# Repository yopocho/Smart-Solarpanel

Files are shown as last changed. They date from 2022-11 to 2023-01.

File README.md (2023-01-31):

# Smart Solarpanel Controller

This project contains the files for a device and housing that enables a solarpanel to control the MPPT of ten different sections of the same solarpanel to improve efficiency in partially-shaded conditions. This device is a self-contained version of a prototype S. Zahra Mirbagheri Golroodbari created for their PhD [dissertation](https://www.mdpi.com/1996-1073/11/1/250) on creating a better and more efficient solarpanel, in which she has succeded. 

On behalf of the Univerity of Utrecht, created at the Univeristy of Applied Sciences Utrecht.

## Electronics

### PCB

The PCB is designed in Kicad. It's rated to handle atleast 10A of current with an MPP output of 29,41V (221.75W).

To find the MPPT for each of the ten sections a dedicated LTM4611EV Buck-converter with INA226 and supporting components are used. They are controlled by a central STM32F103C8T6 microcontroller.

Programming the microcontroller is done through SWD via the provided 2.54mm pitch pins besides it.

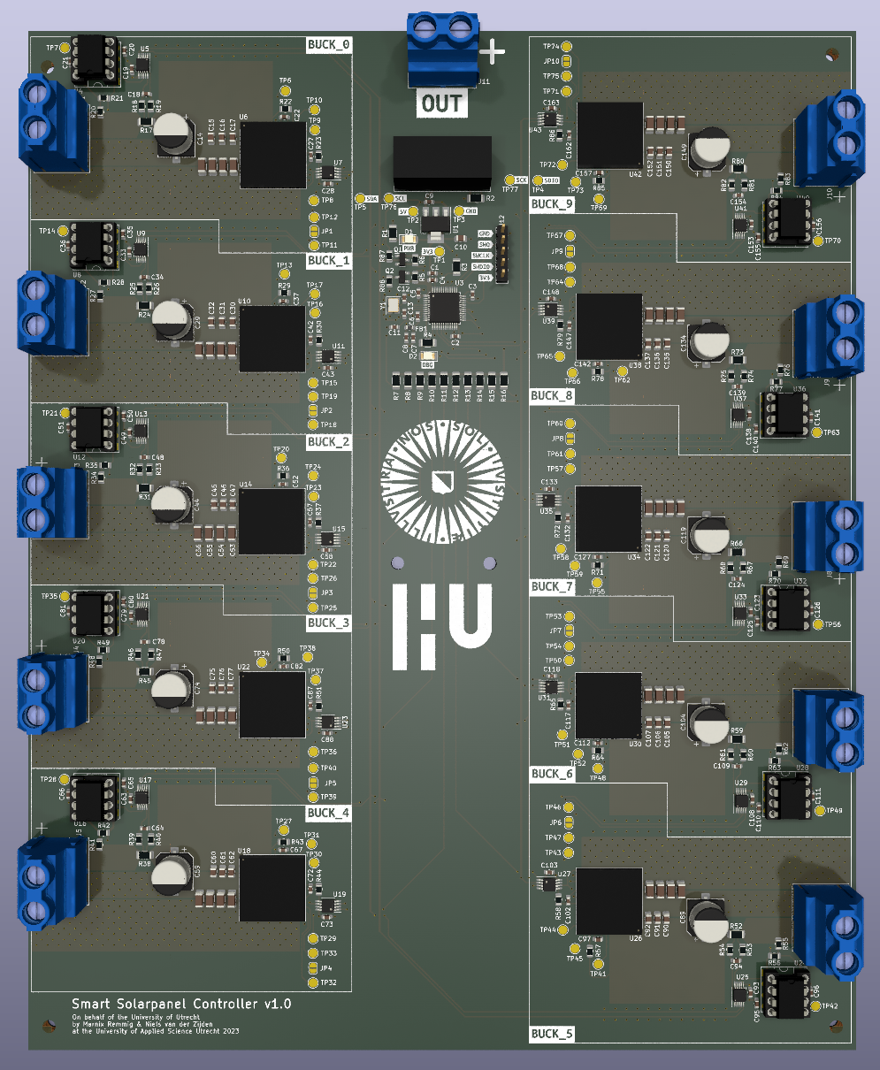
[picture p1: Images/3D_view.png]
3D Model of the PCB


### Firmware

The code for the microcontroller has at this moment not been written yet. The pinout and external crystal were determined by using CubeIDE as a tool to assist in layout, which can be used further to develop the firmware for the device.

## Mechanicals

The mechanical enclosure was calculated using Solidworks Simulation software to make sure it does not exceed the maximum allowed temperature of 70 degrees Celsius. For this reason the enclosure is made out of aluminium.

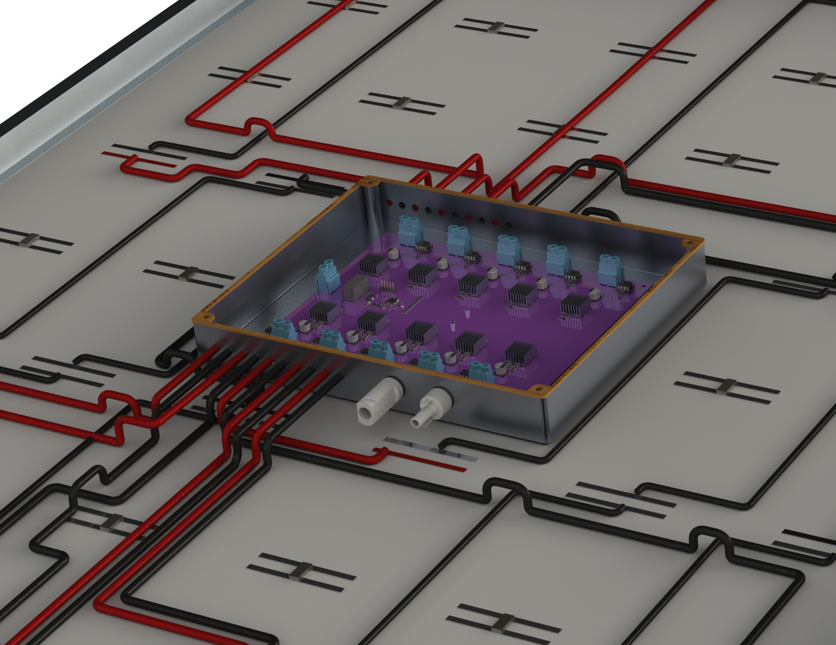
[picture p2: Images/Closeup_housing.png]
3D model closeup of the PCB housing


### Connections

The electrical connections are made using copper wire, as it is cheap and the resistance is low. Since a lot more of the cells are wired in parallel than in a conventional panel, thicker wire must be used to keep the losses under 2%. The wires are routed to the central PCB, where the MPP is calculated and everything is controlled.

The enclosure is waterproof with an IP65 rating. It is glued to the back of the panel. Several panels can be connected in series using standard connectors.

## Use

The provided files can be used as template to retrofit a classic solarpanel into a smart solarpanel. The PCB can be ordered and assembled, after which it can be fitted to the solar panel in the custom housing. 

## Built With

* [Kicad](https://www.kicad.org/) - EDA
* [STM32CubeIDE](https://www.st.com/en/development-tools/stm32cubeide.html) - IDE 
* [SolidWorks](https://www.solidworks.com/) - CAD

## Authors

* **Niels van der Zijden** - [Yopocho](https://github.com/yopocho)
* **Marnix Remmig** 
* **Teun Drijfhout** 
* **Silas Witmond** 

## License

This project is licensed under the MIT License

## Acknowledgments

* **Dr. Sara Mirbagheri Golroodbari** - Commisioner
* **Joost Kouijzer** - Group supervisor during this project
* **Marcel** - For letting our group use his lab during the project

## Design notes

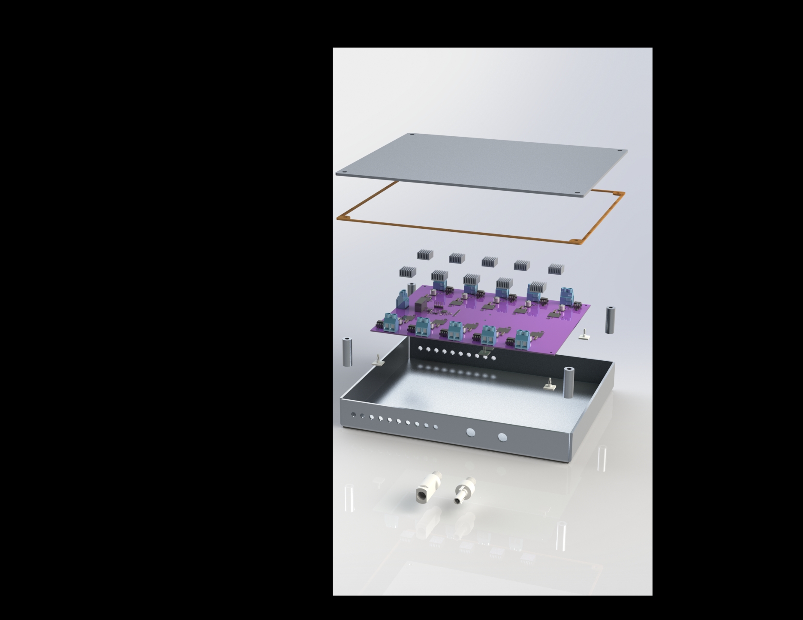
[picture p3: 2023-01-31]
Images/Housing exploded view.JPG

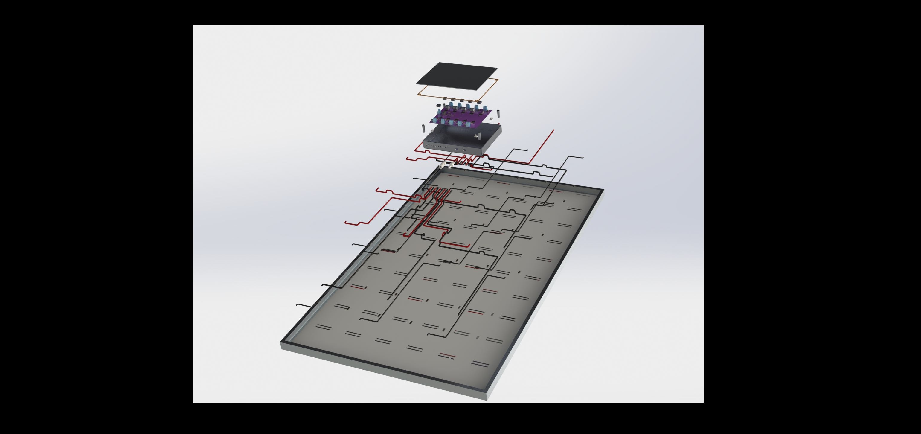
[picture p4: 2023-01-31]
Images/Exploded whole panel.JPG

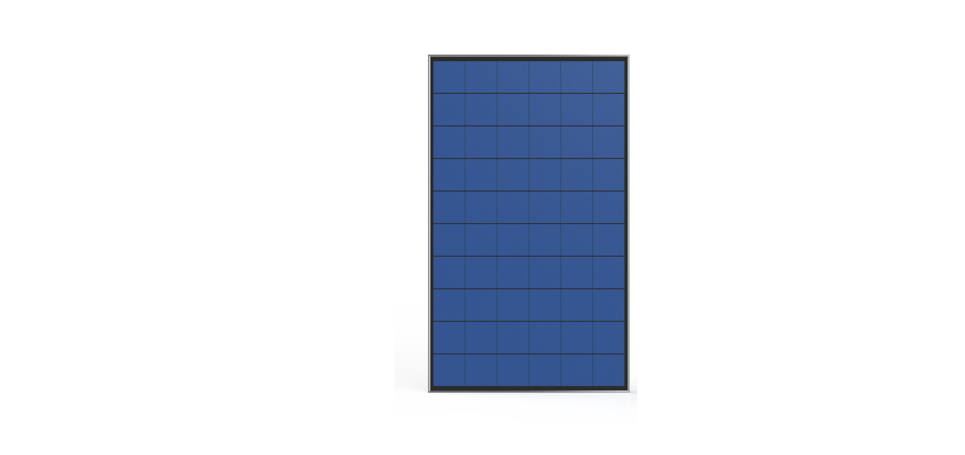
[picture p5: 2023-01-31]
Images/Front of panel.png

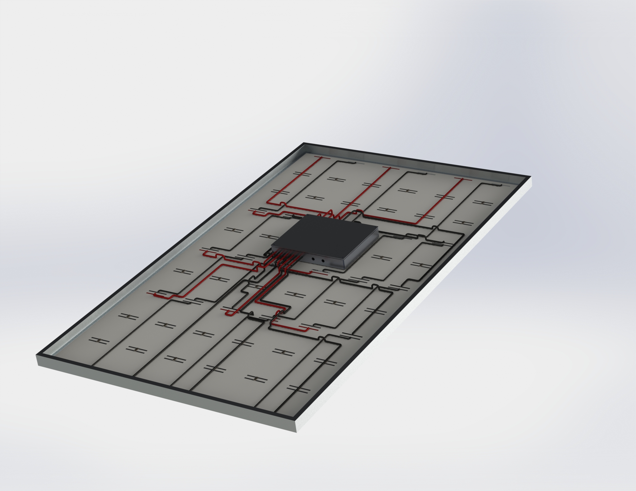
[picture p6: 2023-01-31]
Images/Whole panel.JPG

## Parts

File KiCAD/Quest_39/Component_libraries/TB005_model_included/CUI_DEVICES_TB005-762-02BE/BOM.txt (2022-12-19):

3DX_CUI_DEVICES_Supplier: CUI Devices
3DX_CUI_DEVICES_Part Number: TB005-762-02BE
3DX_CUI_DEVICES_Description: 2~24 Poles, Screw Type, Horizontal, 7.62 Pitch, 26-10 (AWG), Terminal Block Connector

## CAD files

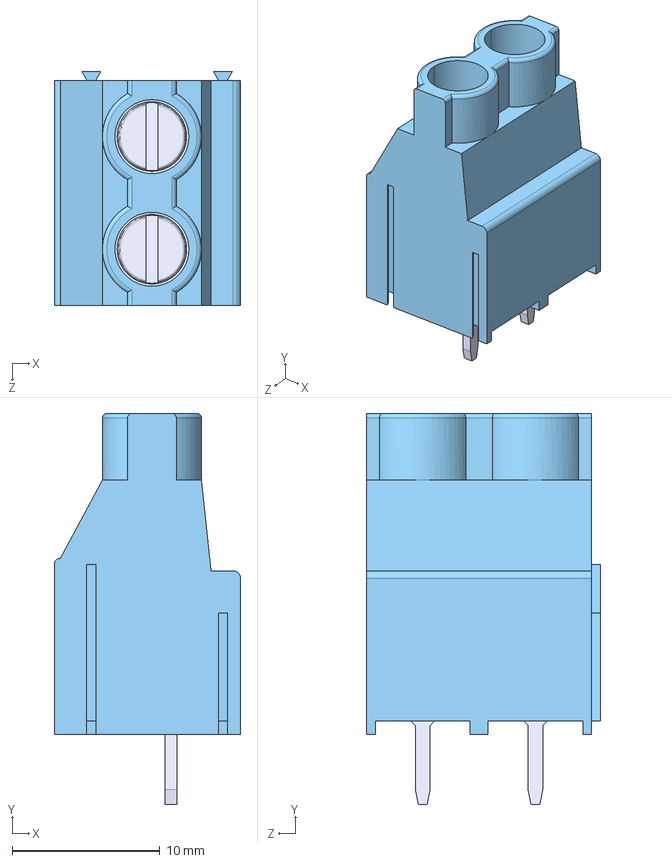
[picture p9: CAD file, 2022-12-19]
KiCAD/Quest_39/Component_libraries/TB005_model_included/CUI_DEVICES_TB005-762-02BE/CUI_DEVICES_TB005-762-02BE.step
12.6 x 26.5 x 15.8 mm

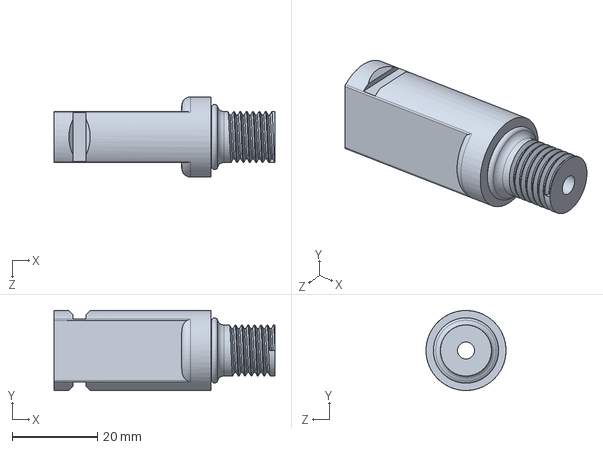
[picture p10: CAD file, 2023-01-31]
SolidWorks/MC4 female connector.SLDPRT
51.9 x 18.8 x 18.8 mm

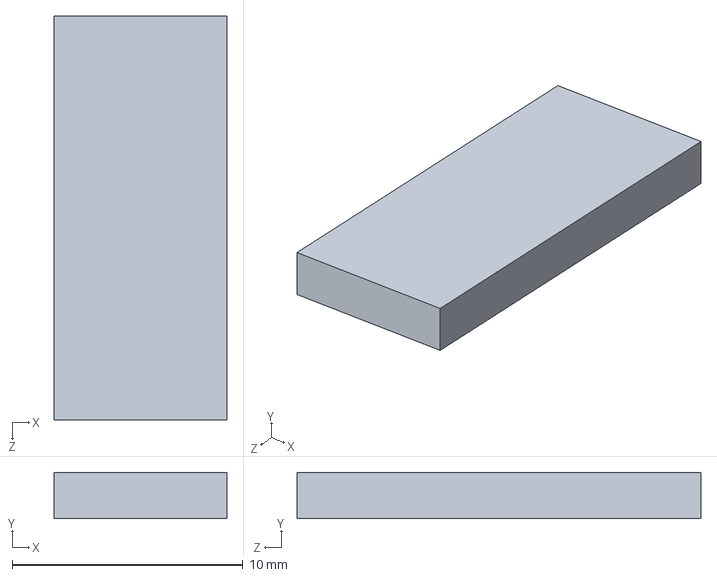
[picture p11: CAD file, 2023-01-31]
SolidWorks/17.5x7.5x2.SLDPRT
7.50 x 2.00 x 17.5 mm

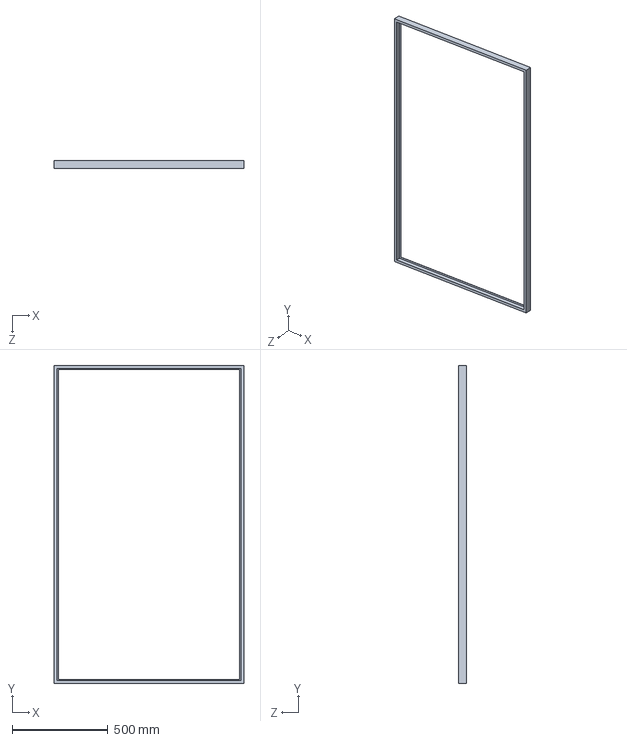
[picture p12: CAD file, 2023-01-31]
SolidWorks/frame van het paneel.SLDPRT
990.0 x 1658.0 x 42.0 mm

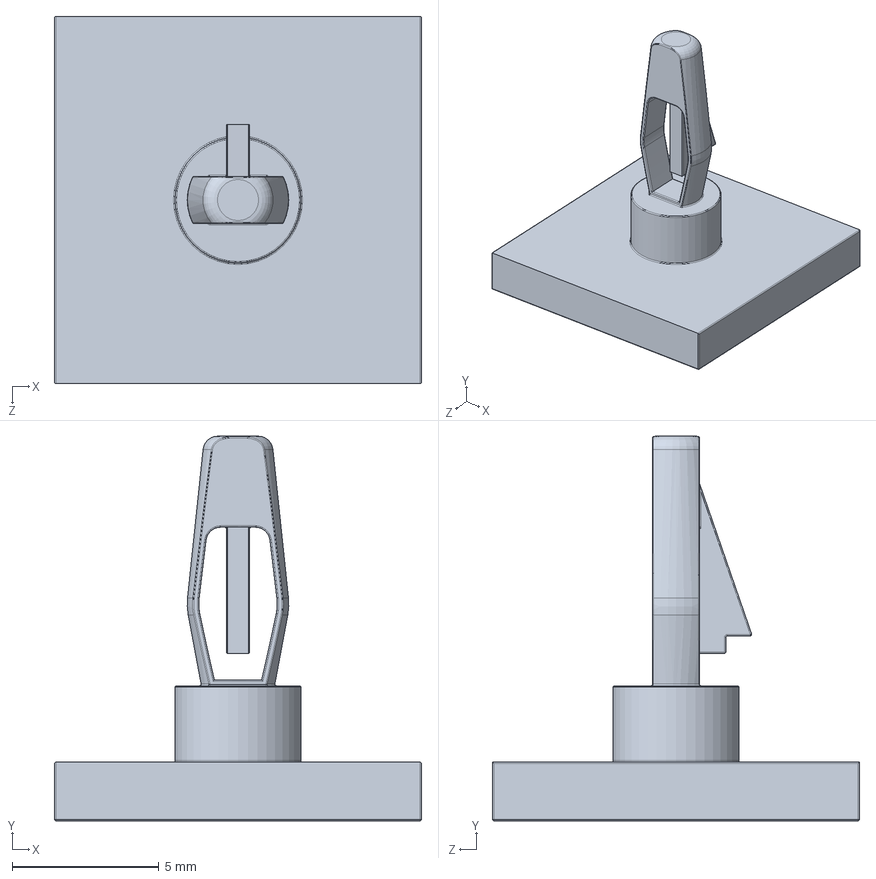
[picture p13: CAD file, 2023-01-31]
SolidWorks/pcb steun.SLDPRT
12.5 x 13.1 x 12.5 mm

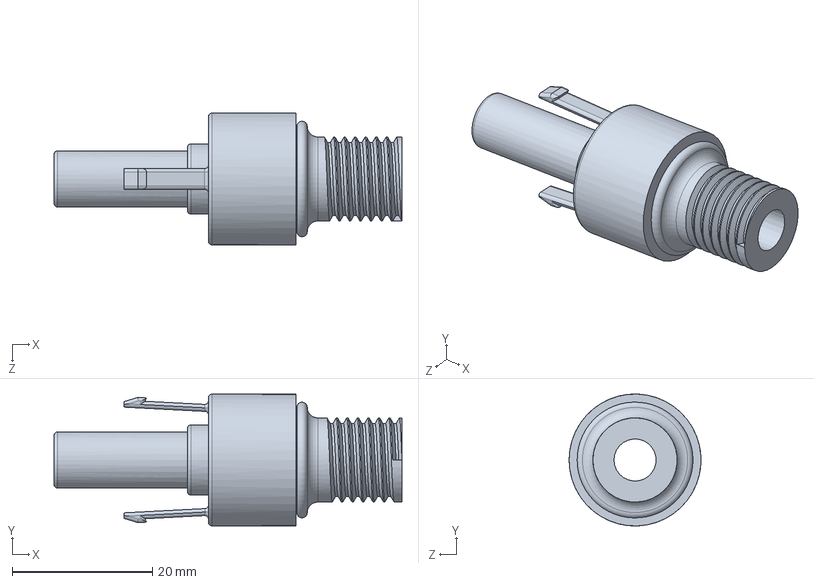
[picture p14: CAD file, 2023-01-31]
SolidWorks/MC4 male connector.SLDPRT
49.6 x 18.8 x 18.8 mm

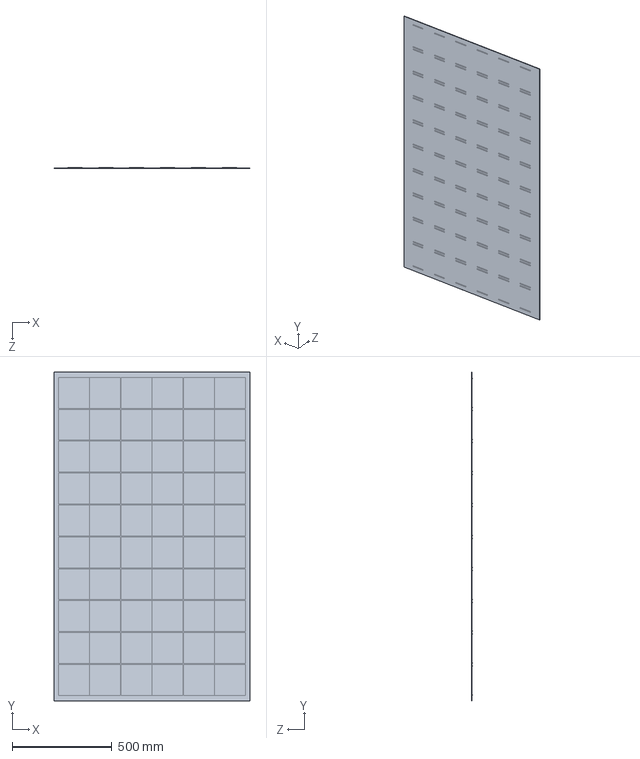
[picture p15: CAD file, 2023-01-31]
SolidWorks/paneel.SLDPRT
980.0 x 1648.0 x 3.50 mm

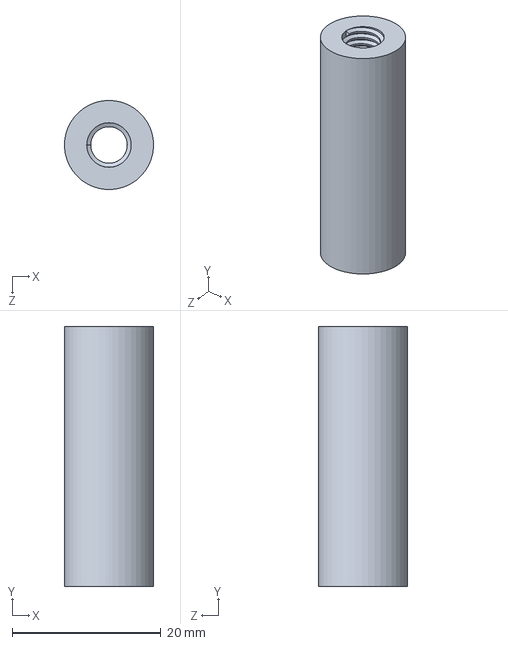
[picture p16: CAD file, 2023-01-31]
SolidWorks/bus met schroefdraad.SLDPRT
12.0 x 35.0 x 12.0 mm

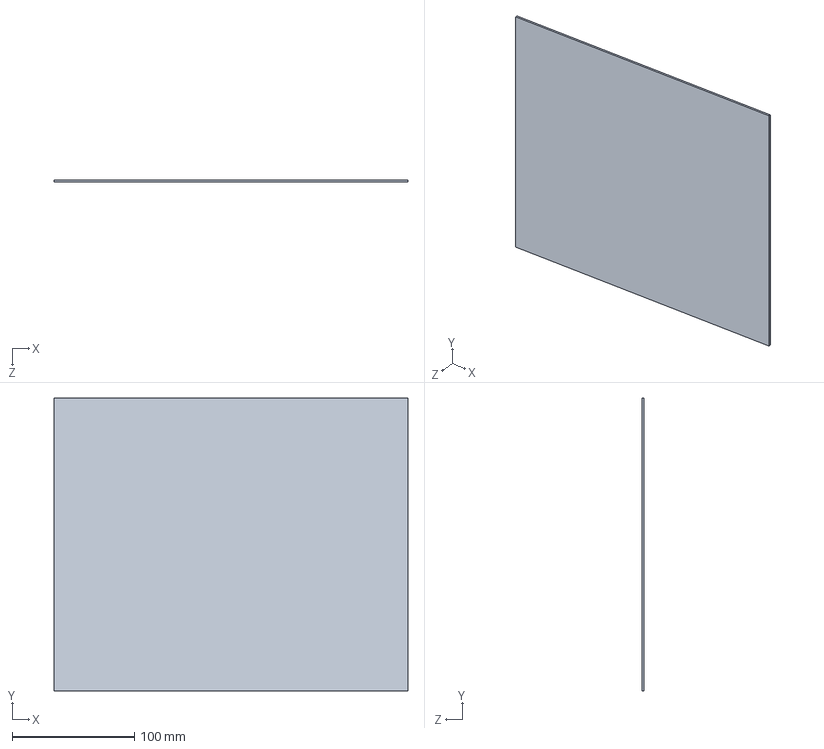
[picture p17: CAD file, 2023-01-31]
SolidWorks/Part8.SLDPRT
290.0 x 240.0 x 2.00 mm

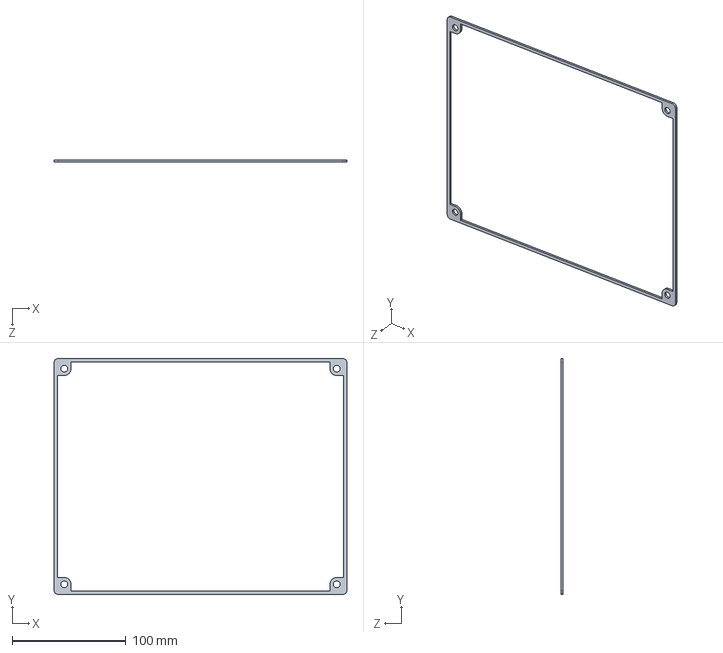
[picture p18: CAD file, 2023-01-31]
SolidWorks/pakking.SLDPRT
257.5 x 207.5 x 2.00 mm

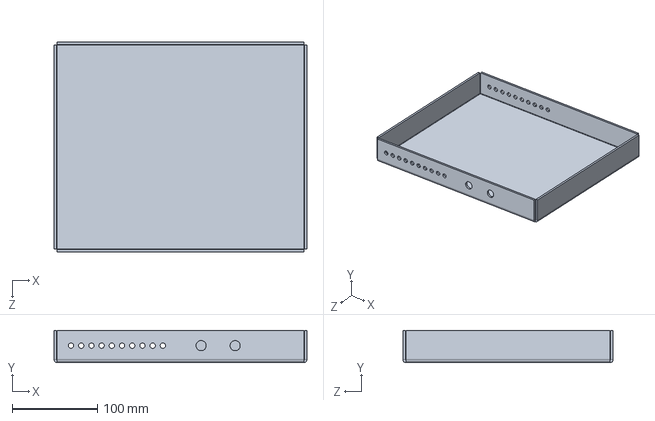
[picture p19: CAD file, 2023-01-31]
SolidWorks/bakje.SLDPRT
297.5 x 38.0 x 247.5 mm

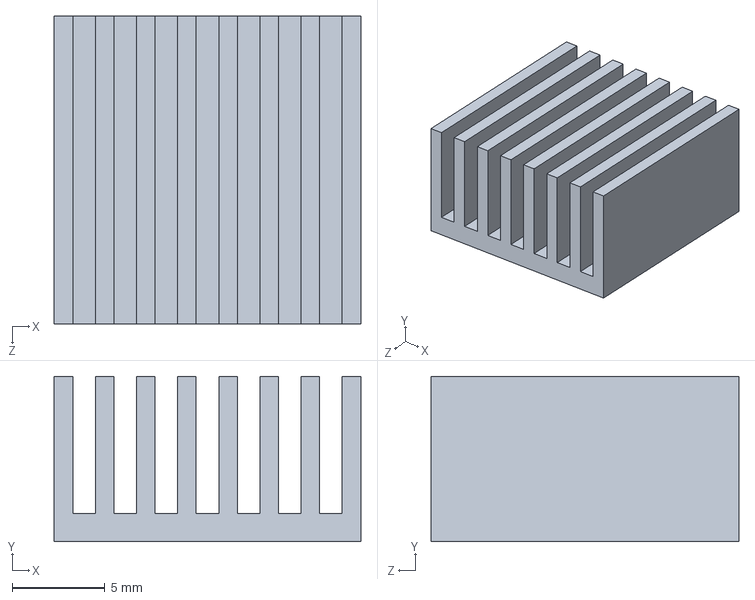
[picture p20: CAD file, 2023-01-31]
SolidWorks/heatsink.SLDPRT
16.5 x 8.89 x 16.6 mm

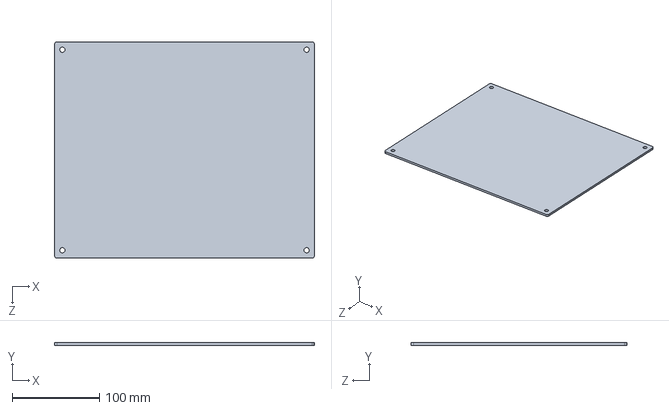
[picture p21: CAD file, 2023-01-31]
SolidWorks/deksel.SLDPRT
297.5 x 3.00 x 247.5 mm

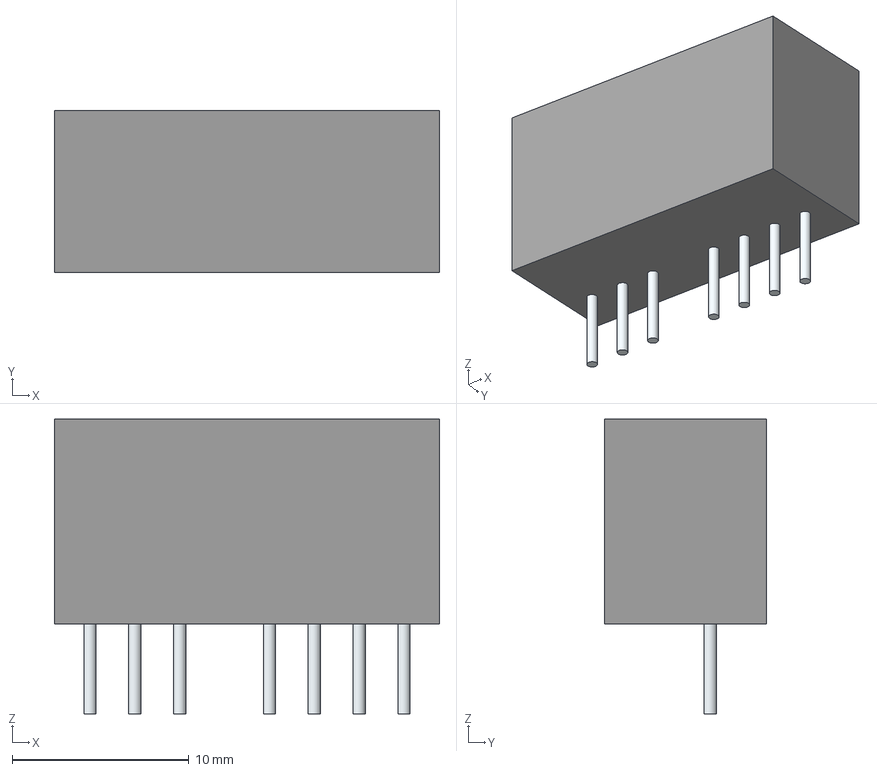
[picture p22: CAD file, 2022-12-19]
KiCAD/Quest_39/Component_libraries/LIB_17791063215/17791063215/3D/17791063215.stp
21.8 x 9.20 x 16.7 mm
Leads

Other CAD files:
KiCAD/Quest_39/Component_libraries/LIB_17791063215/17791063215/Allegro/17791063215.psm
KiCAD/Quest_39/Component_libraries/LIB_17791063215/17791063215/DEHDL/17791063215/chips/chips.prt

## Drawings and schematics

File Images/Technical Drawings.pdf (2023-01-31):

ITEM NO. | PART NUMBER | DESCRIPTION | QTY.
1 | 001 | frame | 1

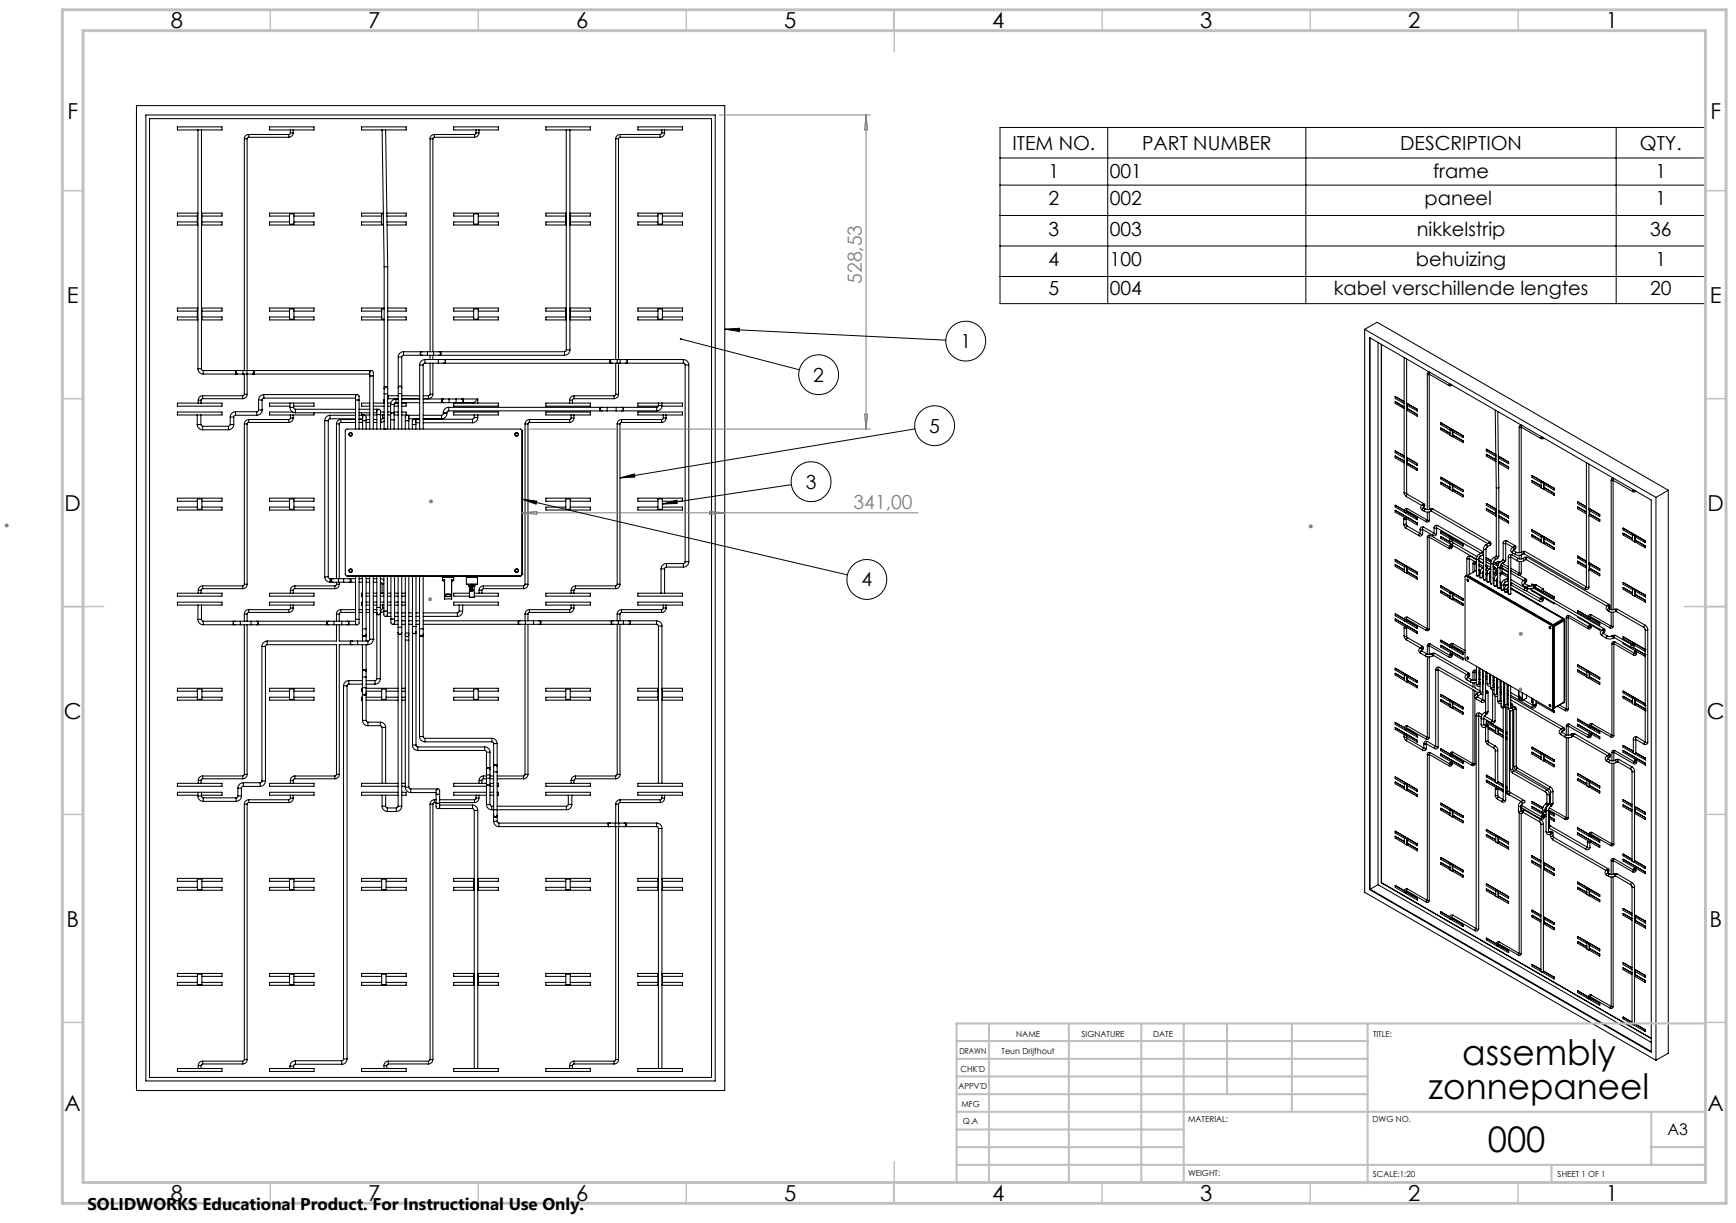
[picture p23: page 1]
SCALE:1:20; SHEET 1 OF 1; WEIGHT:

2 | 002 | paneel | 1
3 | 003 | nikkelstrip | 36
4 | 100 | behuizing | 1
5 | 004 | kabel verschillende lengtes | 20

NAME | SIGNATURE | DATE | | | | TITLE: assembly zonnepaneel

DRAWN | Teun Drijfhout
CHK'D
APPV'D
MFG
Q.A | | | | MATERIAL: | DWG NO. | A3

SOLIDWORKS Educational Product. For Instructional Use Only.

| ITEM NO. | PART NUMBER | DESCRIPTION | QTY.
| 1 | 101 | bakje | 1

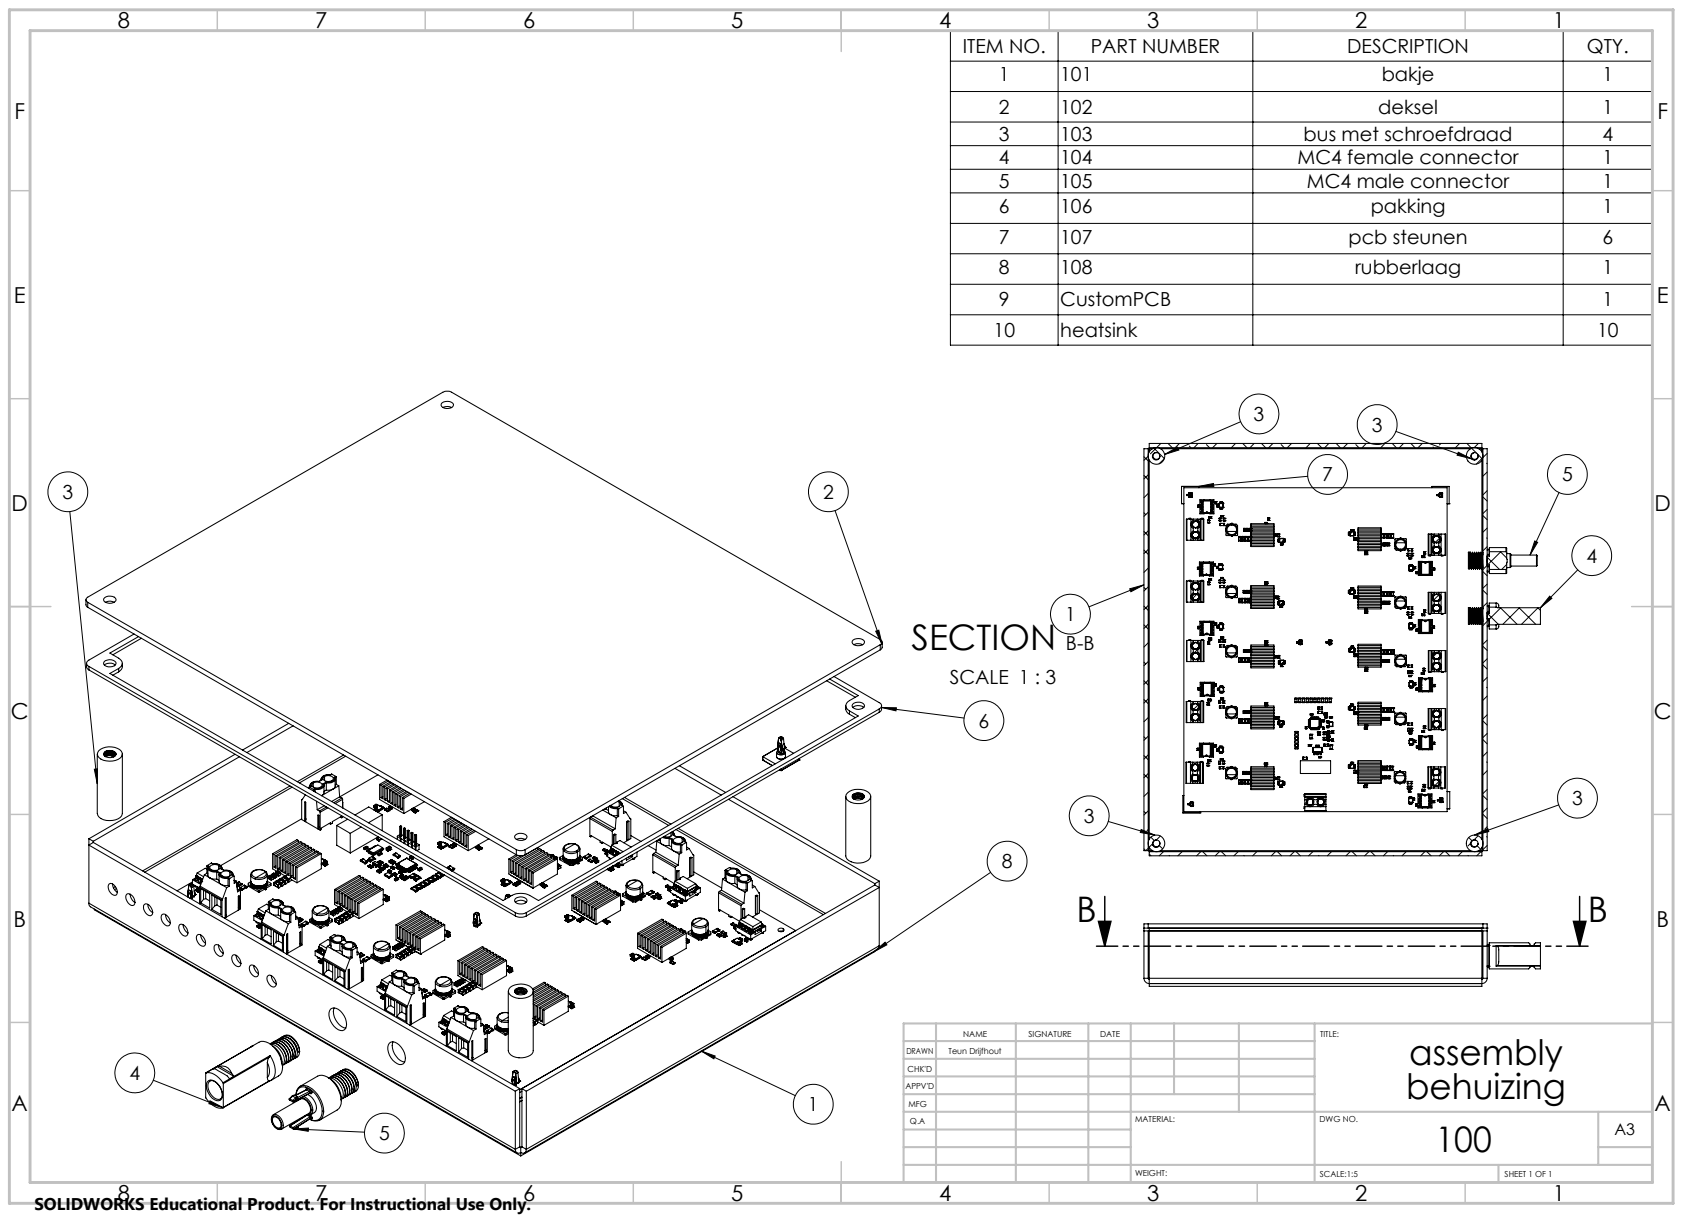
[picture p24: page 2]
SECTION B-B; SCALE 1 : 3; SCALE:1:5; SHEET 1 OF 1

2 | 102 | deksel | 1
3 | 103 | bus met schroefdraad | 4
4 | 104 | MC4 female connector | 1
5 | 105 | MC4 male connector | 1

E | 6 | 106 | pakking | 1 | E

7 | 107 | pcb steunen | 6
8 | 108 | rubberlaag | 1
9 | CustomPCB | | 1
10 | heatsink | | 10

NAME | SIGNATURE | DATE | | TITLE: assembly behuizing

DRAWN | Teun Drijfhout
CHK'D
APPV'D
MFG

E | E
F | F

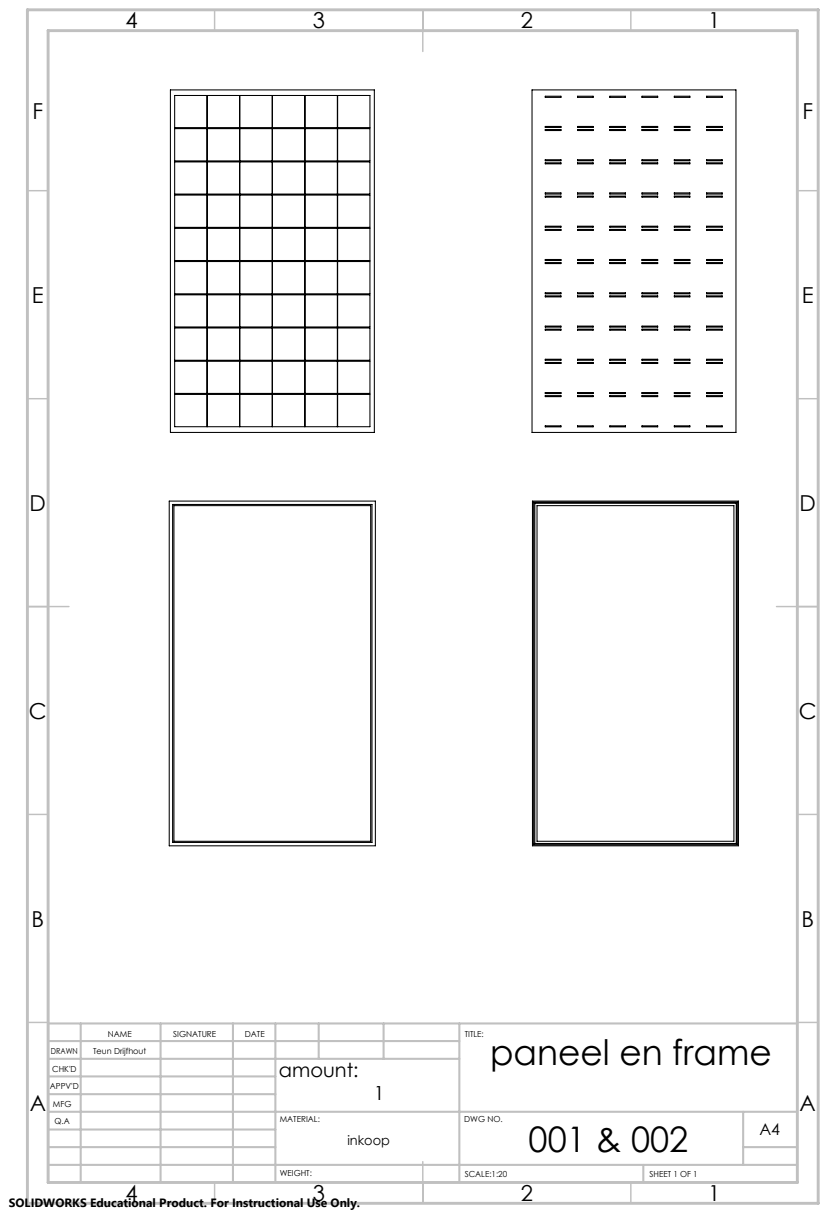
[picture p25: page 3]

NAME | SIGNATURE | DATE | | | | TITLE:

paneel en frame amount:

DRAWN | Teun Drijfhout
CHK'D | | | | 1
APPV'D
MFG

001 & 002 | A4 inkoop

SCALE:1:20 | SHEET 1 OF 1

E | E
F | F

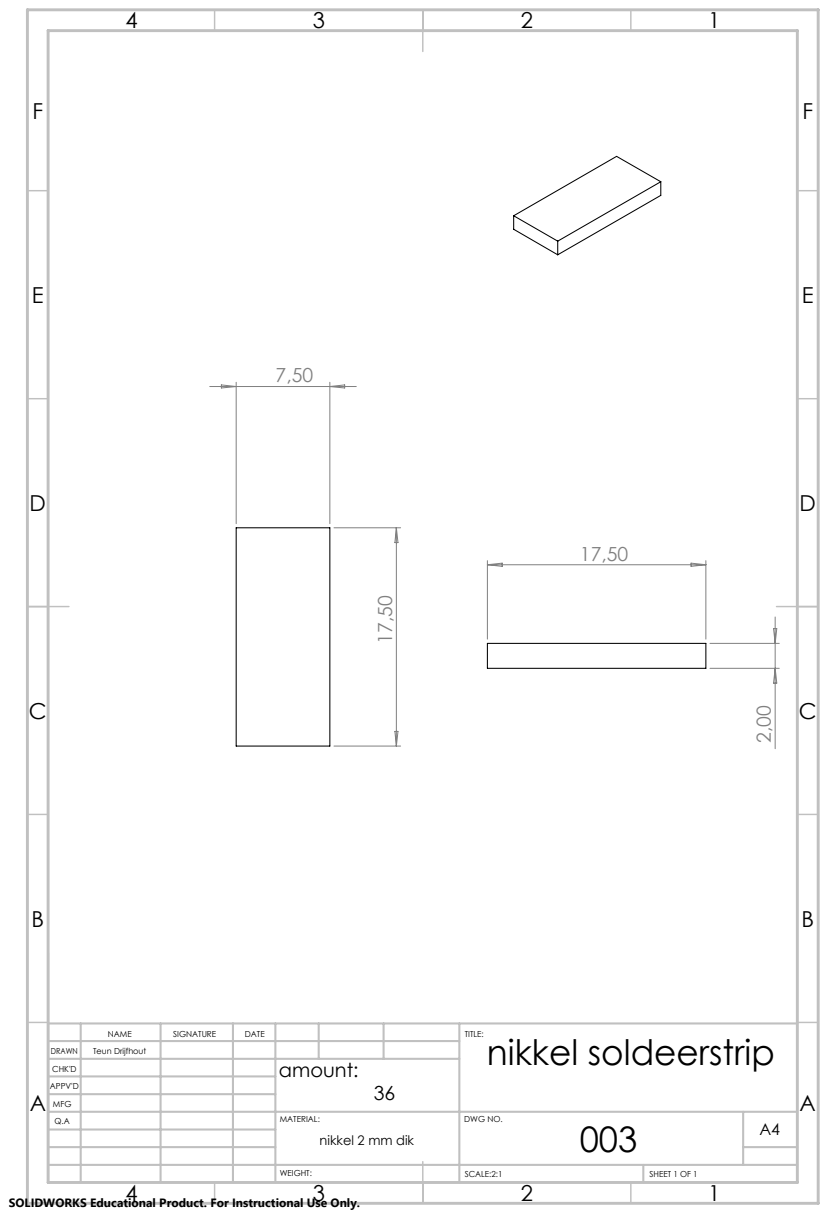
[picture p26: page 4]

NAME | SIGNATURE | DATE | | | TITLE:

nikkel soldeerstrip amount:

DRAWN | Teun Drijfhout
CHK'D | | | | 36
APPV'D
MFG

A4 nikkel 2 mm dik

SCALE:2:1 | SHEET 1 OF 1

316,50
240,00

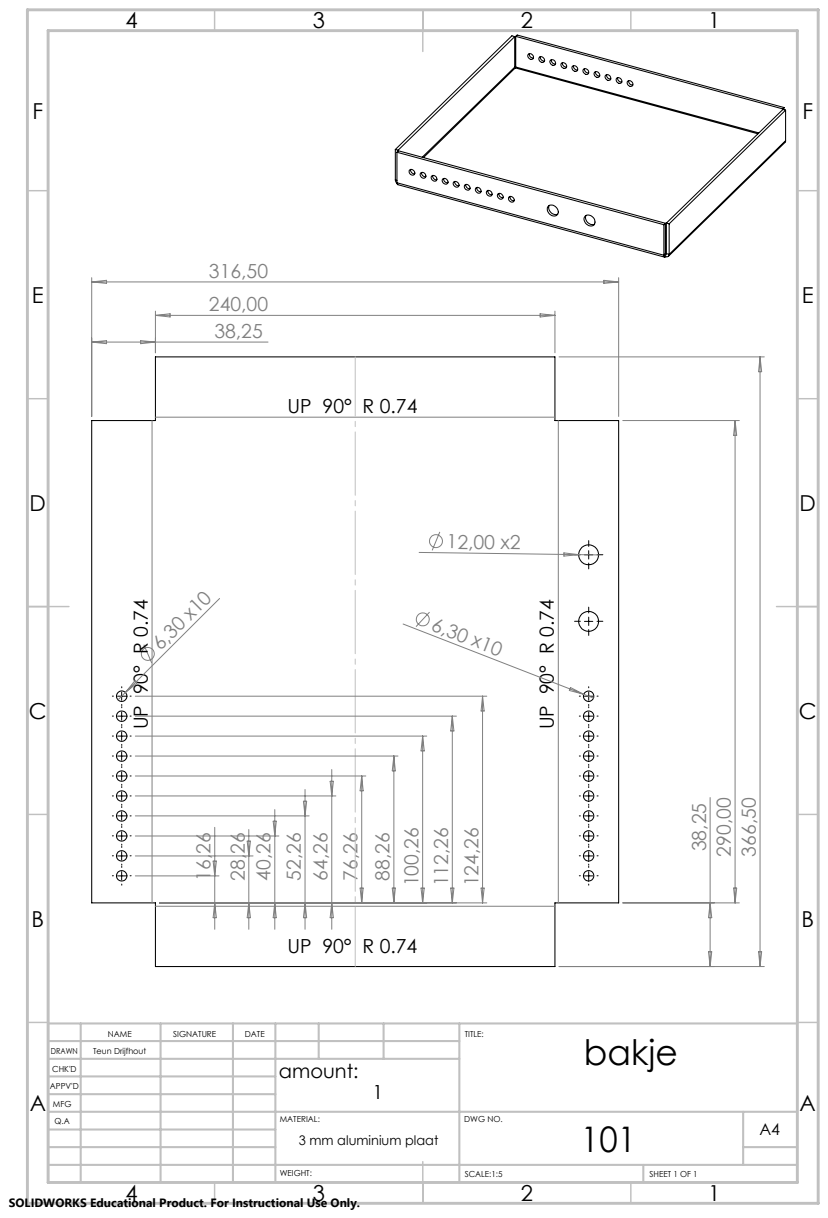
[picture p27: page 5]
bakje amount:

NAME | SIGNATURE | DATE | | | TITLE:

DRAWN | Teun Drijfhout
CHK'D | | | | 1
APPV'D
MFG

A4 3 mm aluminium plaat

E | E
F | F

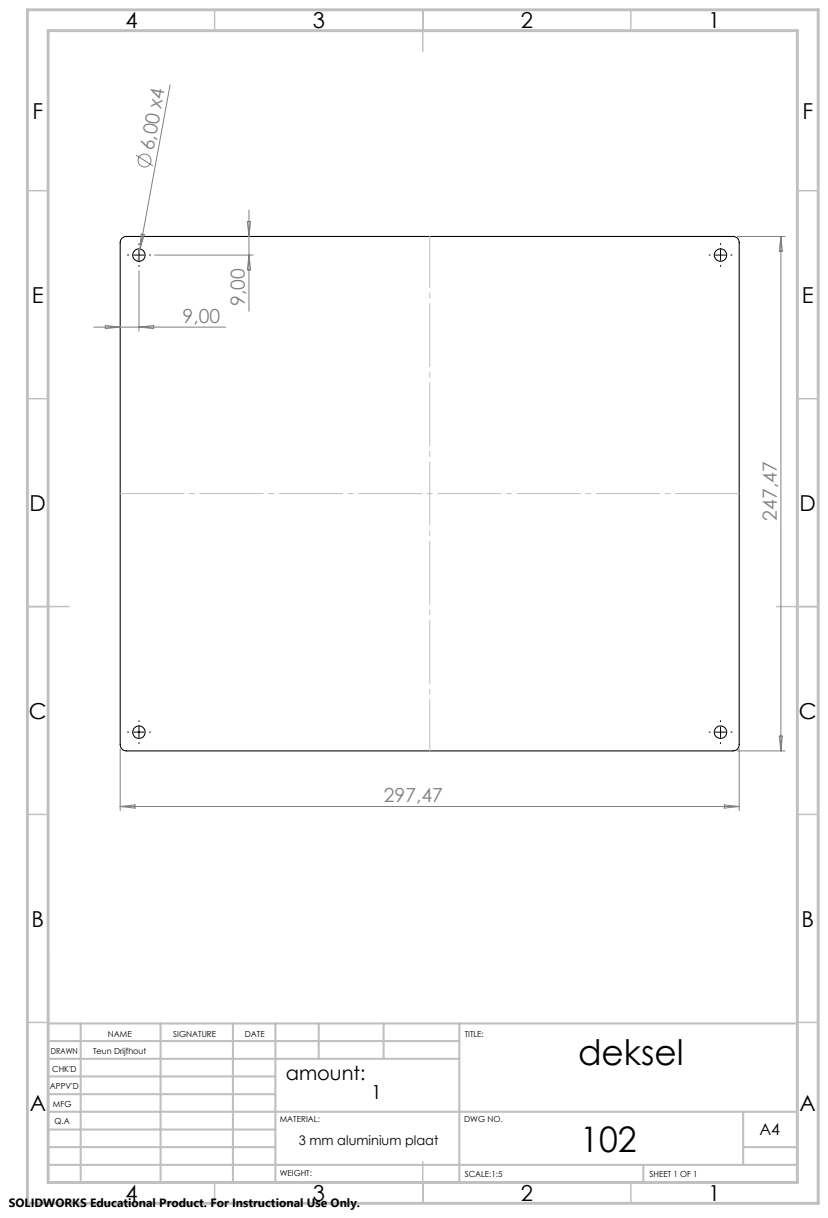
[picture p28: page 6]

NAME | SIGNATURE | DATE | | | TITLE: deksel

DRAWN | Teun Drijfhout
CHK'D | | | | amount: 1
APPV'D
MFG

A4 3 mm aluminium plaat

12,00

E | E

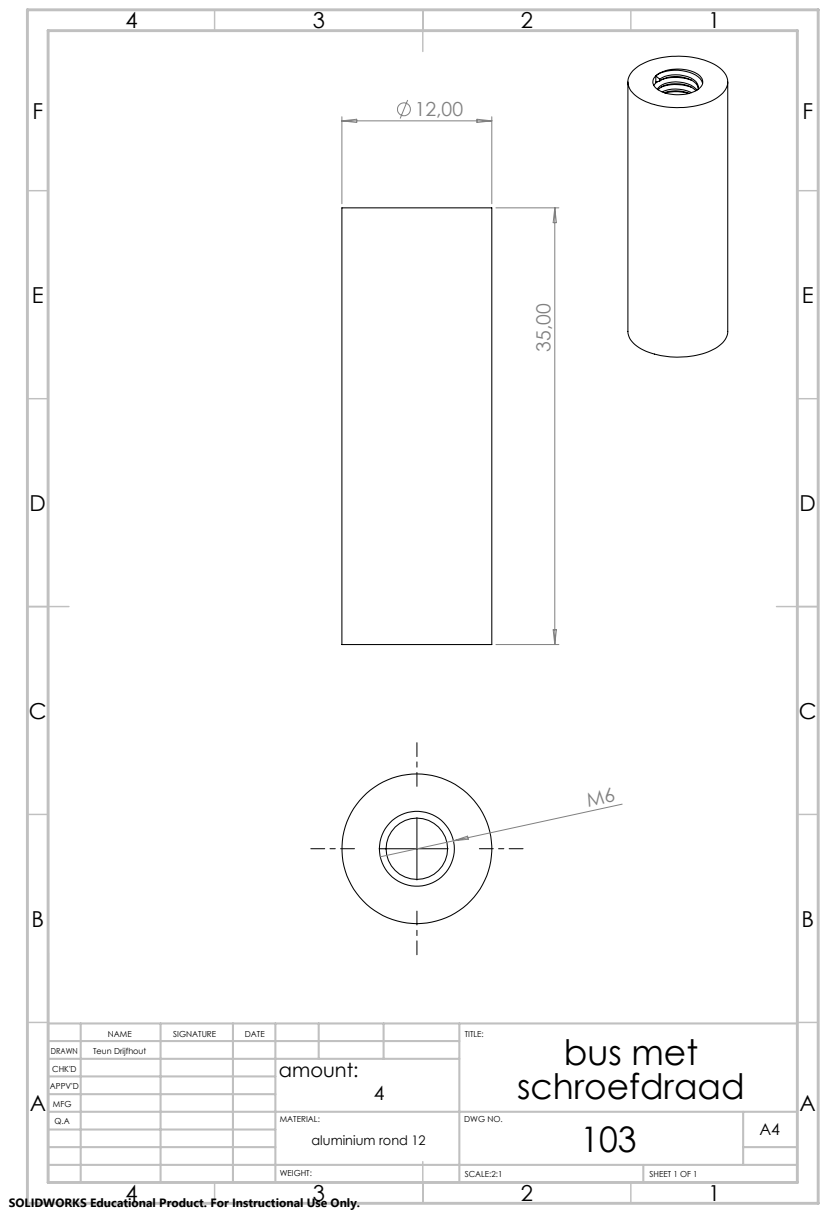
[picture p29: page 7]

NAME | SIGNATURE | DATE | | | TITLE: bus met

DRAWN | Teun Drijfhout
CHK'D | | | | 4 | | schroefdraad amount:

APPV'D
MFG

A4 aluminium rond 12

SCALE:2:1 | SHEET 1 OF 1

E | E
F | F

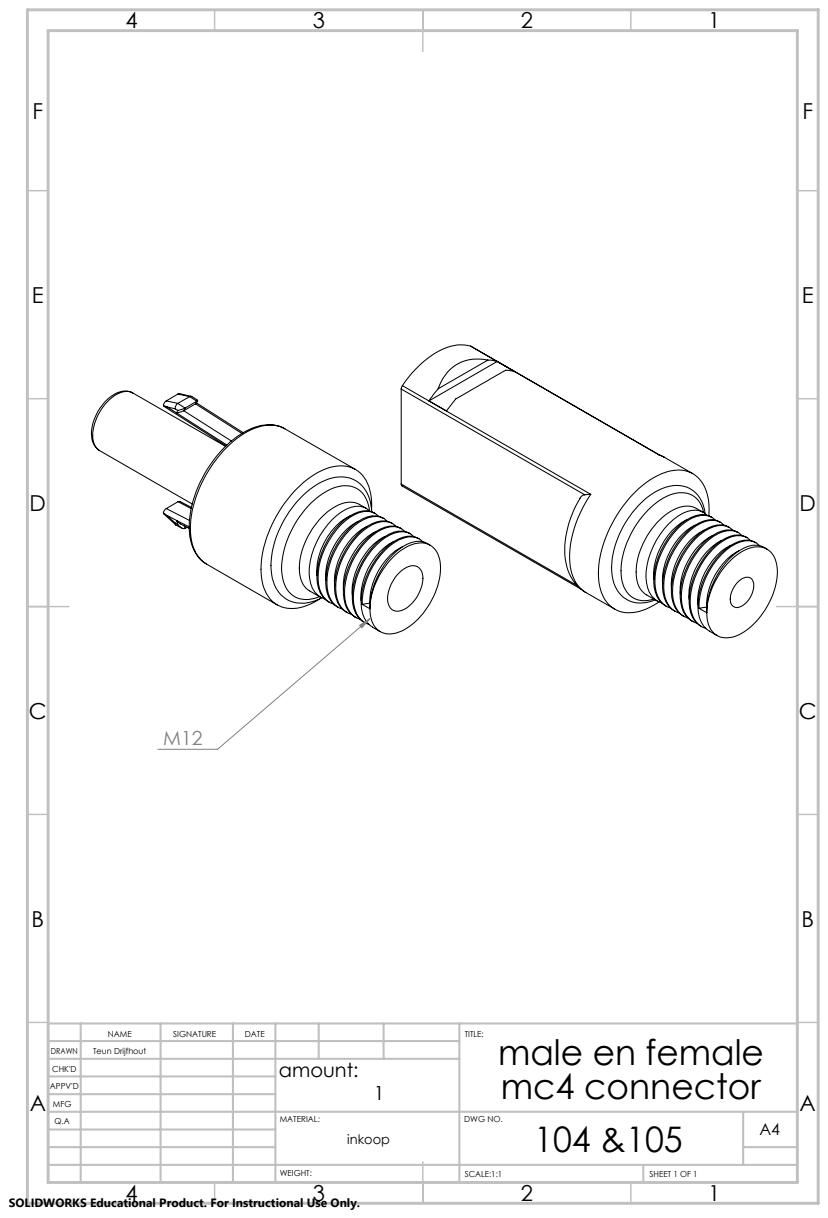
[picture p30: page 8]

NAME | SIGNATURE | DATE | | | | TITLE: male en female

DRAWN | Teun Drijfhout
CHK'D | | | | 1 | | | mc4 connector amount:

APPV'D
MFG

104 &105 | A4 inkoop

SCALE:1:1 | SHEET 1 OF 1

297,47

15,00 15,00

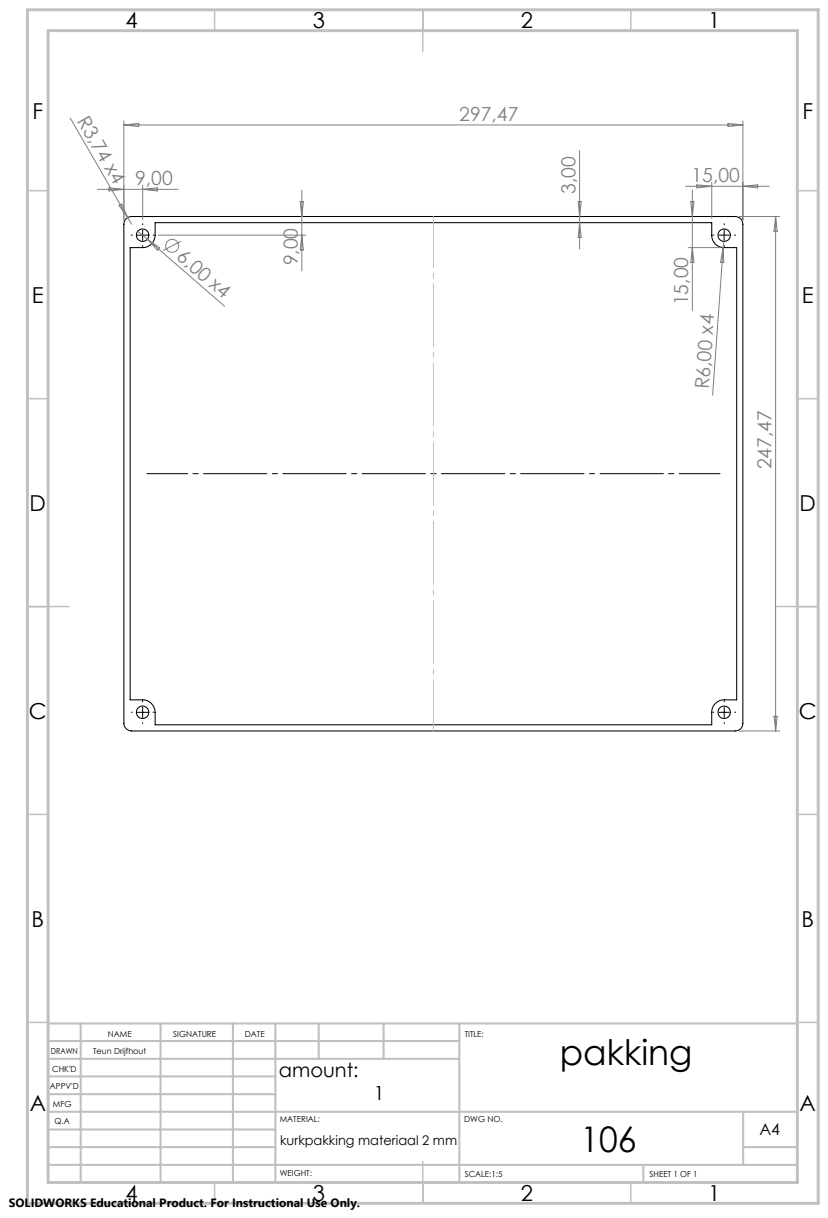
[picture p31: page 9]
pakking amount:

NAME | SIGNATURE | DATE | | | TITLE:

DRAWN | Teun Drijfhout
CHK'D | | | | 1
APPV'D
MFG

A4 kurkpakking materiaal 2 mm

E | E
F | F

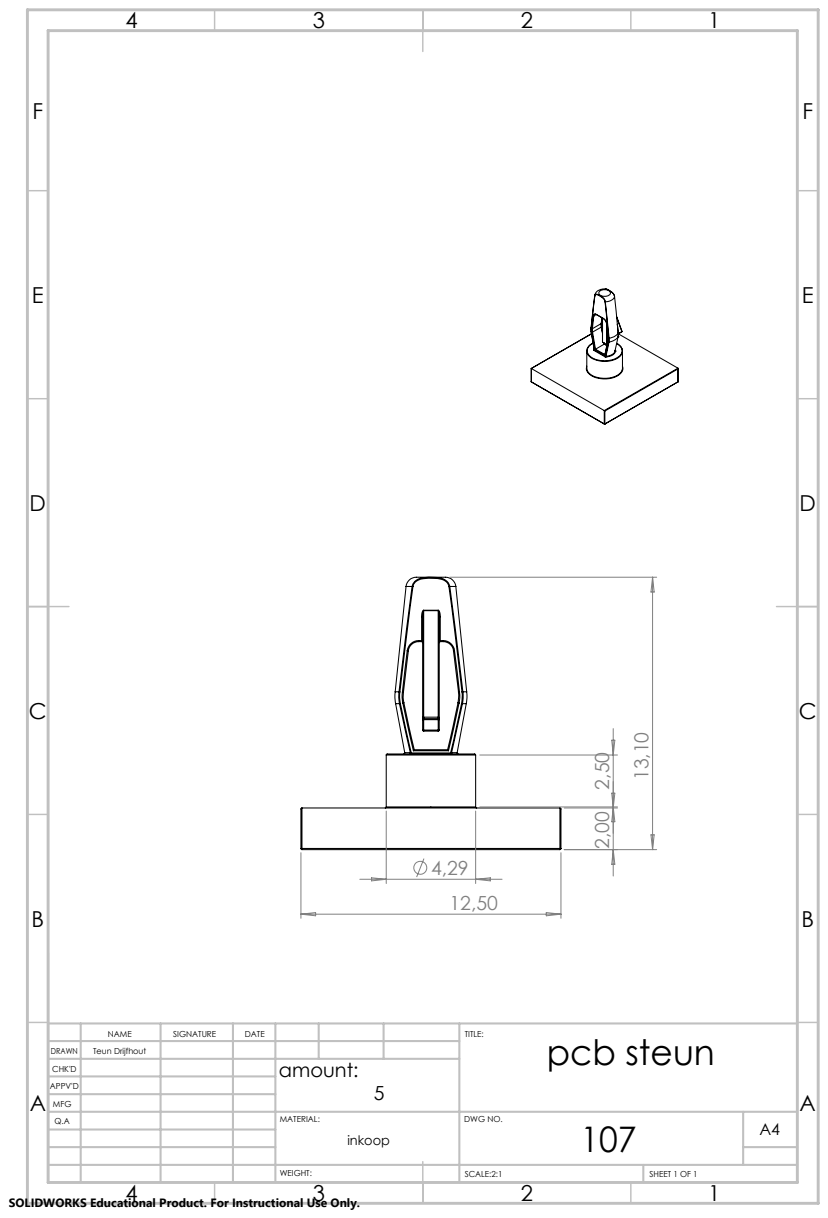
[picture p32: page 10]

NAME | SIGNATURE | DATE | | | TITLE:

pcb steun amount:

DRAWN | Teun Drijfhout
CHK'D | | | | 5
APPV'D
MFG

A4 inkoop

SCALE:2:1 | SHEET 1 OF 1

E | E
F | F

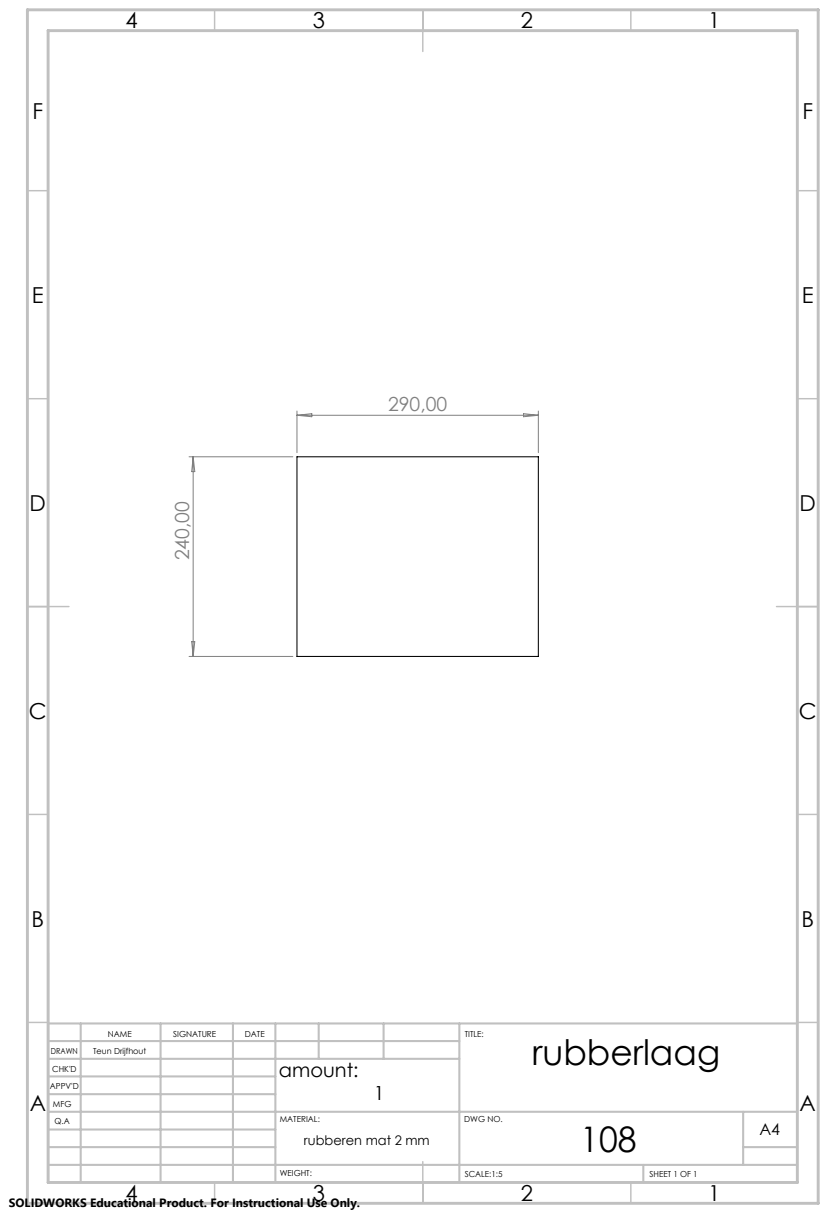
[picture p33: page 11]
rubberlaag amount:

NAME | SIGNATURE | DATE | | | TITLE:

DRAWN | Teun Drijfhout
CHK'D | | | | 1
APPV'D
MFG

rubberen mat 2 mm | A4

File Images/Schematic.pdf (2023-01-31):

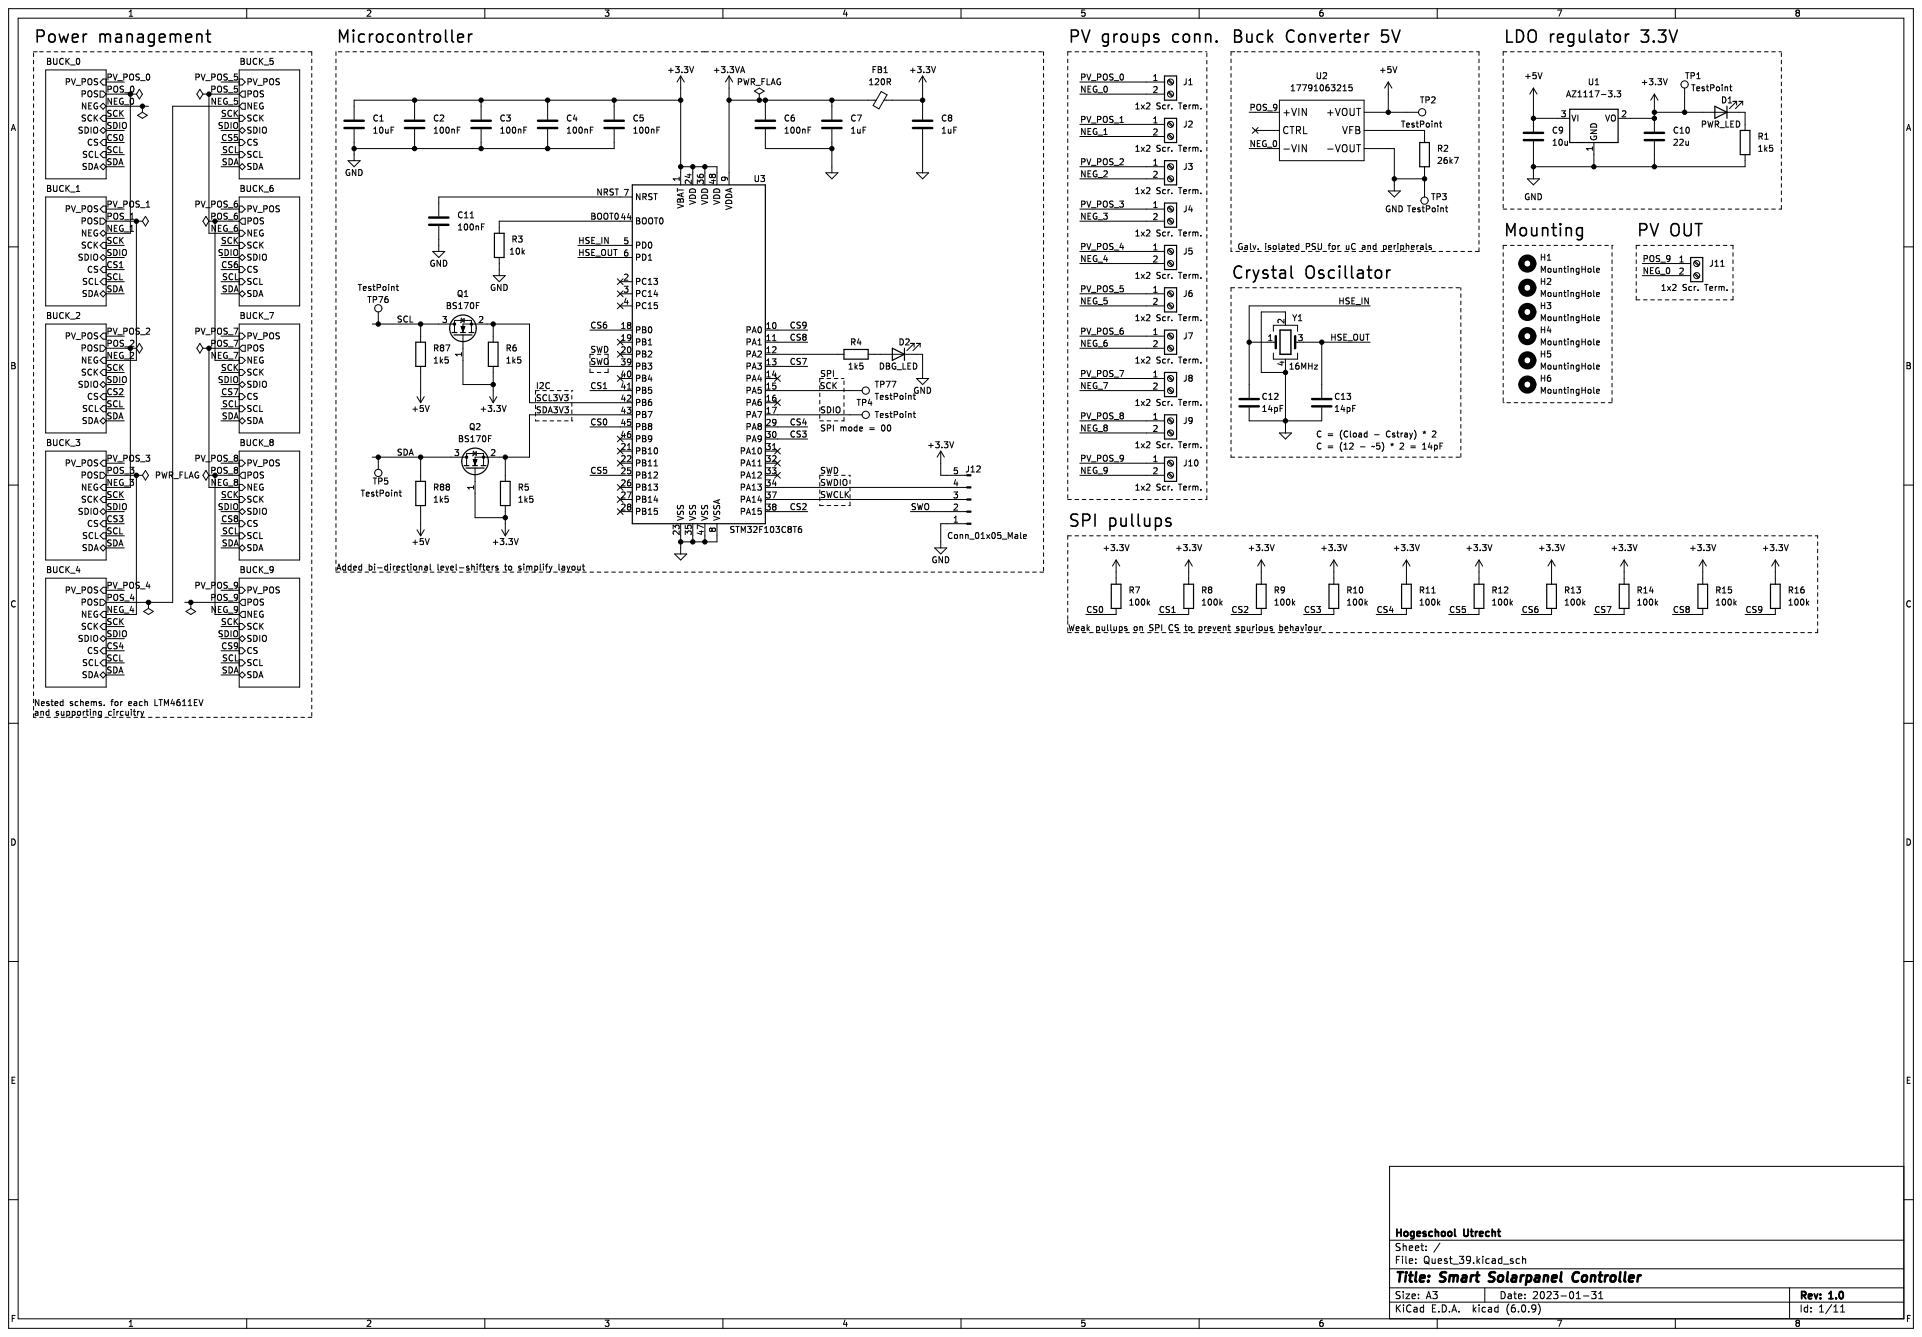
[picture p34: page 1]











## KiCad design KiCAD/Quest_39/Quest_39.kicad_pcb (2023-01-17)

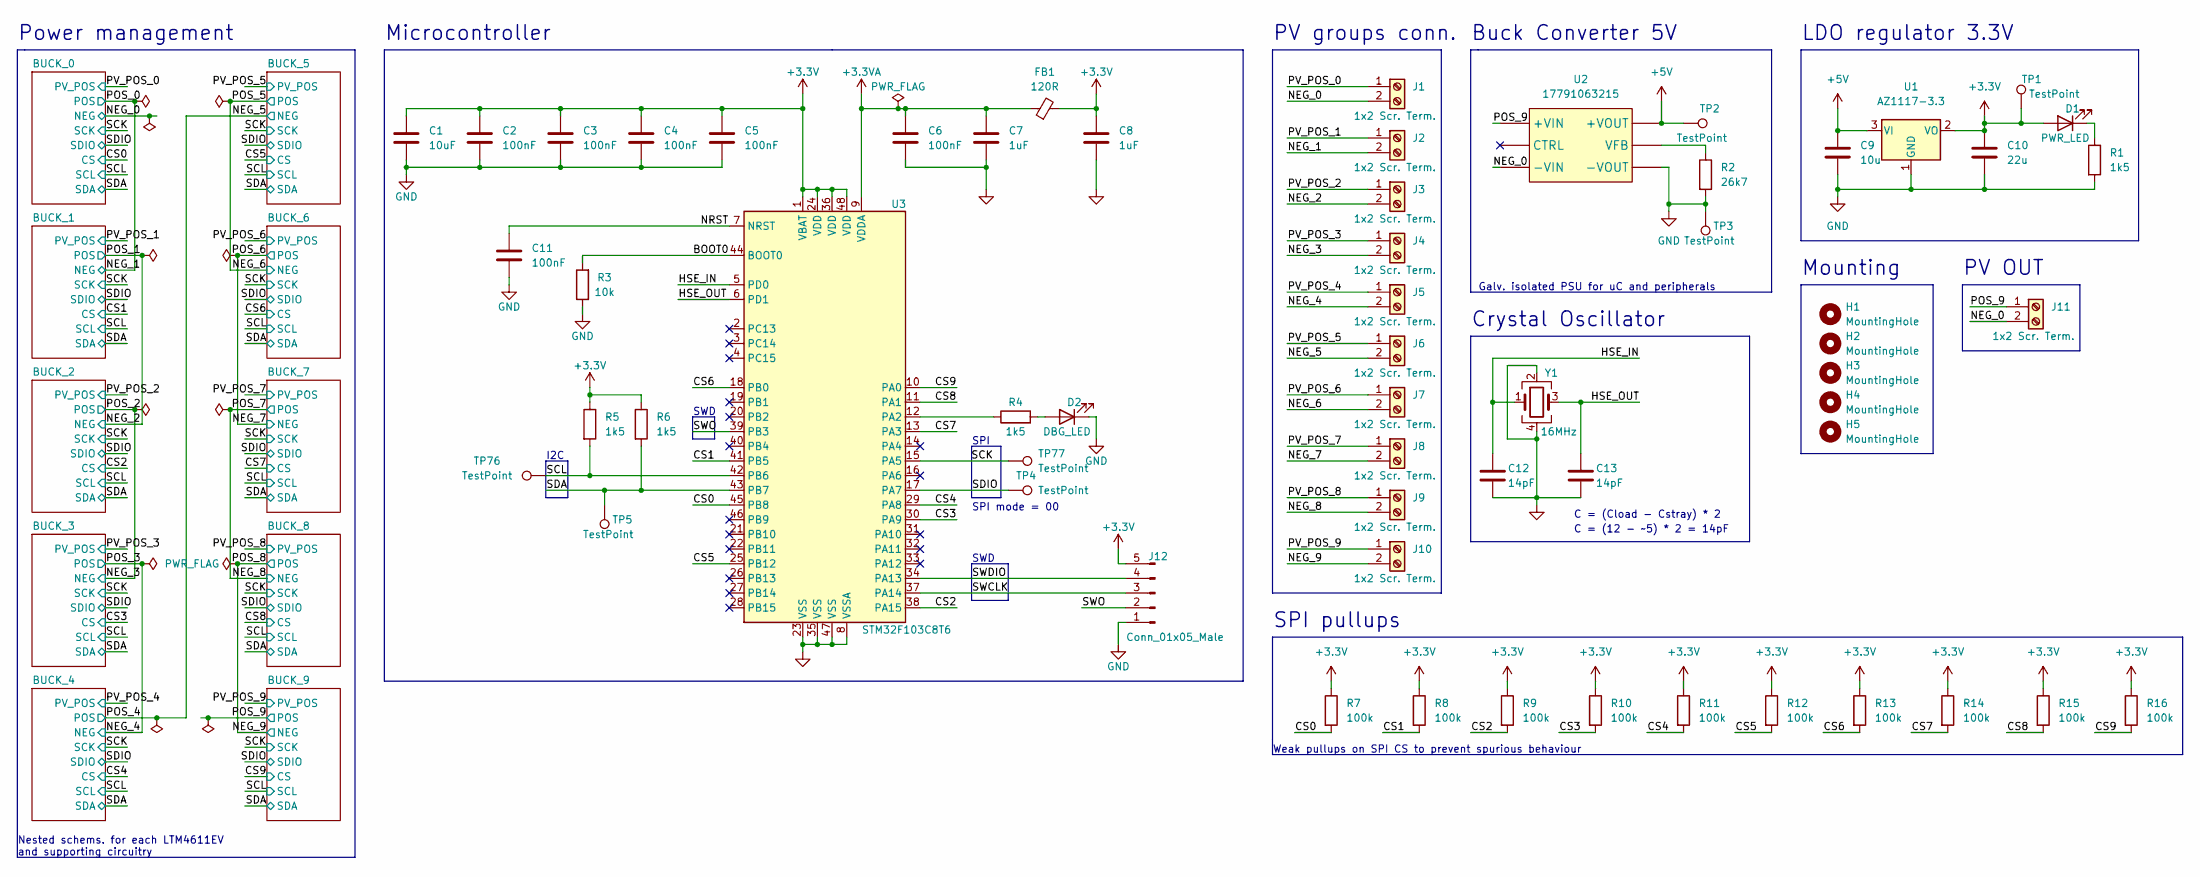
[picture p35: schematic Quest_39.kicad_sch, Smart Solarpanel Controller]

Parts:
C1: 10uF; C_0603_1608Metric
C2, C3, C4, C5, C6, C11: 100nF; C_0603_1608Metric
C7, C8: 1uF; C_0603_1608Metric
C9: 10u; C_0603_1608Metric
C10: 22u; C_0805_2012Metric
C12, C13: 14pF; C_0603_1608Metric
D1: PWR_LED; LED_1206_3216Metric
D2: DBG_LED; LED_1206_3216Metric
FB1: 120R; L_0603_1608Metric
H1, H2, H3, H4, H5: MountingHole; MountingHole_3mm
J1, J2, J3, J4, J5, J6, J7, J8, J9, J10, J11: 1x2 Scr. Term.; TB005-762-02BE
J12: Conn_01x05_Male; PinHeader_1x05_P2.54mm_Vertical
R1, R4, R5, R6: 1k5; R_1206_3216Metric
R2: 26k7; R_1206_3216Metric
R3: 10k; R_1206_3216Metric
R7, R8, R9, R10, R11, R12, R13, R14, R15, R16: 100k; R_1206_3216Metric
TP1, TP2, TP3, TP4, TP5, TP76, TP77: TestPoint; TestPoint_Pad_D2.0mm
U1: AZ1117-3.3; SOT-223-3_TabPin2
U2: 17791063215
U3: STM32F103C8T6; LQFP-48_7x7mm_P0.5mm
Y1: 16MHz; Crystal_SMD_3225-4Pin_3.2x2.5mm

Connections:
+3.3V: C1.1, C2.1, C3.1, C4.1, C5.1, C8.1, C10.1, D1.2 (A), FB1.2, J12.5, R5.1, R6.1, R7.1, R8.1, R9.1, R10.1, R11.1, R12.1, R13.1, R14.1, R15.1, R16.1, TP1.1, U1.2 (VO), U3.1 (VBAT), U3.24 (VDD), U3.36 (VDD), U3.48 (VDD)
+3.3VA: C6.1, C7.1, FB1.1, U3.9 (VDDA)
+5V: C9.1, TP2.1, U1.3 (VI), U2.6 (+VOUT); also elsewhere on the board
/BOOT0: R3.2, U3.44 (BOOT0)
/CS0: R7.2, U3.45 (PB8); also elsewhere on the board
/CS1: R8.2, U3.41 (PB5); also elsewhere on the board
/CS2: R9.2, U3.38 (PA15); also elsewhere on the board
/CS3: R10.2, U3.30 (PA9); also elsewhere on the board
/CS4: R11.2, U3.29 (PA8); also elsewhere on the board
/CS5: R12.2, U3.25 (PB12); also elsewhere on the board
/CS6: R13.2, U3.18 (PB0); also elsewhere on the board
/CS7: R14.2, U3.13 (PA3); also elsewhere on the board
/CS8: R15.2, U3.11 (PA1); also elsewhere on the board
/CS9: R16.2, U3.10 (PA0); also elsewhere on the board
/HSE_IN: C12.1, U3.5 (PD0), Y1.1
/HSE_OUT: C13.1, U3.6 (PD1), Y1.3
/NEG_0: J1.2, J11.2, U2.1 (-VIN); also elsewhere on the board
/NEG_1: J2.2; also elsewhere on the board
/NEG_2: J3.2; also elsewhere on the board
/NEG_3: J4.2; also elsewhere on the board
/NEG_4: J5.2; also elsewhere on the board
/NEG_5: J6.2; also elsewhere on the board
/NEG_6: J7.2; also elsewhere on the board
/NEG_7: J8.2; also elsewhere on the board
/NEG_8: J9.2; also elsewhere on the board
/NEG_9: J10.2; also elsewhere on the board
/NRST: C11.1, U3.7 (NRST)
/POS_9: J11.1, U2.2 (+VIN); also elsewhere on the board
/PV_POS_0: J1.1; also elsewhere on the board
/PV_POS_1: J2.1; also elsewhere on the board
/PV_POS_2: J3.1; also elsewhere on the board
/PV_POS_3: J4.1; also elsewhere on the board
/PV_POS_4: J5.1; also elsewhere on the board
/PV_POS_5: J6.1; also elsewhere on the board
/PV_POS_6: J7.1; also elsewhere on the board
/PV_POS_7: J8.1; also elsewhere on the board
/PV_POS_8: J9.1; also elsewhere on the board
/PV_POS_9: J10.1; also elsewhere on the board
/SCK: TP77.1, U3.15 (PA5); also elsewhere on the board
/SCL: R5.2, TP76.1, U3.42 (PB6); also elsewhere on the board
/SDA: R6.2, TP5.1, U3.43 (PB7); also elsewhere on the board
/SDIO: TP4.1, U3.17 (PA7); also elsewhere on the board
/SWCLK: J12.3, U3.37 (PA14)
/SWDIO: J12.4, U3.34 (PA13)
/SWO: J12.2, U3.39 (PB3)
GND: C1.2, C2.2, C3.2, C4.2, C5.2, C6.2, C7.2, C8.2, C9.2, C10.2, C11.2, C12.2, C13.2, D2.1 (K), J12.1, R1.2, R2.2, R3.1, TP3.1, U1.1 (GND), U2.7 (-VOUT), U3.8 (VSSA), U3.23 (VSS), U3.35 (VSS), U3.47 (VSS), Y1.2, Y1.4; also elsewhere on the board
unnamed: D1.1 (K), R1.1
unnamed: D2.2 (A), R4.2
unnamed: R2.1, U2.8 (VFB)
unnamed: R4.1, U3.12 (PA2)

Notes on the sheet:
Nested schems. for each LTM4611EV and supporting circuitry
SPI pullups
Buck Converter 5V
Crystal Oscillator
PV groups conn.
Power management
C = (12 - ~5) * 2 = 14pF
Microcontroller
SPI mode = 00
Galv. isolated PSU for uC and peripherals
C = (Cload - Cstray) * 2
Weak pullups on SPI CS to prevent spurious behaviour
I2C
Mounting
SWD
PV OUT
SWD
LDO regulator 3.3V
SPI

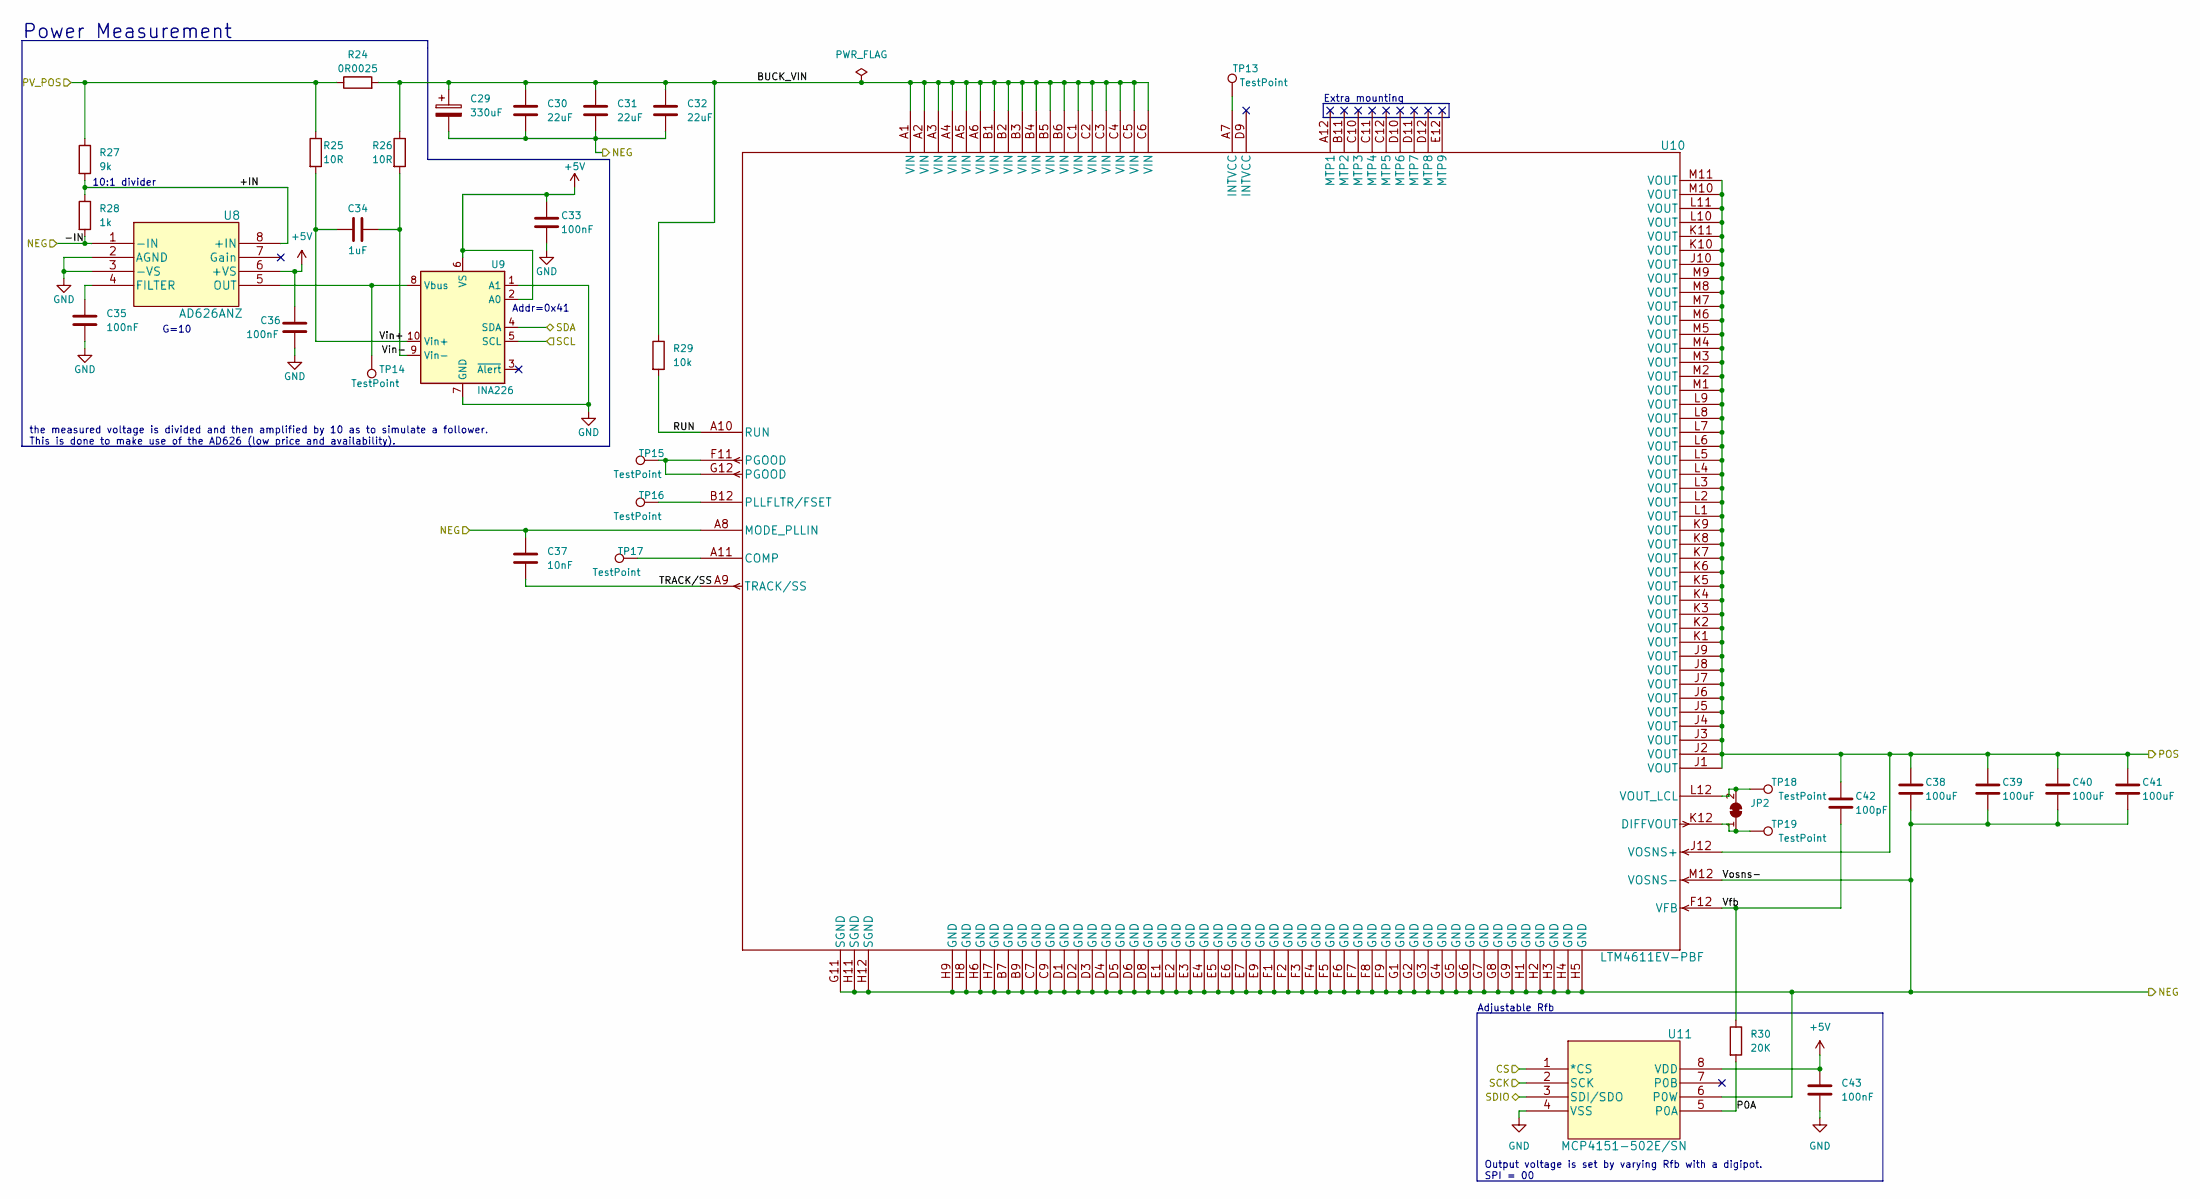
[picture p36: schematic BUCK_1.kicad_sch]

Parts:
C29: 330uF; CP_Elec_8x6.9
C30, C31, C32: 22uF; C_0805_2012Metric
C33, C35, C36, C43: 100nF; C_0603_1608Metric
C34: 1uF; C_0603_1608Metric
C37: 10nF; C_0603_1608Metric
C38, C39, C40, C41: 100uF; C_1206_3216Metric
C42: 100pF; C_0603_1608Metric
JP2: SolderJumper_2_Bridged; SolderJumper-2_P1.3mm_Bridged_RoundedPad1.0x1.5mm
R24: 0R0025; R_1206_3216Metric
R25, R26: 10R; R_0805_2012Metric
R27: 9k; R_0805_2012Metric
R28: 1k; R_0805_2012Metric
R29: 10k; R_0805_2012Metric
R30: 20K; R_0805_2012Metric
TP13, TP14, TP15, TP16, TP17, TP18, TP19: TestPoint; TestPoint_Pad_D2.0mm
U8: AD626ANZ; DIP-8_W7.62mm_Socket_LongPads
U9: INA226; VSSOP-10_3x3mm_P0.5mm
U10: LTM4611EV-PBF; Linear_LGA-133_15.0x15.0mm_Layout12x12_P1.27mm
U11: MCP4151-502E/SN; MSOP-8_3x3mm_P0.65mm

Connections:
+5V: C33.1, C36.1, C43.1, U8.6 (+VS), U9.2 (A0), U9.6 (VS), U11.8 (VDD); also elsewhere on the board
/BUCK_1/+IN: R27.2, R28.1, U8.8 (+IN)
/BUCK_1/BUCK_VIN: C29.1, C30.1, C31.1, C32.1, R24.2, R26.1, R29.1, U10.A1 (VIN), U10.A2 (VIN), U10.A3 (VIN), U10.A4 (VIN), U10.A5 (VIN), U10.A6 (VIN), U10.B1 (VIN), U10.B2 (VIN), U10.B3 (VIN), U10.B4 (VIN), U10.B5 (VIN), U10.B6 (VIN), U10.C1 (VIN), U10.C2 (VIN), U10.C3 (VIN), U10.C4 (VIN), U10.C5 (VIN), U10.C6 (VIN)
/BUCK_1/P0A: R30.2, U11.5 (P0A)
/BUCK_1/RUN: R29.2, U10.A10 (RUN)
/BUCK_1/TRACK/SS: C37.2, U10.A9 (TRACK/SS)
/BUCK_1/Vfb: C42.2, R30.1, U10.F12 (VFB)
/BUCK_1/Vin+: C34.1, R25.2, U9.10 (Vin+)
/BUCK_1/Vin-: C34.2, R26.2, U9.9 (Vin-)
/CS1: U11.1 (*CS); also elsewhere on the board
/NEG_1: C29.2, C30.2, C31.2, C32.2, C37.1, C38.2, C39.2, C40.2, C41.2, R28.2, U8.1 (-IN), U10.A8 (MODE_PLLIN), U10.B7 (GND), U10.B9 (GND), U10.C7 (GND), U10.C9 (GND), U10.D1 (GND), U10.D2 (GND), U10.D3 (GND), U10.D4 (GND), U10.D5 (GND), U10.D6 (GND), U10.D8 (GND), U10.E1 (GND), U10.E2 (GND), U10.E3 (GND), U10.E4 (GND), U10.E5 (GND), U10.E6 (GND), U10.E7 (GND), U10.E9 (GND), U10.F1 (GND), U10.F2 (GND), U10.F3 (GND), U10.F4 (GND), U10.F5 (GND), U10.F6 (GND), U10.F7 (GND), U10.F8 (GND), U10.F9 (GND), U10.G1 (GND), U10.G2 (GND), U10.G3 (GND), U10.G4 (GND), U10.G5 (GND), U10.G6 (GND), U10.G7 (GND), U10.G8 (GND), U10.G9 (GND), U10.G11 (SGND), U10.H1 (GND), U10.H2 (GND), U10.H3 (GND), U10.H4 (GND), U10.H5 (GND), U10.H6 (GND), U10.H7 (GND), U10.H8 (GND), U10.H9 (GND), U10.H11 (SGND), U10.H12 (SGND), U10.M12 (VOSNS-), U11.6 (P0W); also elsewhere on the board
/NEG_2: C38.1, C39.1, C40.1, C41.1, C42.1, U10.J1 (VOUT), U10.J2 (VOUT), U10.J3 (VOUT), U10.J4 (VOUT), U10.J5 (VOUT), U10.J6 (VOUT), U10.J7 (VOUT), U10.J8 (VOUT), U10.J9 (VOUT), U10.J10 (VOUT), U10.J12 (VOSNS+), U10.K1 (VOUT), U10.K2 (VOUT), U10.K3 (VOUT), U10.K4 (VOUT), U10.K5 (VOUT), U10.K6 (VOUT), U10.K7 (VOUT), U10.K8 (VOUT), U10.K9 (VOUT), U10.K10 (VOUT), U10.K11 (VOUT), U10.L1 (VOUT), U10.L2 (VOUT), U10.L3 (VOUT), U10.L4 (VOUT), U10.L5 (VOUT), U10.L6 (VOUT), U10.L7 (VOUT), U10.L8 (VOUT), U10.L9 (VOUT), U10.L10 (VOUT), U10.L11 (VOUT), U10.M1 (VOUT), U10.M2 (VOUT), U10.M3 (VOUT), U10.M4 (VOUT), U10.M5 (VOUT), U10.M6 (VOUT), U10.M7 (VOUT), U10.M8 (VOUT), U10.M9 (VOUT), U10.M10 (VOUT), U10.M11 (VOUT); also elsewhere on the board
/PV_POS_1: R24.1, R25.1, R27.1; also elsewhere on the board
/SCK: U11.2 (SCK); also elsewhere on the board
/SCL: U9.5 (SCL); also elsewhere on the board
/SDA: U9.4 (SDA); also elsewhere on the board
/SDIO: U11.3 (SDI/SDO); also elsewhere on the board
GND: C33.2, C35.2, C36.2, C43.2, U8.2 (AGND), U8.3 (-VS), U9.1 (A1), U9.7 (GND), U11.4 (VSS); also elsewhere on the board
unnamed: C35.1, U8.4 (FILTER)
unnamed: JP2.1 (A), TP19.1, U10.K12 (DIFFVOUT)
unnamed: JP2.2 (B), TP18.1, U10.L12 (VOUT_LCL)
unnamed: TP13.1, U10.A7 (INTVCC)
unnamed: TP14.1, U8.5 (OUT), U9.8 (Vbus)
unnamed: TP15.1, U10.F11 (PGOOD), U10.G12 (PGOOD)
unnamed: TP16.1, U10.B12 (PLLFLTR/FSET)
unnamed: TP17.1, U10.A11 (COMP)

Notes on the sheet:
G=10
Extra mounting
Power Measurement
10:1 divider
Adjustable Rfb
Output voltage is set by varying Rfb with a digipot. SPI = 00
Addr=0x41
the measured voltage is divided and then amplified by 10 as to simulate a follower. This is done to make use of the AD626 (low price and availability).

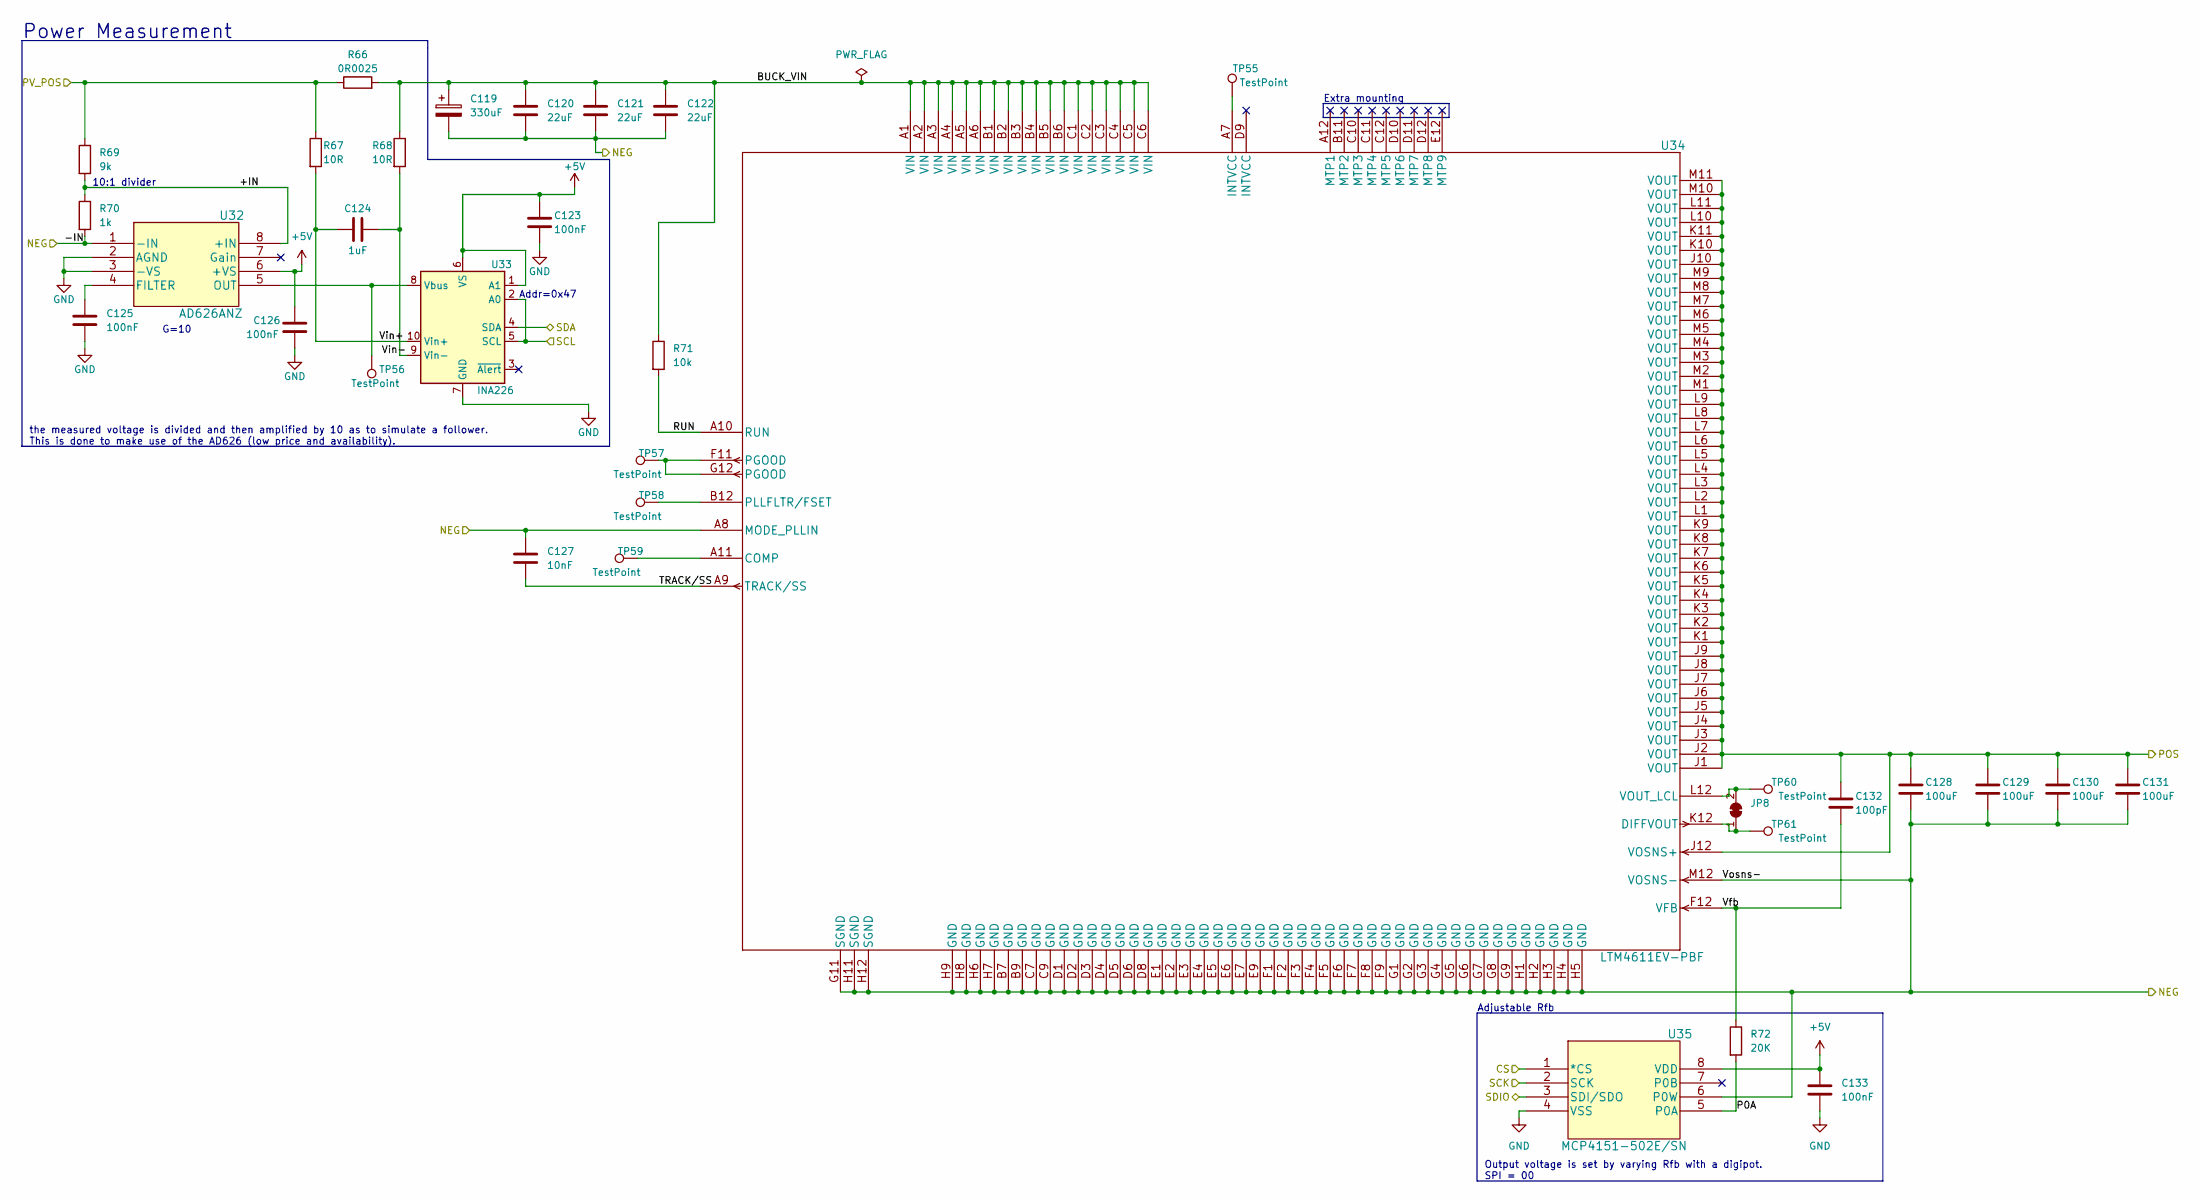
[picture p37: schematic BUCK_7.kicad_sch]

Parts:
C119: 330uF; CP_Elec_8x6.9
C120, C121, C122: 22uF; C_0805_2012Metric
C123, C125, C126, C133: 100nF; C_0603_1608Metric
C124: 1uF; C_0603_1608Metric
C127: 10nF; C_0603_1608Metric
C128, C129, C130, C131: 100uF; C_1206_3216Metric
C132: 100pF; C_0603_1608Metric
JP8: SolderJumper_2_Bridged; SolderJumper-2_P1.3mm_Bridged_RoundedPad1.0x1.5mm
R66: 0R0025; R_1206_3216Metric
R67, R68: 10R; R_0805_2012Metric
R69: 9k; R_0805_2012Metric
R70: 1k; R_0805_2012Metric
R71: 10k; R_0805_2012Metric
R72: 20K; R_0805_2012Metric
TP55, TP56, TP57, TP58, TP59, TP60, TP61: TestPoint; TestPoint_Pad_D2.0mm
U32: AD626ANZ; DIP-8_W7.62mm_Socket_LongPads
U33: INA226; VSSOP-10_3x3mm_P0.5mm
U34: LTM4611EV-PBF; Linear_LGA-133_15.0x15.0mm_Layout12x12_P1.27mm
U35: MCP4151-502E/SN; MSOP-8_3x3mm_P0.65mm

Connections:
+5V: C123.1, C126.1, C133.1, U32.6 (+VS), U33.1 (A1), U33.6 (VS), U35.8 (VDD); also elsewhere on the board
/BUCK_7/+IN: R69.2, R70.1, U32.8 (+IN)
/BUCK_7/BUCK_VIN: C119.1, C120.1, C121.1, C122.1, R66.2, R68.1, R71.1, U34.A1 (VIN), U34.A2 (VIN), U34.A3 (VIN), U34.A4 (VIN), U34.A5 (VIN), U34.A6 (VIN), U34.B1 (VIN), U34.B2 (VIN), U34.B3 (VIN), U34.B4 (VIN), U34.B5 (VIN), U34.B6 (VIN), U34.C1 (VIN), U34.C2 (VIN), U34.C3 (VIN), U34.C4 (VIN), U34.C5 (VIN), U34.C6 (VIN)
/BUCK_7/P0A: R72.2, U35.5 (P0A)
/BUCK_7/RUN: R71.2, U34.A10 (RUN)
/BUCK_7/TRACK/SS: C127.2, U34.A9 (TRACK/SS)
/BUCK_7/Vfb: C132.2, R72.1, U34.F12 (VFB)
/BUCK_7/Vin+: C124.1, R67.2, U33.10 (Vin+)
/BUCK_7/Vin-: C124.2, R68.2, U33.9 (Vin-)
/CS7: U35.1 (*CS); also elsewhere on the board
/NEG_7: C119.2, C120.2, C121.2, C122.2, C127.1, C128.2, C129.2, C130.2, C131.2, R70.2, U32.1 (-IN), U34.A8 (MODE_PLLIN), U34.B7 (GND), U34.B9 (GND), U34.C7 (GND), U34.C9 (GND), U34.D1 (GND), U34.D2 (GND), U34.D3 (GND), U34.D4 (GND), U34.D5 (GND), U34.D6 (GND), U34.D8 (GND), U34.E1 (GND), U34.E2 (GND), U34.E3 (GND), U34.E4 (GND), U34.E5 (GND), U34.E6 (GND), U34.E7 (GND), U34.E9 (GND), U34.F1 (GND), U34.F2 (GND), U34.F3 (GND), U34.F4 (GND), U34.F5 (GND), U34.F6 (GND), U34.F7 (GND), U34.F8 (GND), U34.F9 (GND), U34.G1 (GND), U34.G2 (GND), U34.G3 (GND), U34.G4 (GND), U34.G5 (GND), U34.G6 (GND), U34.G7 (GND), U34.G8 (GND), U34.G9 (GND), U34.G11 (SGND), U34.H1 (GND), U34.H2 (GND), U34.H3 (GND), U34.H4 (GND), U34.H5 (GND), U34.H6 (GND), U34.H7 (GND), U34.H8 (GND), U34.H9 (GND), U34.H11 (SGND), U34.H12 (SGND), U34.M12 (VOSNS-), U35.6 (P0W); also elsewhere on the board
/NEG_8: C128.1, C129.1, C130.1, C131.1, C132.1, U34.J1 (VOUT), U34.J2 (VOUT), U34.J3 (VOUT), U34.J4 (VOUT), U34.J5 (VOUT), U34.J6 (VOUT), U34.J7 (VOUT), U34.J8 (VOUT), U34.J9 (VOUT), U34.J10 (VOUT), U34.J12 (VOSNS+), U34.K1 (VOUT), U34.K2 (VOUT), U34.K3 (VOUT), U34.K4 (VOUT), U34.K5 (VOUT), U34.K6 (VOUT), U34.K7 (VOUT), U34.K8 (VOUT), U34.K9 (VOUT), U34.K10 (VOUT), U34.K11 (VOUT), U34.L1 (VOUT), U34.L2 (VOUT), U34.L3 (VOUT), U34.L4 (VOUT), U34.L5 (VOUT), U34.L6 (VOUT), U34.L7 (VOUT), U34.L8 (VOUT), U34.L9 (VOUT), U34.L10 (VOUT), U34.L11 (VOUT), U34.M1 (VOUT), U34.M2 (VOUT), U34.M3 (VOUT), U34.M4 (VOUT), U34.M5 (VOUT), U34.M6 (VOUT), U34.M7 (VOUT), U34.M8 (VOUT), U34.M9 (VOUT), U34.M10 (VOUT), U34.M11 (VOUT); also elsewhere on the board
/PV_POS_7: R66.1, R67.1, R69.1; also elsewhere on the board
/SCK: U35.2 (SCK); also elsewhere on the board
/SCL: U33.2 (A0), U33.5 (SCL); also elsewhere on the board
/SDA: U33.4 (SDA); also elsewhere on the board
/SDIO: U35.3 (SDI/SDO); also elsewhere on the board
GND: C123.2, C125.2, C126.2, C133.2, U32.2 (AGND), U32.3 (-VS), U33.7 (GND), U35.4 (VSS); also elsewhere on the board
unnamed: C125.1, U32.4 (FILTER)
unnamed: JP8.1 (A), TP61.1, U34.K12 (DIFFVOUT)
unnamed: JP8.2 (B), TP60.1, U34.L12 (VOUT_LCL)
unnamed: TP55.1, U34.A7 (INTVCC)
unnamed: TP56.1, U32.5 (OUT), U33.8 (Vbus)
unnamed: TP57.1, U34.F11 (PGOOD), U34.G12 (PGOOD)
unnamed: TP58.1, U34.B12 (PLLFLTR/FSET)
unnamed: TP59.1, U34.A11 (COMP)

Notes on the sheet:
Output voltage is set by varying Rfb with a digipot. SPI = 00
the measured voltage is divided and then amplified by 10 as to simulate a follower. This is done to make use of the AD626 (low price and availability).
Extra mounting
Adjustable Rfb
G=10
Addr=0x47
10:1 divider
Power Measurement

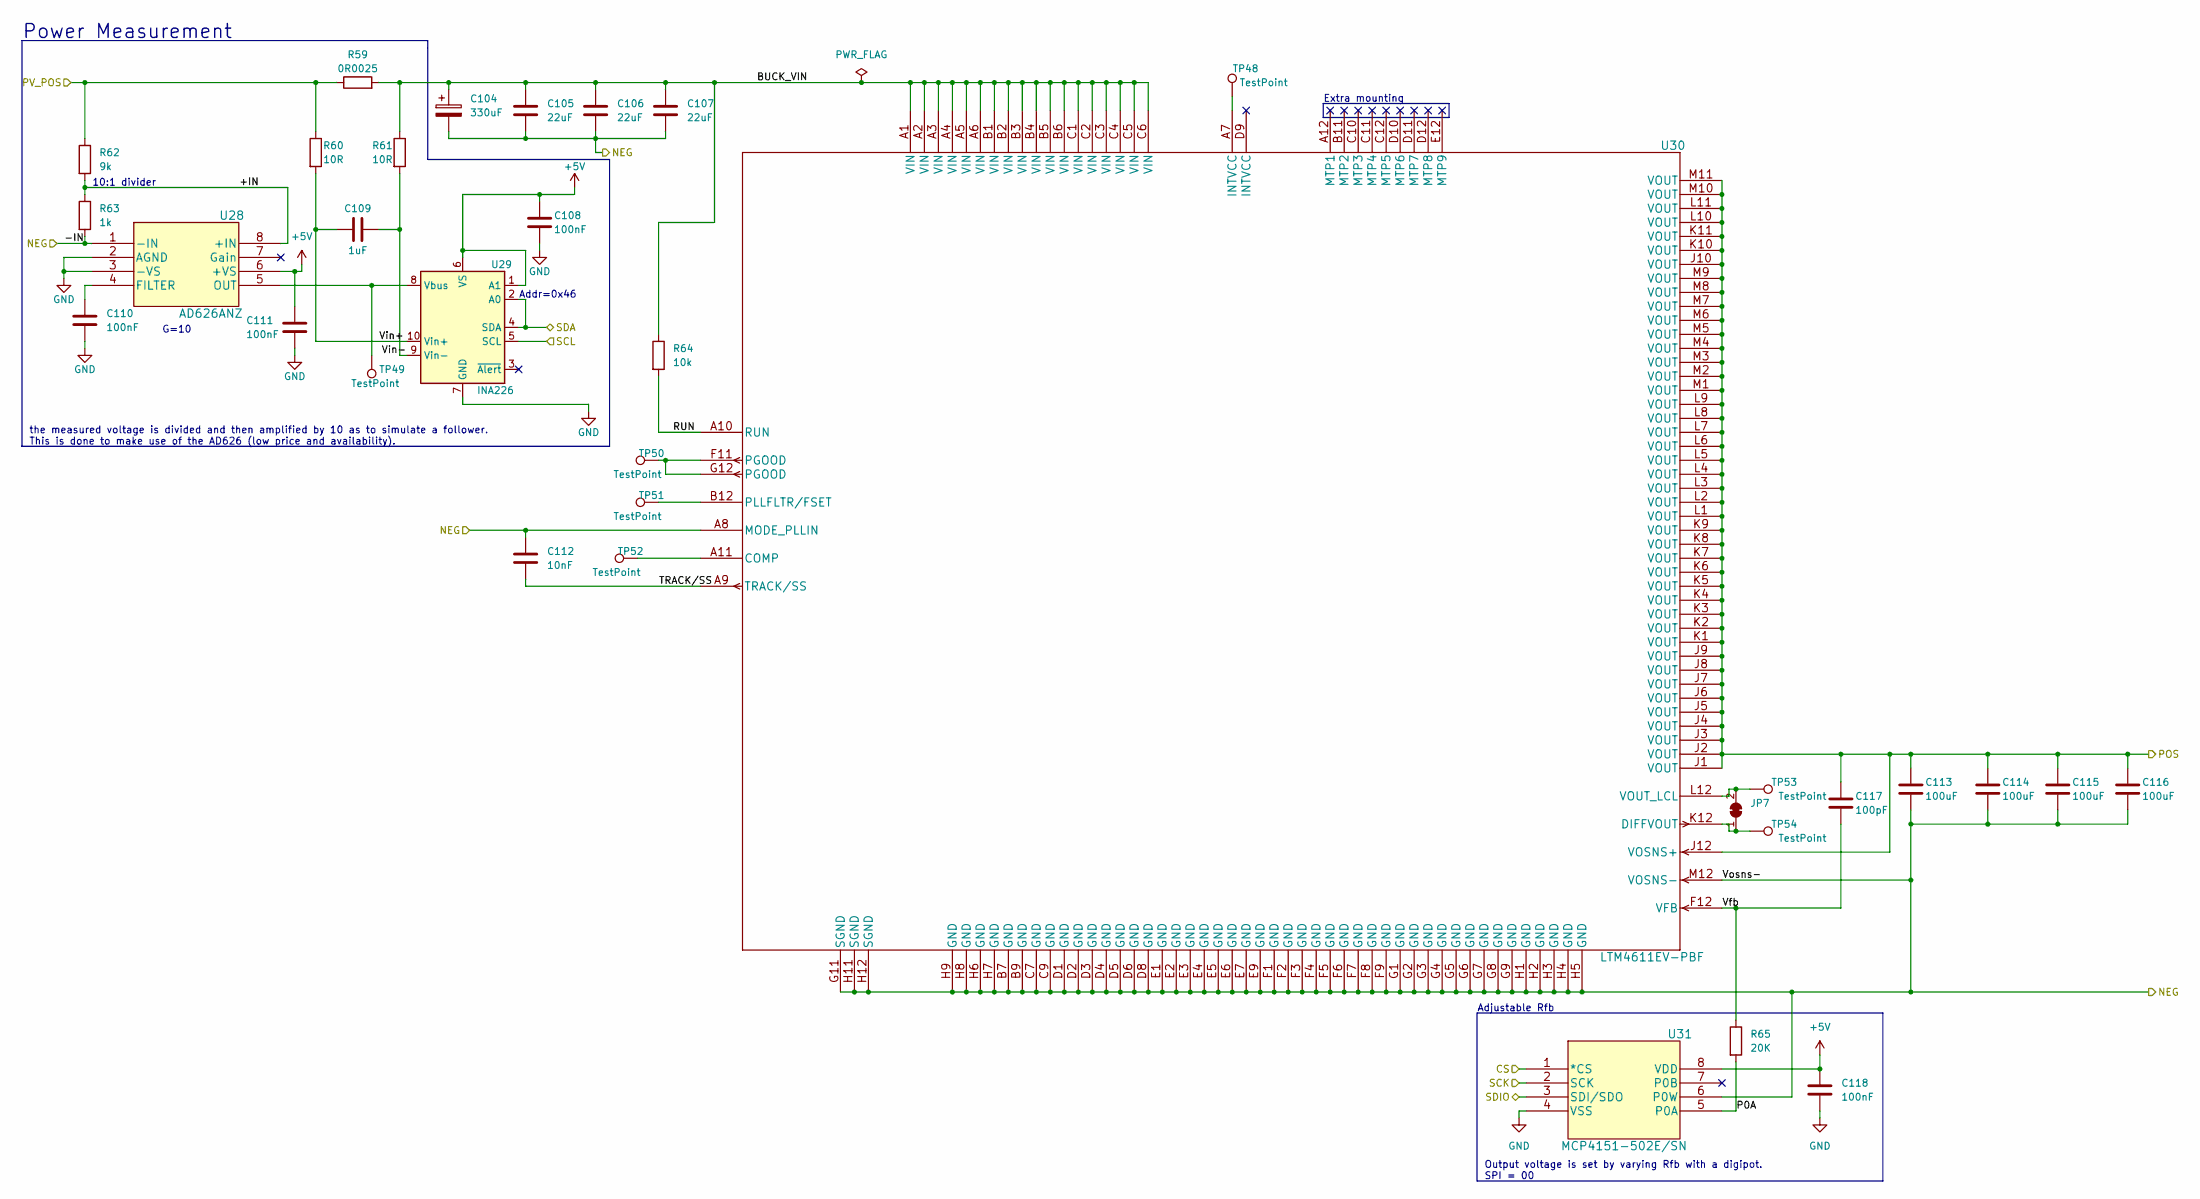
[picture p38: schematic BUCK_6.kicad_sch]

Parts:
C104: 330uF; CP_Elec_8x6.9
C105, C106, C107: 22uF; C_0805_2012Metric
C108, C110, C111, C118: 100nF; C_0603_1608Metric
C109: 1uF; C_0603_1608Metric
C112: 10nF; C_0603_1608Metric
C113, C114, C115, C116: 100uF; C_1206_3216Metric
C117: 100pF; C_0603_1608Metric
JP7: SolderJumper_2_Bridged; SolderJumper-2_P1.3mm_Bridged_RoundedPad1.0x1.5mm
R59: 0R0025; R_1206_3216Metric
R60, R61: 10R; R_0805_2012Metric
R62: 9k; R_0805_2012Metric
R63: 1k; R_0805_2012Metric
R64: 10k; R_0805_2012Metric
R65: 20K; R_0805_2012Metric
TP48, TP49, TP50, TP51, TP52, TP53, TP54: TestPoint; TestPoint_Pad_D2.0mm
U28: AD626ANZ; DIP-8_W7.62mm_Socket_LongPads
U29: INA226; VSSOP-10_3x3mm_P0.5mm
U30: LTM4611EV-PBF; Linear_LGA-133_15.0x15.0mm_Layout12x12_P1.27mm
U31: MCP4151-502E/SN; MSOP-8_3x3mm_P0.65mm

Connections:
+5V: C108.1, C111.1, C118.1, U28.6 (+VS), U29.1 (A1), U29.6 (VS), U31.8 (VDD); also elsewhere on the board
/BUCK_6/+IN: R62.2, R63.1, U28.8 (+IN)
/BUCK_6/BUCK_VIN: C104.1, C105.1, C106.1, C107.1, R59.2, R61.1, R64.1, U30.A1 (VIN), U30.A2 (VIN), U30.A3 (VIN), U30.A4 (VIN), U30.A5 (VIN), U30.A6 (VIN), U30.B1 (VIN), U30.B2 (VIN), U30.B3 (VIN), U30.B4 (VIN), U30.B5 (VIN), U30.B6 (VIN), U30.C1 (VIN), U30.C2 (VIN), U30.C3 (VIN), U30.C4 (VIN), U30.C5 (VIN), U30.C6 (VIN)
/BUCK_6/P0A: R65.2, U31.5 (P0A)
/BUCK_6/RUN: R64.2, U30.A10 (RUN)
/BUCK_6/TRACK/SS: C112.2, U30.A9 (TRACK/SS)
/BUCK_6/Vfb: C117.2, R65.1, U30.F12 (VFB)
/BUCK_6/Vin+: C109.1, R60.2, U29.10 (Vin+)
/BUCK_6/Vin-: C109.2, R61.2, U29.9 (Vin-)
/CS6: U31.1 (*CS); also elsewhere on the board
/NEG_6: C104.2, C105.2, C106.2, C107.2, C112.1, C113.2, C114.2, C115.2, C116.2, R63.2, U28.1 (-IN), U30.A8 (MODE_PLLIN), U30.B7 (GND), U30.B9 (GND), U30.C7 (GND), U30.C9 (GND), U30.D1 (GND), U30.D2 (GND), U30.D3 (GND), U30.D4 (GND), U30.D5 (GND), U30.D6 (GND), U30.D8 (GND), U30.E1 (GND), U30.E2 (GND), U30.E3 (GND), U30.E4 (GND), U30.E5 (GND), U30.E6 (GND), U30.E7 (GND), U30.E9 (GND), U30.F1 (GND), U30.F2 (GND), U30.F3 (GND), U30.F4 (GND), U30.F5 (GND), U30.F6 (GND), U30.F7 (GND), U30.F8 (GND), U30.F9 (GND), U30.G1 (GND), U30.G2 (GND), U30.G3 (GND), U30.G4 (GND), U30.G5 (GND), U30.G6 (GND), U30.G7 (GND), U30.G8 (GND), U30.G9 (GND), U30.G11 (SGND), U30.H1 (GND), U30.H2 (GND), U30.H3 (GND), U30.H4 (GND), U30.H5 (GND), U30.H6 (GND), U30.H7 (GND), U30.H8 (GND), U30.H9 (GND), U30.H11 (SGND), U30.H12 (SGND), U30.M12 (VOSNS-), U31.6 (P0W); also elsewhere on the board
/NEG_7: C113.1, C114.1, C115.1, C116.1, C117.1, U30.J1 (VOUT), U30.J2 (VOUT), U30.J3 (VOUT), U30.J4 (VOUT), U30.J5 (VOUT), U30.J6 (VOUT), U30.J7 (VOUT), U30.J8 (VOUT), U30.J9 (VOUT), U30.J10 (VOUT), U30.J12 (VOSNS+), U30.K1 (VOUT), U30.K2 (VOUT), U30.K3 (VOUT), U30.K4 (VOUT), U30.K5 (VOUT), U30.K6 (VOUT), U30.K7 (VOUT), U30.K8 (VOUT), U30.K9 (VOUT), U30.K10 (VOUT), U30.K11 (VOUT), U30.L1 (VOUT), U30.L2 (VOUT), U30.L3 (VOUT), U30.L4 (VOUT), U30.L5 (VOUT), U30.L6 (VOUT), U30.L7 (VOUT), U30.L8 (VOUT), U30.L9 (VOUT), U30.L10 (VOUT), U30.L11 (VOUT), U30.M1 (VOUT), U30.M2 (VOUT), U30.M3 (VOUT), U30.M4 (VOUT), U30.M5 (VOUT), U30.M6 (VOUT), U30.M7 (VOUT), U30.M8 (VOUT), U30.M9 (VOUT), U30.M10 (VOUT), U30.M11 (VOUT); also elsewhere on the board
/PV_POS_6: R59.1, R60.1, R62.1; also elsewhere on the board
/SCK: U31.2 (SCK); also elsewhere on the board
/SCL: U29.5 (SCL); also elsewhere on the board
/SDA: U29.2 (A0), U29.4 (SDA); also elsewhere on the board
/SDIO: U31.3 (SDI/SDO); also elsewhere on the board
GND: C108.2, C110.2, C111.2, C118.2, U28.2 (AGND), U28.3 (-VS), U29.7 (GND), U31.4 (VSS); also elsewhere on the board
unnamed: C110.1, U28.4 (FILTER)
unnamed: JP7.1 (A), TP54.1, U30.K12 (DIFFVOUT)
unnamed: JP7.2 (B), TP53.1, U30.L12 (VOUT_LCL)
unnamed: TP48.1, U30.A7 (INTVCC)
unnamed: TP49.1, U28.5 (OUT), U29.8 (Vbus)
unnamed: TP50.1, U30.F11 (PGOOD), U30.G12 (PGOOD)
unnamed: TP51.1, U30.B12 (PLLFLTR/FSET)
unnamed: TP52.1, U30.A11 (COMP)

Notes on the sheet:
Extra mounting
Addr=0x46
10:1 divider
the measured voltage is divided and then amplified by 10 as to simulate a follower. This is done to make use of the AD626 (low price and availability).
Power Measurement
Output voltage is set by varying Rfb with a digipot. SPI = 00
Adjustable Rfb
G=10

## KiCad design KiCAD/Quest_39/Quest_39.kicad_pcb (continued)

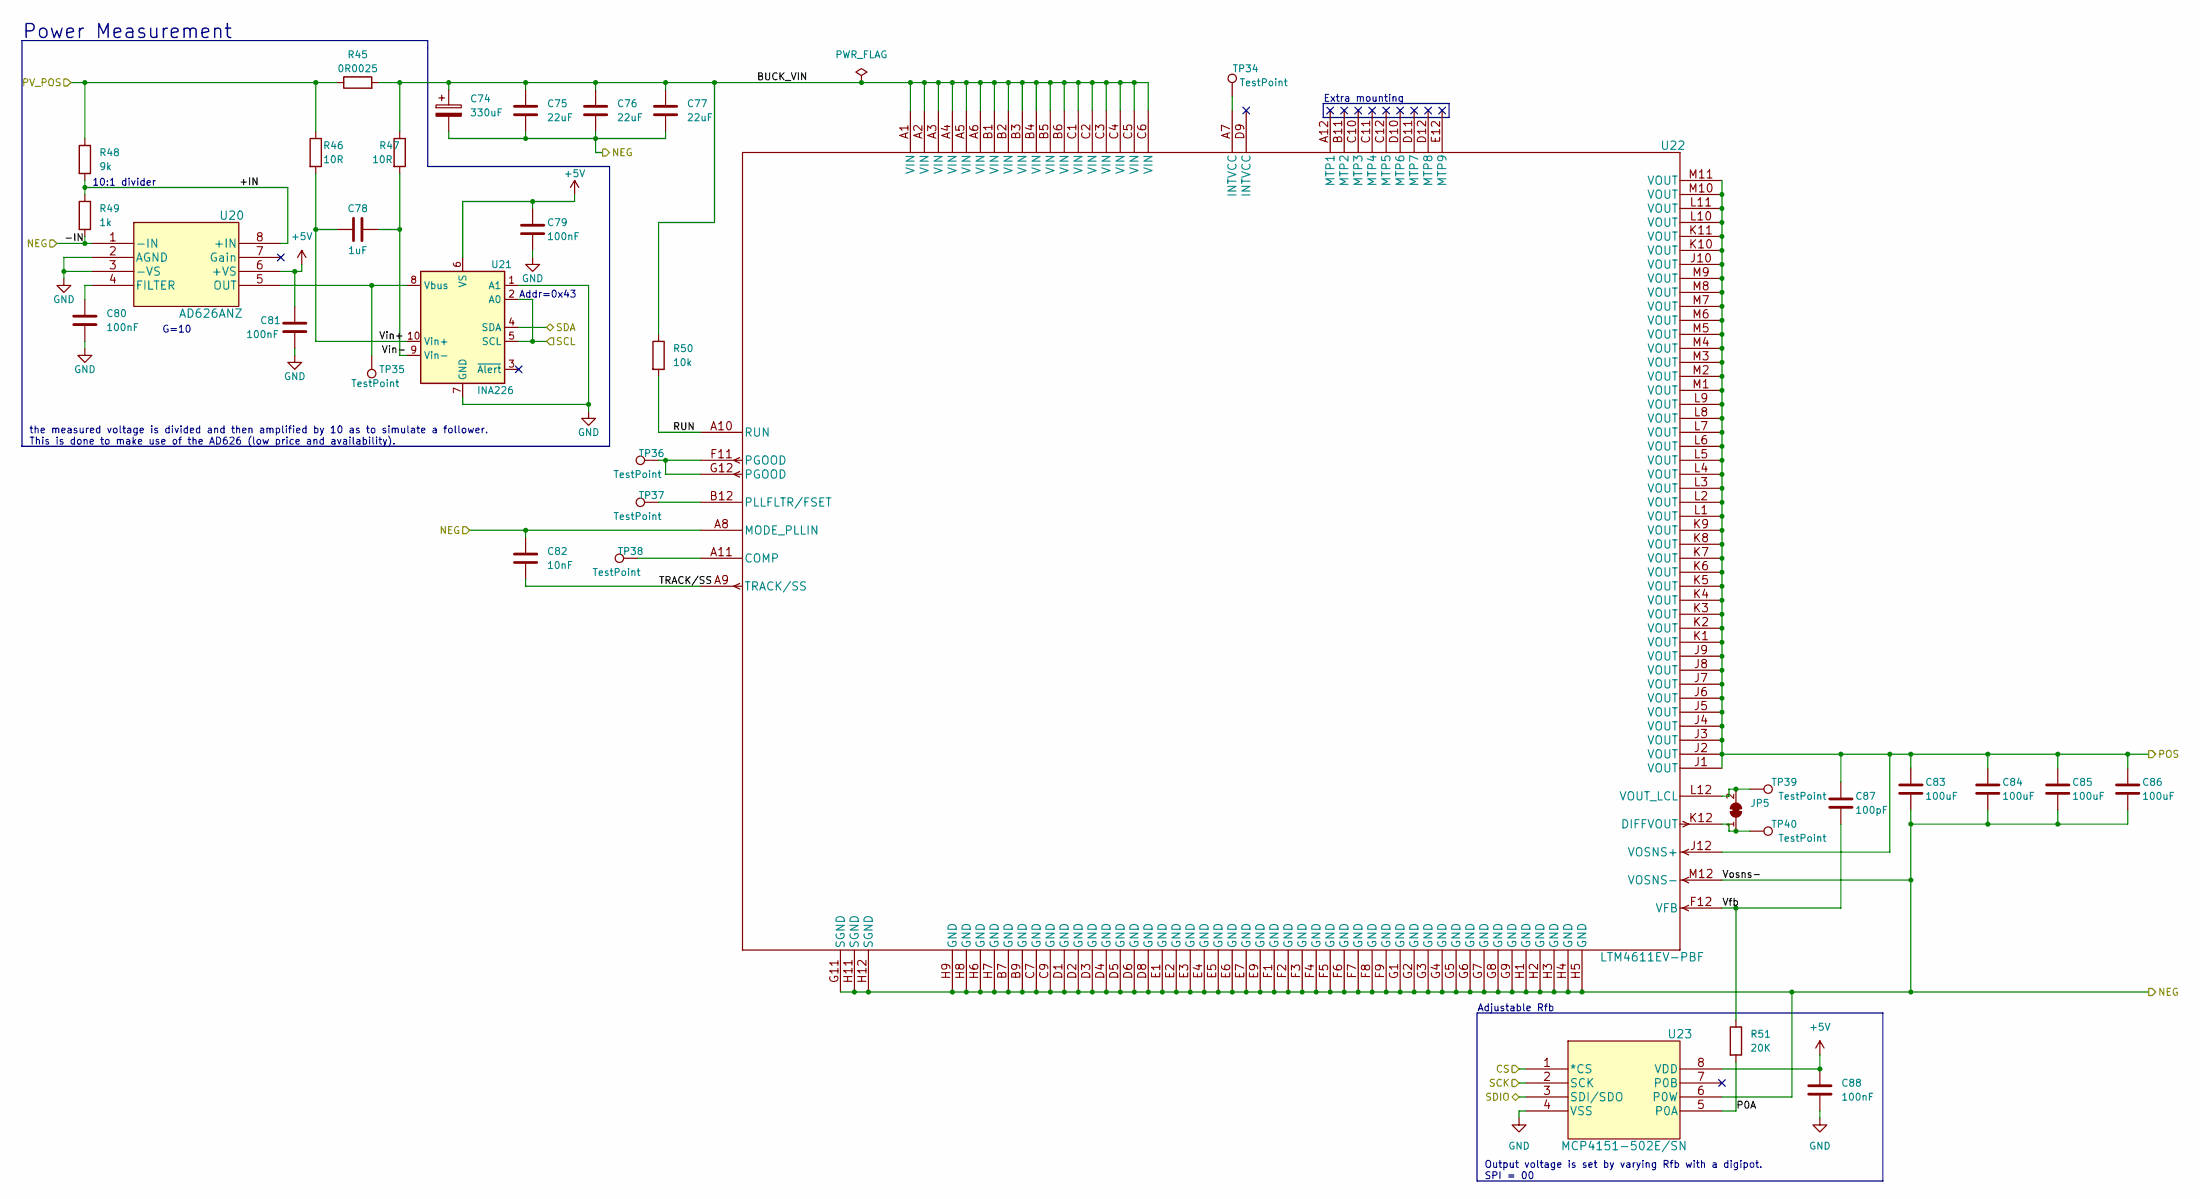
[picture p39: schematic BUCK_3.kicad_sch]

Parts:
C74: 330uF; CP_Elec_8x6.9
C75, C76, C77: 22uF; C_0805_2012Metric
C78: 1uF; C_0603_1608Metric
C79, C80, C81, C88: 100nF; C_0603_1608Metric
C82: 10nF; C_0603_1608Metric
C83, C84, C85, C86: 100uF; C_1206_3216Metric
C87: 100pF; C_0603_1608Metric
JP5: SolderJumper_2_Bridged; SolderJumper-2_P1.3mm_Bridged_RoundedPad1.0x1.5mm
R45: 0R0025; R_1206_3216Metric
R46, R47: 10R; R_0805_2012Metric
R48: 9k; R_0805_2012Metric
R49: 1k; R_0805_2012Metric
R50: 10k; R_0805_2012Metric
R51: 20K; R_0805_2012Metric
TP34, TP35, TP36, TP37, TP38, TP39, TP40: TestPoint; TestPoint_Pad_D2.0mm
U20: AD626ANZ; DIP-8_W7.62mm_Socket_LongPads
U21: INA226; VSSOP-10_3x3mm_P0.5mm
U22: LTM4611EV-PBF; Linear_LGA-133_15.0x15.0mm_Layout12x12_P1.27mm
U23: MCP4151-502E/SN; MSOP-8_3x3mm_P0.65mm

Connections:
+5V: C79.1, C81.1, C88.1, U20.6 (+VS), U21.6 (VS), U23.8 (VDD); also elsewhere on the board
/BUCK_3/+IN: R48.2, R49.1, U20.8 (+IN)
/BUCK_3/BUCK_VIN: C74.1, C75.1, C76.1, C77.1, R45.2, R47.1, R50.1, U22.A1 (VIN), U22.A2 (VIN), U22.A3 (VIN), U22.A4 (VIN), U22.A5 (VIN), U22.A6 (VIN), U22.B1 (VIN), U22.B2 (VIN), U22.B3 (VIN), U22.B4 (VIN), U22.B5 (VIN), U22.B6 (VIN), U22.C1 (VIN), U22.C2 (VIN), U22.C3 (VIN), U22.C4 (VIN), U22.C5 (VIN), U22.C6 (VIN)
/BUCK_3/P0A: R51.2, U23.5 (P0A)
/BUCK_3/RUN: R50.2, U22.A10 (RUN)
/BUCK_3/TRACK/SS: C82.2, U22.A9 (TRACK/SS)
/BUCK_3/Vfb: C87.2, R51.1, U22.F12 (VFB)
/BUCK_3/Vin+: C78.1, R46.2, U21.10 (Vin+)
/BUCK_3/Vin-: C78.2, R47.2, U21.9 (Vin-)
/CS3: U23.1 (*CS); also elsewhere on the board
/NEG_3: C74.2, C75.2, C76.2, C77.2, C82.1, C83.2, C84.2, C85.2, C86.2, R49.2, U20.1 (-IN), U22.A8 (MODE_PLLIN), U22.B7 (GND), U22.B9 (GND), U22.C7 (GND), U22.C9 (GND), U22.D1 (GND), U22.D2 (GND), U22.D3 (GND), U22.D4 (GND), U22.D5 (GND), U22.D6 (GND), U22.D8 (GND), U22.E1 (GND), U22.E2 (GND), U22.E3 (GND), U22.E4 (GND), U22.E5 (GND), U22.E6 (GND), U22.E7 (GND), U22.E9 (GND), U22.F1 (GND), U22.F2 (GND), U22.F3 (GND), U22.F4 (GND), U22.F5 (GND), U22.F6 (GND), U22.F7 (GND), U22.F8 (GND), U22.F9 (GND), U22.G1 (GND), U22.G2 (GND), U22.G3 (GND), U22.G4 (GND), U22.G5 (GND), U22.G6 (GND), U22.G7 (GND), U22.G8 (GND), U22.G9 (GND), U22.G11 (SGND), U22.H1 (GND), U22.H2 (GND), U22.H3 (GND), U22.H4 (GND), U22.H5 (GND), U22.H6 (GND), U22.H7 (GND), U22.H8 (GND), U22.H9 (GND), U22.H11 (SGND), U22.H12 (SGND), U22.M12 (VOSNS-), U23.6 (P0W); also elsewhere on the board
/NEG_4: C83.1, C84.1, C85.1, C86.1, C87.1, U22.J1 (VOUT), U22.J2 (VOUT), U22.J3 (VOUT), U22.J4 (VOUT), U22.J5 (VOUT), U22.J6 (VOUT), U22.J7 (VOUT), U22.J8 (VOUT), U22.J9 (VOUT), U22.J10 (VOUT), U22.J12 (VOSNS+), U22.K1 (VOUT), U22.K2 (VOUT), U22.K3 (VOUT), U22.K4 (VOUT), U22.K5 (VOUT), U22.K6 (VOUT), U22.K7 (VOUT), U22.K8 (VOUT), U22.K9 (VOUT), U22.K10 (VOUT), U22.K11 (VOUT), U22.L1 (VOUT), U22.L2 (VOUT), U22.L3 (VOUT), U22.L4 (VOUT), U22.L5 (VOUT), U22.L6 (VOUT), U22.L7 (VOUT), U22.L8 (VOUT), U22.L9 (VOUT), U22.L10 (VOUT), U22.L11 (VOUT), U22.M1 (VOUT), U22.M2 (VOUT), U22.M3 (VOUT), U22.M4 (VOUT), U22.M5 (VOUT), U22.M6 (VOUT), U22.M7 (VOUT), U22.M8 (VOUT), U22.M9 (VOUT), U22.M10 (VOUT), U22.M11 (VOUT); also elsewhere on the board
/PV_POS_3: R45.1, R46.1, R48.1; also elsewhere on the board
/SCK: U23.2 (SCK); also elsewhere on the board
/SCL: U21.2 (A0), U21.5 (SCL); also elsewhere on the board
/SDA: U21.4 (SDA); also elsewhere on the board
/SDIO: U23.3 (SDI/SDO); also elsewhere on the board
GND: C79.2, C80.2, C81.2, C88.2, U20.2 (AGND), U20.3 (-VS), U21.1 (A1), U21.7 (GND), U23.4 (VSS); also elsewhere on the board
unnamed: C80.1, U20.4 (FILTER)
unnamed: JP5.1 (A), TP40.1, U22.K12 (DIFFVOUT)
unnamed: JP5.2 (B), TP39.1, U22.L12 (VOUT_LCL)
unnamed: TP34.1, U22.A7 (INTVCC)
unnamed: TP35.1, U20.5 (OUT), U21.8 (Vbus)
unnamed: TP36.1, U22.F11 (PGOOD), U22.G12 (PGOOD)
unnamed: TP37.1, U22.B12 (PLLFLTR/FSET)
unnamed: TP38.1, U22.A11 (COMP)

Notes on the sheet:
Adjustable Rfb
the measured voltage is divided and then amplified by 10 as to simulate a follower. This is done to make use of the AD626 (low price and availability).
Extra mounting
Output voltage is set by varying Rfb with a digipot. SPI = 00
Addr=0x43
10:1 divider
G=10
Power Measurement

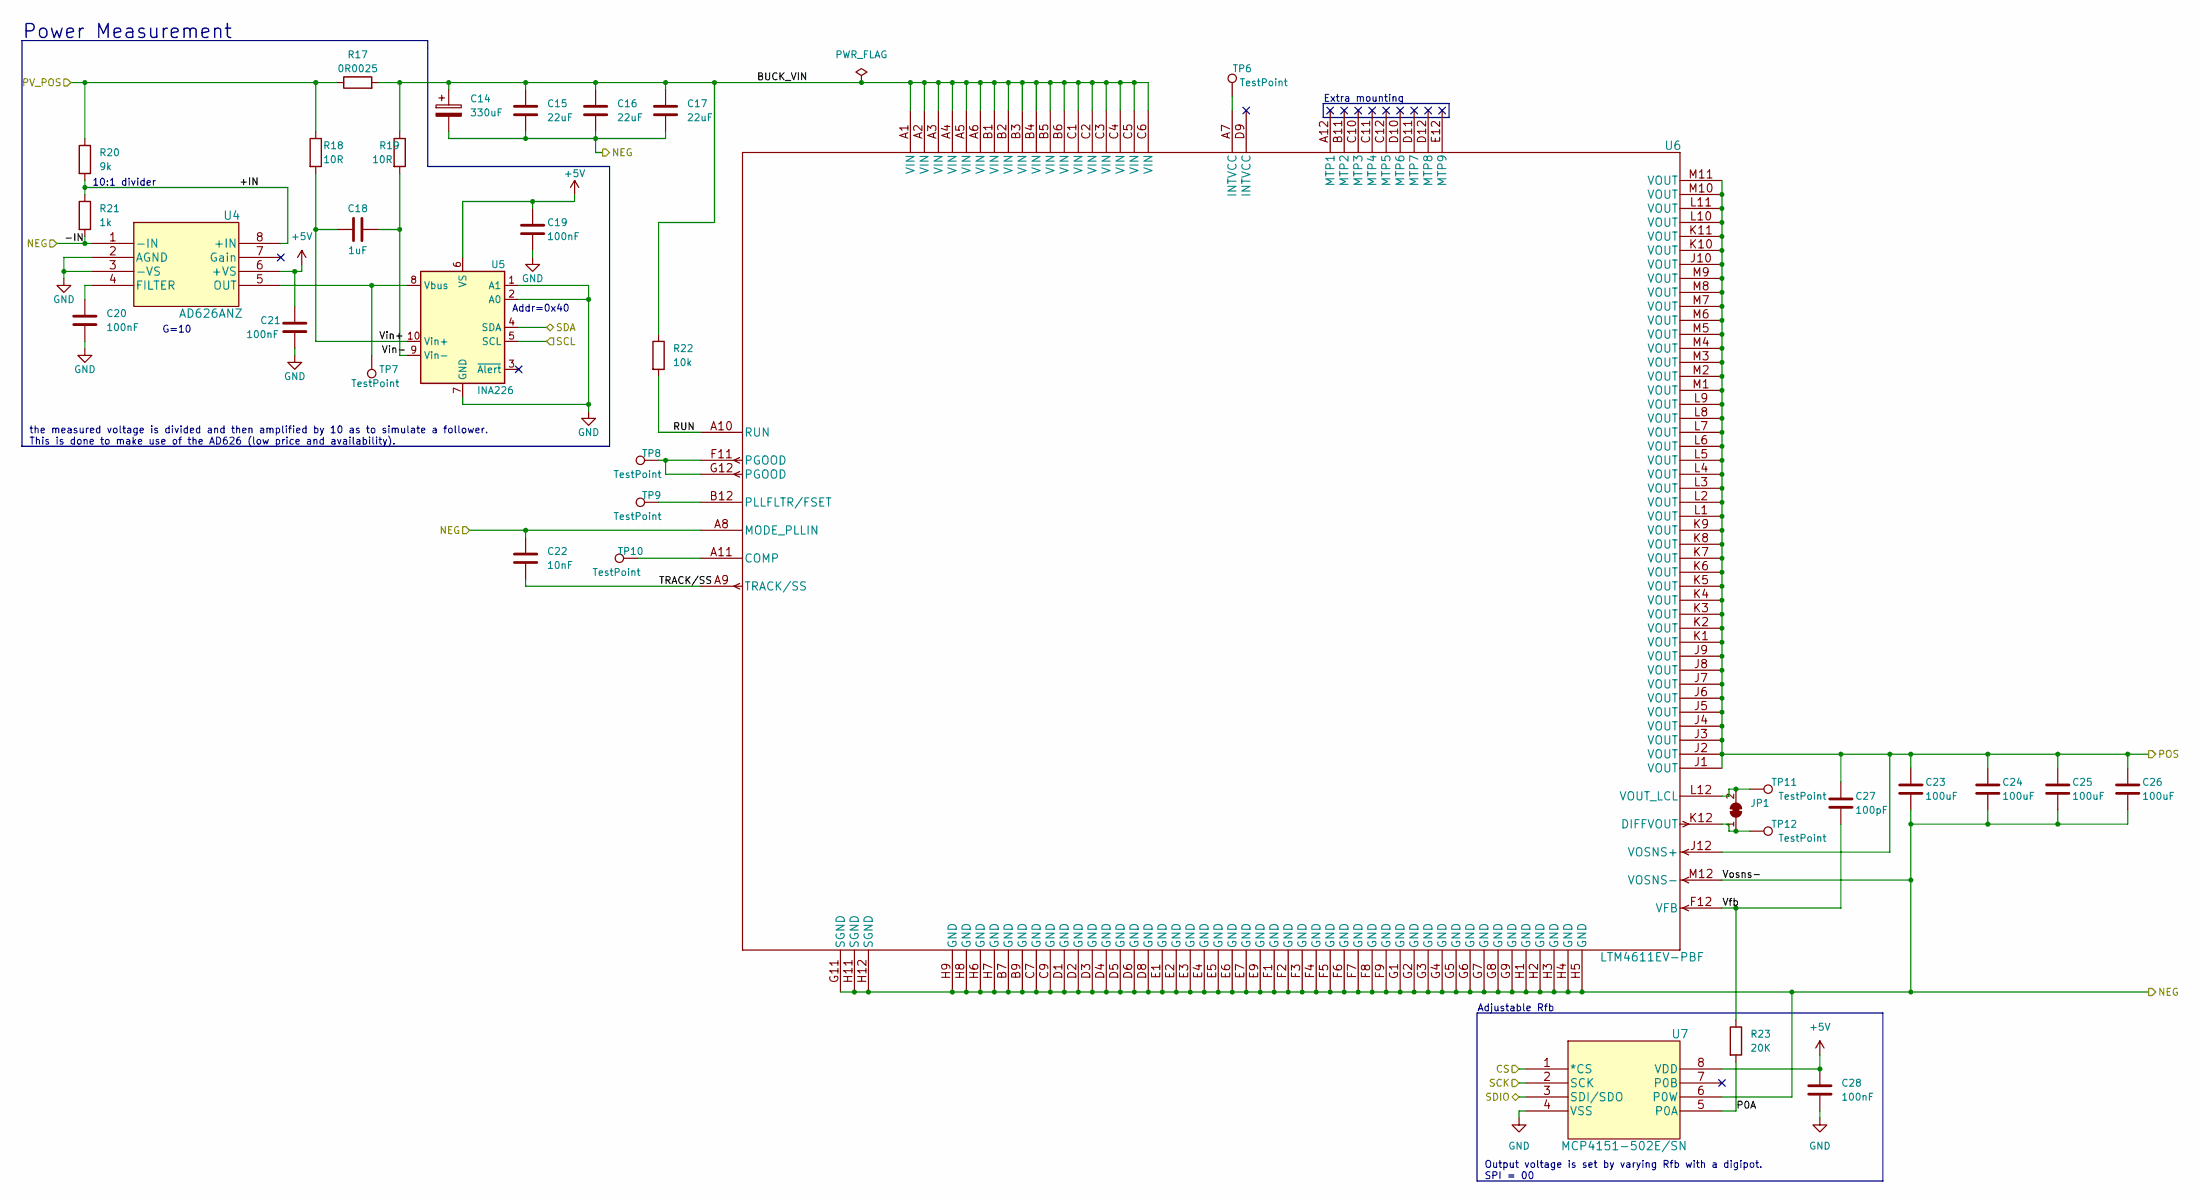
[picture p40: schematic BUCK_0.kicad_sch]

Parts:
C14: 330uF; CP_Elec_8x6.9
C15, C16, C17: 22uF; C_0805_2012Metric
C18: 1uF; C_0603_1608Metric
C19, C20, C21, C28: 100nF; C_0603_1608Metric
C22: 10nF; C_0603_1608Metric
C23, C24, C25, C26: 100uF; C_1206_3216Metric
C27: 100pF; C_0603_1608Metric
JP1: SolderJumper_2_Bridged; SolderJumper-2_P1.3mm_Bridged_RoundedPad1.0x1.5mm
R17: 0R0025; R_1206_3216Metric
R18, R19: 10R; R_0805_2012Metric
R20: 9k; R_0805_2012Metric
R21: 1k; R_0805_2012Metric
R22: 10k; R_0805_2012Metric
R23: 20K; R_0805_2012Metric
TP6, TP7, TP8, TP9, TP10, TP11, TP12: TestPoint; TestPoint_Pad_D2.0mm
U4: AD626ANZ; DIP-8_W7.62mm_Socket_LongPads
U5: INA226; VSSOP-10_3x3mm_P0.5mm
U6: LTM4611EV-PBF; Linear_LGA-133_15.0x15.0mm_Layout12x12_P1.27mm
U7: MCP4151-502E/SN; MSOP-8_3x3mm_P0.65mm

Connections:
+5V: C19.1, C21.1, C28.1, U4.6 (+VS), U5.6 (VS), U7.8 (VDD); also elsewhere on the board
/BUCK_0/+IN: R20.2, R21.1, U4.8 (+IN)
/BUCK_0/BUCK_VIN: C14.1, C15.1, C16.1, C17.1, R17.2, R19.1, R22.1, U6.A1 (VIN), U6.A2 (VIN), U6.A3 (VIN), U6.A4 (VIN), U6.A5 (VIN), U6.A6 (VIN), U6.B1 (VIN), U6.B2 (VIN), U6.B3 (VIN), U6.B4 (VIN), U6.B5 (VIN), U6.B6 (VIN), U6.C1 (VIN), U6.C2 (VIN), U6.C3 (VIN), U6.C4 (VIN), U6.C5 (VIN), U6.C6 (VIN)
/BUCK_0/P0A: R23.2, U7.5 (P0A)
/BUCK_0/RUN: R22.2, U6.A10 (RUN)
/BUCK_0/TRACK/SS: C22.2, U6.A9 (TRACK/SS)
/BUCK_0/Vfb: C27.2, R23.1, U6.F12 (VFB)
/BUCK_0/Vin+: C18.2, R18.2, U5.10 (Vin+)
/BUCK_0/Vin-: C18.1, R19.2, U5.9 (Vin-)
/CS0: U7.1 (*CS); also elsewhere on the board
/NEG_0: C14.2, C15.2, C16.2, C17.2, C22.1, C23.2, C24.2, C25.2, C26.2, R21.2, U4.1 (-IN), U6.A8 (MODE_PLLIN), U6.B7 (GND), U6.B9 (GND), U6.C7 (GND), U6.C9 (GND), U6.D1 (GND), U6.D2 (GND), U6.D3 (GND), U6.D4 (GND), U6.D5 (GND), U6.D6 (GND), U6.D8 (GND), U6.E1 (GND), U6.E2 (GND), U6.E3 (GND), U6.E4 (GND), U6.E5 (GND), U6.E6 (GND), U6.E7 (GND), U6.E9 (GND), U6.F1 (GND), U6.F2 (GND), U6.F3 (GND), U6.F4 (GND), U6.F5 (GND), U6.F6 (GND), U6.F7 (GND), U6.F8 (GND), U6.F9 (GND), U6.G1 (GND), U6.G2 (GND), U6.G3 (GND), U6.G4 (GND), U6.G5 (GND), U6.G6 (GND), U6.G7 (GND), U6.G8 (GND), U6.G9 (GND), U6.G11 (SGND), U6.H1 (GND), U6.H2 (GND), U6.H3 (GND), U6.H4 (GND), U6.H5 (GND), U6.H6 (GND), U6.H7 (GND), U6.H8 (GND), U6.H9 (GND), U6.H11 (SGND), U6.H12 (SGND), U6.M12 (VOSNS-), U7.6 (P0W); also elsewhere on the board
/NEG_1: C23.1, C24.1, C25.1, C26.1, C27.1, U6.J1 (VOUT), U6.J2 (VOUT), U6.J3 (VOUT), U6.J4 (VOUT), U6.J5 (VOUT), U6.J6 (VOUT), U6.J7 (VOUT), U6.J8 (VOUT), U6.J9 (VOUT), U6.J10 (VOUT), U6.J12 (VOSNS+), U6.K1 (VOUT), U6.K2 (VOUT), U6.K3 (VOUT), U6.K4 (VOUT), U6.K5 (VOUT), U6.K6 (VOUT), U6.K7 (VOUT), U6.K8 (VOUT), U6.K9 (VOUT), U6.K10 (VOUT), U6.K11 (VOUT), U6.L1 (VOUT), U6.L2 (VOUT), U6.L3 (VOUT), U6.L4 (VOUT), U6.L5 (VOUT), U6.L6 (VOUT), U6.L7 (VOUT), U6.L8 (VOUT), U6.L9 (VOUT), U6.L10 (VOUT), U6.L11 (VOUT), U6.M1 (VOUT), U6.M2 (VOUT), U6.M3 (VOUT), U6.M4 (VOUT), U6.M5 (VOUT), U6.M6 (VOUT), U6.M7 (VOUT), U6.M8 (VOUT), U6.M9 (VOUT), U6.M10 (VOUT), U6.M11 (VOUT); also elsewhere on the board
/PV_POS_0: R17.1, R18.1, R20.1; also elsewhere on the board
/SCK: U7.2 (SCK); also elsewhere on the board
/SCL: U5.5 (SCL); also elsewhere on the board
/SDA: U5.4 (SDA); also elsewhere on the board
/SDIO: U7.3 (SDI/SDO); also elsewhere on the board
GND: C19.2, C20.2, C21.2, C28.2, U4.2 (AGND), U4.3 (-VS), U5.1 (A1), U5.2 (A0), U5.7 (GND), U7.4 (VSS); also elsewhere on the board
unnamed: C20.1, U4.4 (FILTER)
unnamed: JP1.1 (A), TP12.1, U6.K12 (DIFFVOUT)
unnamed: JP1.2 (B), TP11.1, U6.L12 (VOUT_LCL)
unnamed: TP6.1, U6.A7 (INTVCC)
unnamed: TP7.1, U4.5 (OUT), U5.8 (Vbus)
unnamed: TP8.1, U6.F11 (PGOOD), U6.G12 (PGOOD)
unnamed: TP9.1, U6.B12 (PLLFLTR/FSET)
unnamed: TP10.1, U6.A11 (COMP)

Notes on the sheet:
Addr=0x40
10:1 divider
the measured voltage is divided and then amplified by 10 as to simulate a follower. This is done to make use of the AD626 (low price and availability).
Power Measurement
Output voltage is set by varying Rfb with a digipot. SPI = 00
Adjustable Rfb
Extra mounting
G=10

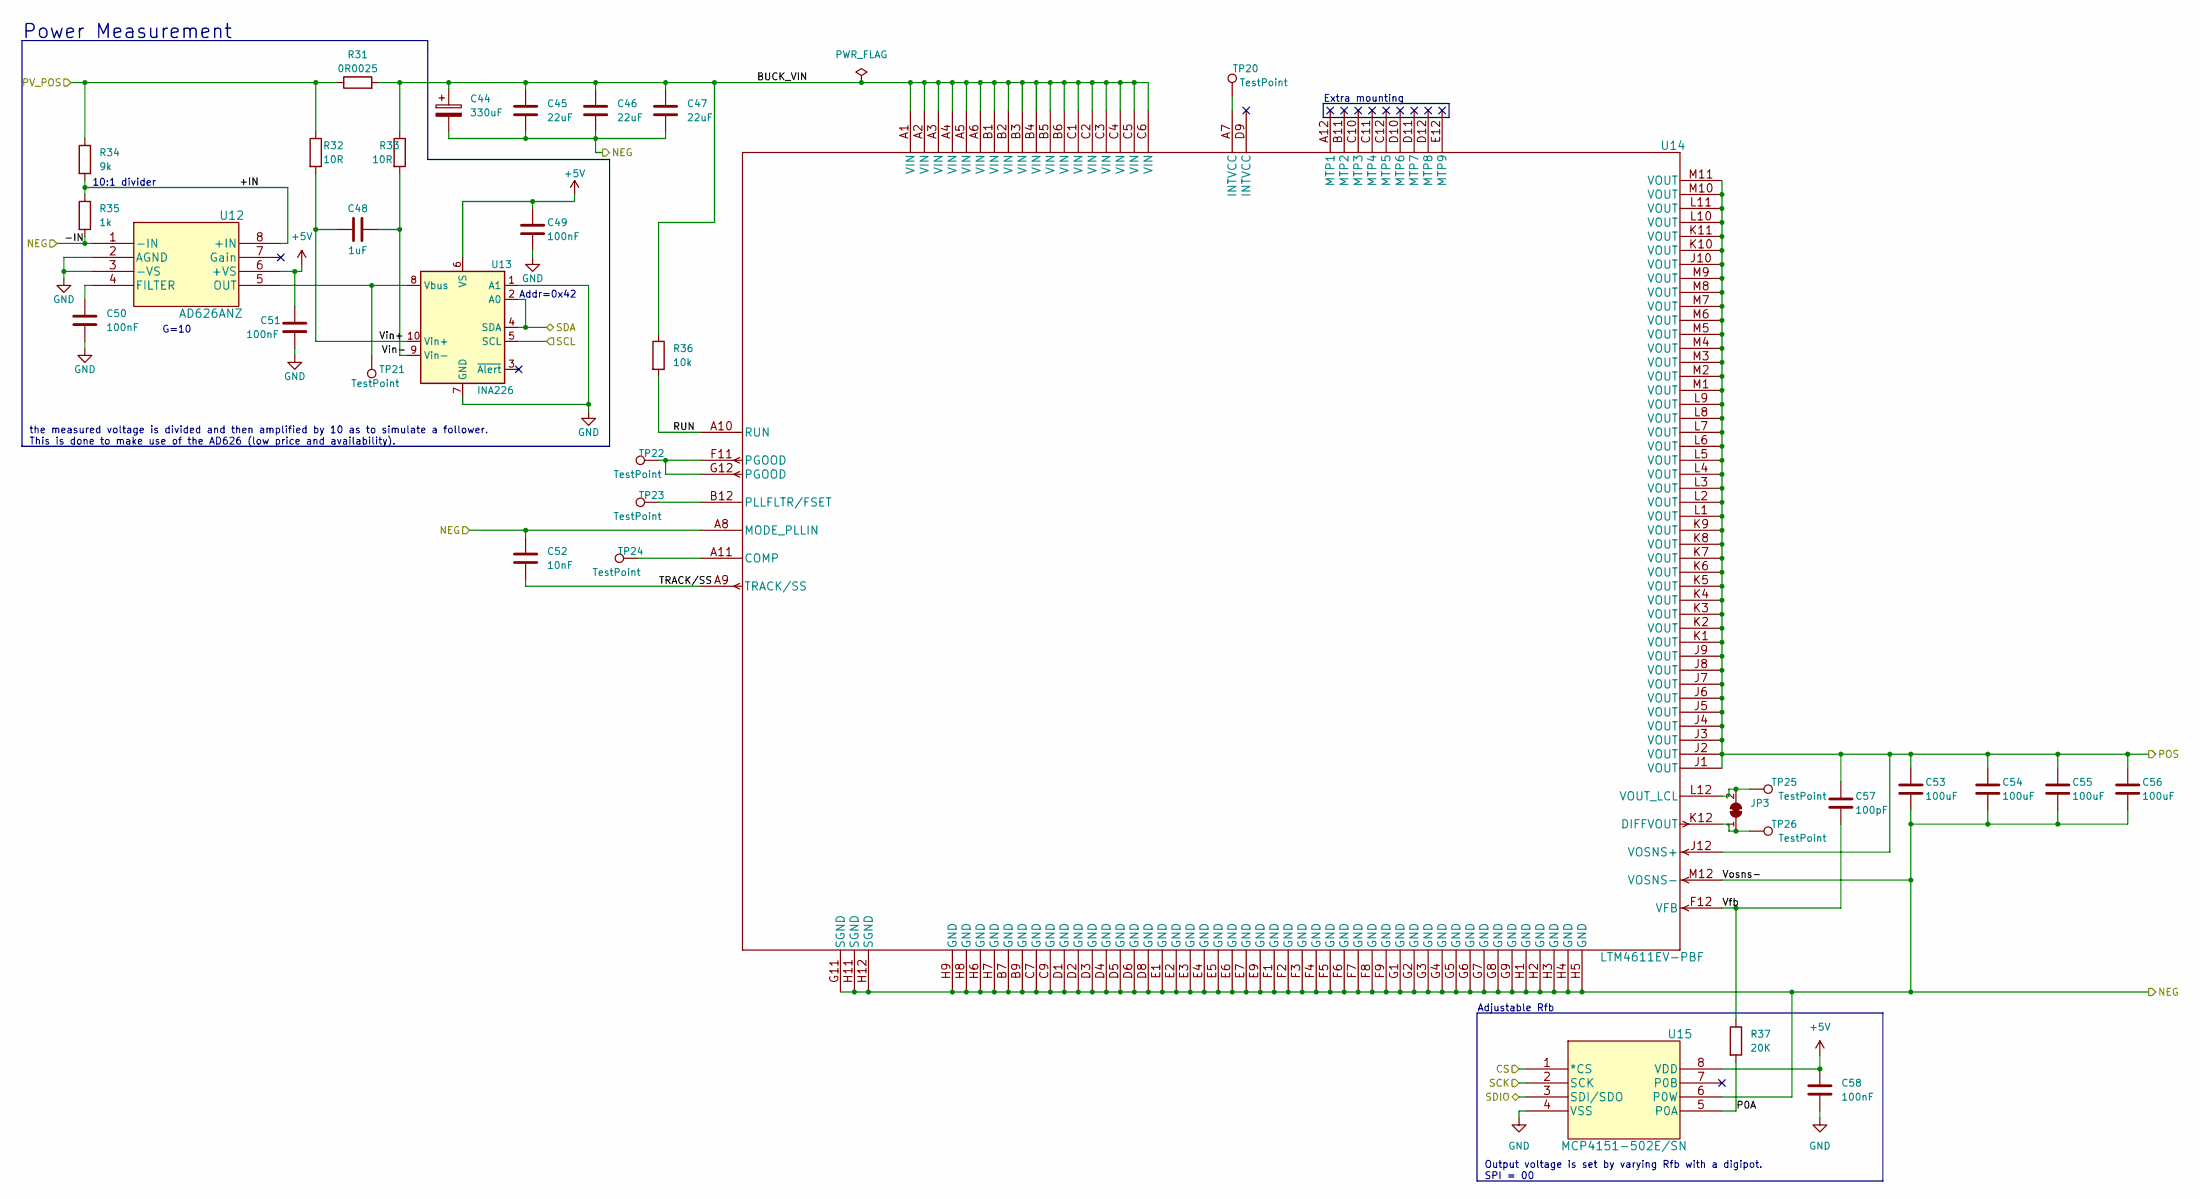
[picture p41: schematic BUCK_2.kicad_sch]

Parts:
C44: 330uF; CP_Elec_8x6.9
C45, C46, C47: 22uF; C_0805_2012Metric
C48: 1uF; C_0603_1608Metric
C49, C50, C51, C58: 100nF; C_0603_1608Metric
C52: 10nF; C_0603_1608Metric
C53, C54, C55, C56: 100uF; C_1206_3216Metric
C57: 100pF; C_0603_1608Metric
JP3: SolderJumper_2_Bridged; SolderJumper-2_P1.3mm_Bridged_RoundedPad1.0x1.5mm
R31: 0R0025; R_1206_3216Metric
R32, R33: 10R; R_0805_2012Metric
R34: 9k; R_0805_2012Metric
R35: 1k; R_0805_2012Metric
R36: 10k; R_0805_2012Metric
R37: 20K; R_0805_2012Metric
TP20, TP21, TP22, TP23, TP24, TP25, TP26: TestPoint; TestPoint_Pad_D2.0mm
U12: AD626ANZ; DIP-8_W7.62mm_Socket_LongPads
U13: INA226; VSSOP-10_3x3mm_P0.5mm
U14: LTM4611EV-PBF; Linear_LGA-133_15.0x15.0mm_Layout12x12_P1.27mm
U15: MCP4151-502E/SN; MSOP-8_3x3mm_P0.65mm

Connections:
+5V: C49.1, C51.1, C58.1, U12.6 (+VS), U13.6 (VS), U15.8 (VDD); also elsewhere on the board
/BUCK_2/+IN: R34.2, R35.1, U12.8 (+IN)
/BUCK_2/BUCK_VIN: C44.1, C45.1, C46.1, C47.1, R31.2, R33.1, R36.1, U14.A1 (VIN), U14.A2 (VIN), U14.A3 (VIN), U14.A4 (VIN), U14.A5 (VIN), U14.A6 (VIN), U14.B1 (VIN), U14.B2 (VIN), U14.B3 (VIN), U14.B4 (VIN), U14.B5 (VIN), U14.B6 (VIN), U14.C1 (VIN), U14.C2 (VIN), U14.C3 (VIN), U14.C4 (VIN), U14.C5 (VIN), U14.C6 (VIN)
/BUCK_2/P0A: R37.2, U15.5 (P0A)
/BUCK_2/RUN: R36.2, U14.A10 (RUN)
/BUCK_2/TRACK/SS: C52.2, U14.A9 (TRACK/SS)
/BUCK_2/Vfb: C57.2, R37.1, U14.F12 (VFB)
/BUCK_2/Vin+: C48.1, R32.2, U13.10 (Vin+)
/BUCK_2/Vin-: C48.2, R33.2, U13.9 (Vin-)
/CS2: U15.1 (*CS); also elsewhere on the board
/NEG_2: C44.2, C45.2, C46.2, C47.2, C52.1, C53.2, C54.2, C55.2, C56.2, R35.2, U12.1 (-IN), U14.A8 (MODE_PLLIN), U14.B7 (GND), U14.B9 (GND), U14.C7 (GND), U14.C9 (GND), U14.D1 (GND), U14.D2 (GND), U14.D3 (GND), U14.D4 (GND), U14.D5 (GND), U14.D6 (GND), U14.D8 (GND), U14.E1 (GND), U14.E2 (GND), U14.E3 (GND), U14.E4 (GND), U14.E5 (GND), U14.E6 (GND), U14.E7 (GND), U14.E9 (GND), U14.F1 (GND), U14.F2 (GND), U14.F3 (GND), U14.F4 (GND), U14.F5 (GND), U14.F6 (GND), U14.F7 (GND), U14.F8 (GND), U14.F9 (GND), U14.G1 (GND), U14.G2 (GND), U14.G3 (GND), U14.G4 (GND), U14.G5 (GND), U14.G6 (GND), U14.G7 (GND), U14.G8 (GND), U14.G9 (GND), U14.G11 (SGND), U14.H1 (GND), U14.H2 (GND), U14.H3 (GND), U14.H4 (GND), U14.H5 (GND), U14.H6 (GND), U14.H7 (GND), U14.H8 (GND), U14.H9 (GND), U14.H11 (SGND), U14.H12 (SGND), U14.M12 (VOSNS-), U15.6 (P0W); also elsewhere on the board
/NEG_3: C53.1, C54.1, C55.1, C56.1, C57.1, U14.J1 (VOUT), U14.J2 (VOUT), U14.J3 (VOUT), U14.J4 (VOUT), U14.J5 (VOUT), U14.J6 (VOUT), U14.J7 (VOUT), U14.J8 (VOUT), U14.J9 (VOUT), U14.J10 (VOUT), U14.J12 (VOSNS+), U14.K1 (VOUT), U14.K2 (VOUT), U14.K3 (VOUT), U14.K4 (VOUT), U14.K5 (VOUT), U14.K6 (VOUT), U14.K7 (VOUT), U14.K8 (VOUT), U14.K9 (VOUT), U14.K10 (VOUT), U14.K11 (VOUT), U14.L1 (VOUT), U14.L2 (VOUT), U14.L3 (VOUT), U14.L4 (VOUT), U14.L5 (VOUT), U14.L6 (VOUT), U14.L7 (VOUT), U14.L8 (VOUT), U14.L9 (VOUT), U14.L10 (VOUT), U14.L11 (VOUT), U14.M1 (VOUT), U14.M2 (VOUT), U14.M3 (VOUT), U14.M4 (VOUT), U14.M5 (VOUT), U14.M6 (VOUT), U14.M7 (VOUT), U14.M8 (VOUT), U14.M9 (VOUT), U14.M10 (VOUT), U14.M11 (VOUT); also elsewhere on the board
/PV_POS_2: R31.1, R32.1, R34.1; also elsewhere on the board
/SCK: U15.2 (SCK); also elsewhere on the board
/SCL: U13.5 (SCL); also elsewhere on the board
/SDA: U13.2 (A0), U13.4 (SDA); also elsewhere on the board
/SDIO: U15.3 (SDI/SDO); also elsewhere on the board
GND: C49.2, C50.2, C51.2, C58.2, U12.2 (AGND), U12.3 (-VS), U13.1 (A1), U13.7 (GND), U15.4 (VSS); also elsewhere on the board
unnamed: C50.1, U12.4 (FILTER)
unnamed: JP3.1 (A), TP26.1, U14.K12 (DIFFVOUT)
unnamed: JP3.2 (B), TP25.1, U14.L12 (VOUT_LCL)
unnamed: TP20.1, U14.A7 (INTVCC)
unnamed: TP21.1, U12.5 (OUT), U13.8 (Vbus)
unnamed: TP22.1, U14.F11 (PGOOD), U14.G12 (PGOOD)
unnamed: TP23.1, U14.B12 (PLLFLTR/FSET)
unnamed: TP24.1, U14.A11 (COMP)

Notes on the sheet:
the measured voltage is divided and then amplified by 10 as to simulate a follower. This is done to make use of the AD626 (low price and availability).
Extra mounting
G=10
10:1 divider
Adjustable Rfb
Addr=0x42
Output voltage is set by varying Rfb with a digipot. SPI = 00
Power Measurement

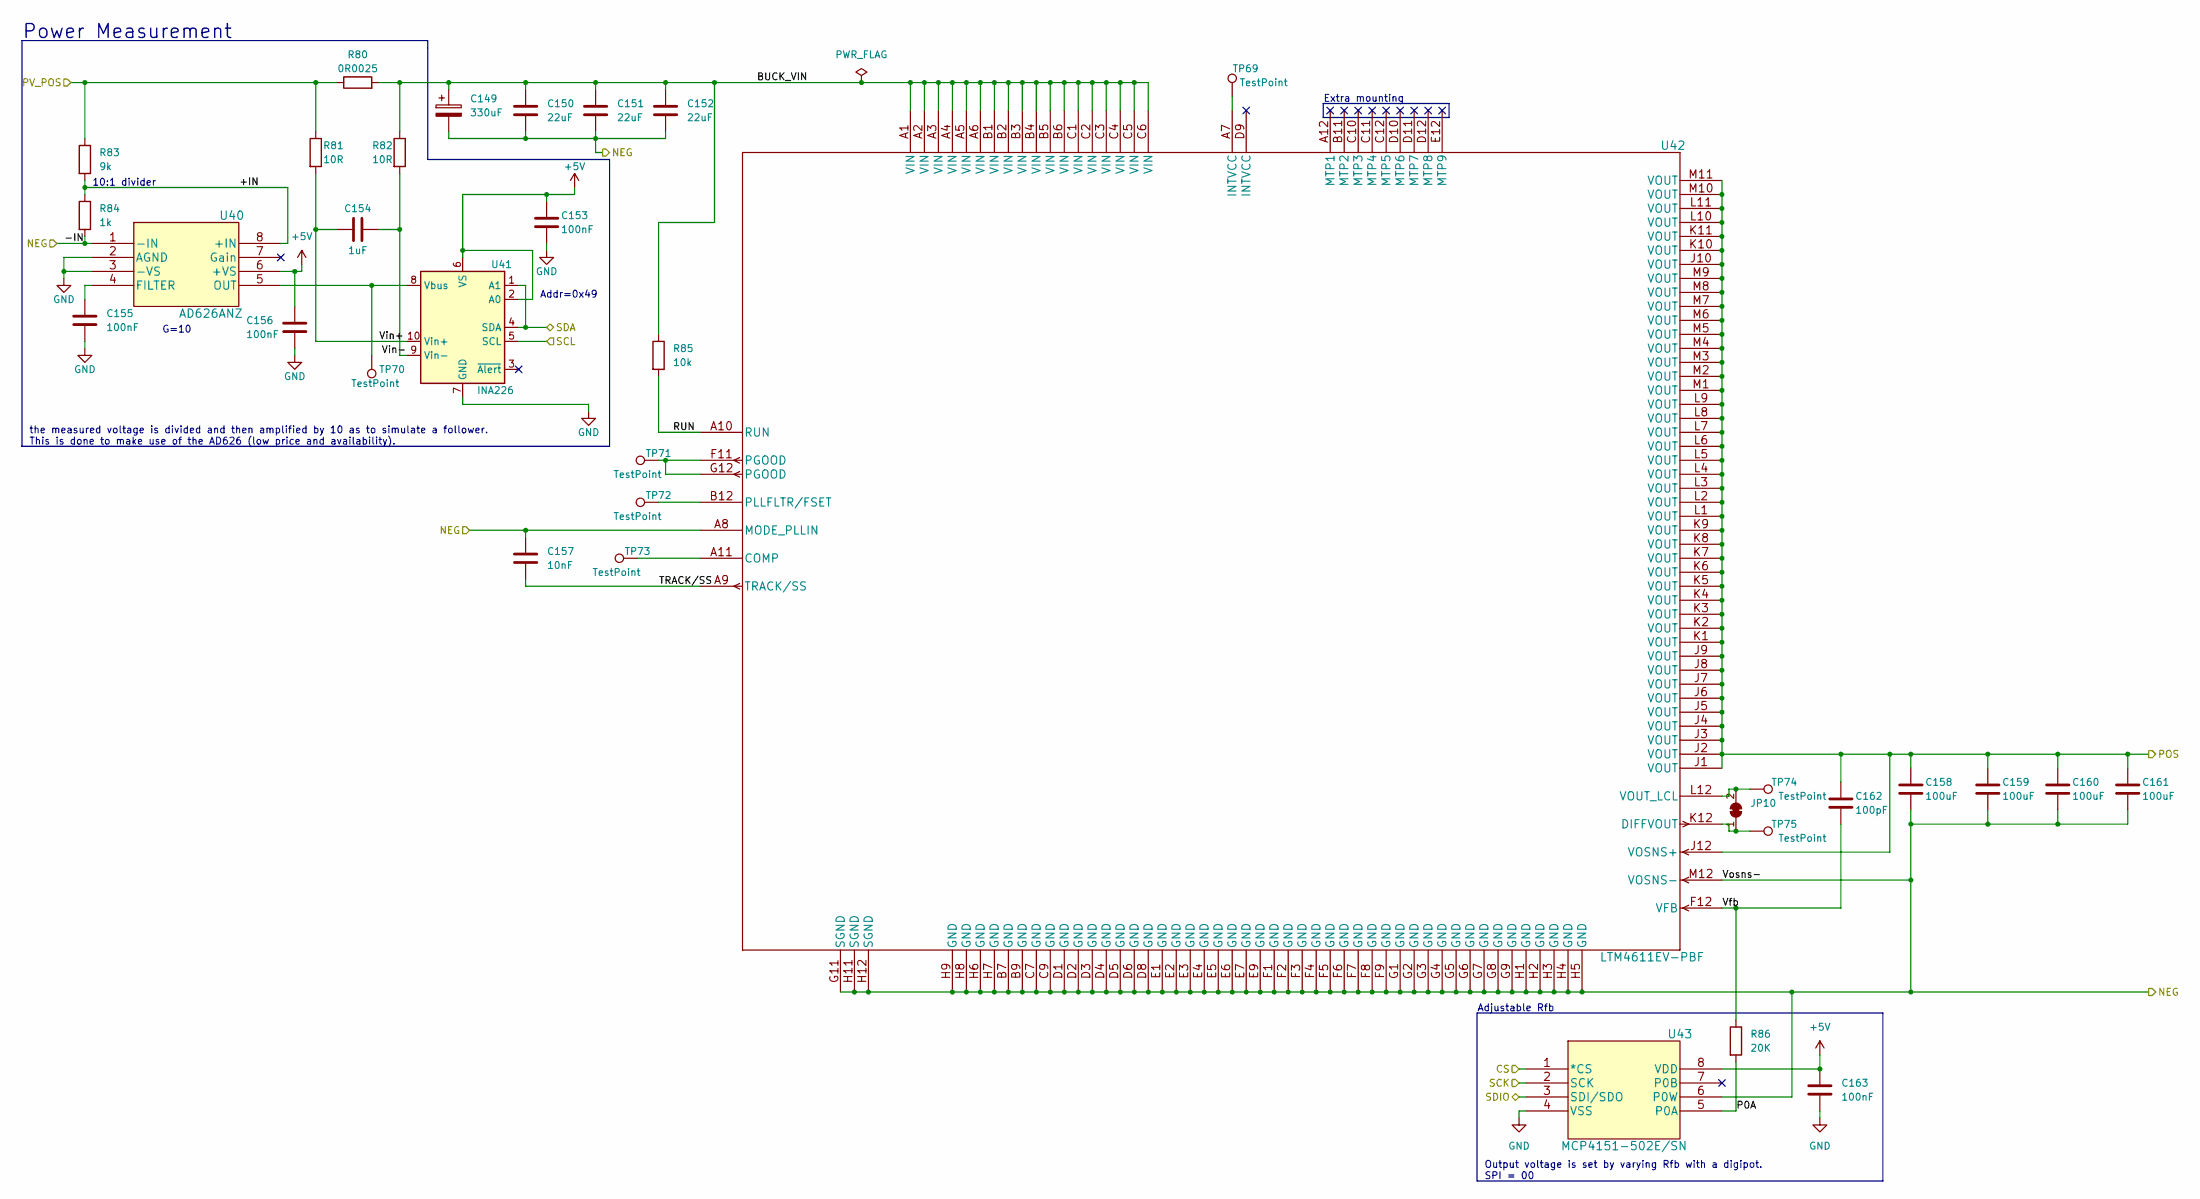
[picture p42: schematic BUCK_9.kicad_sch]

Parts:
C149: 330uF; CP_Elec_8x6.9
C150, C151, C152: 22uF; C_0805_2012Metric
C153, C155, C156, C163: 100nF; C_0603_1608Metric
C154: 1uF; C_0603_1608Metric
C157: 10nF; C_0603_1608Metric
C158, C159, C160, C161: 100uF; C_1206_3216Metric
C162: 100pF; C_0603_1608Metric
JP10: SolderJumper_2_Bridged; SolderJumper-2_P1.3mm_Bridged_RoundedPad1.0x1.5mm
R80: 0R0025; R_1206_3216Metric
R81, R82: 10R; R_0805_2012Metric
R83: 9k; R_0805_2012Metric
R84: 1k; R_0805_2012Metric
R85: 10k; R_0805_2012Metric
R86: 20K; R_0805_2012Metric
TP69, TP70, TP71, TP72, TP73, TP74, TP75: TestPoint; TestPoint_Pad_D2.0mm
U40: AD626ANZ; DIP-8_W7.62mm_Socket_LongPads
U41: INA226; VSSOP-10_3x3mm_P0.5mm
U42: LTM4611EV-PBF; Linear_LGA-133_15.0x15.0mm_Layout12x12_P1.27mm
U43: MCP4151-502E/SN; MSOP-8_3x3mm_P0.65mm

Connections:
+5V: C153.1, C156.1, C163.1, U40.6 (+VS), U41.2 (A0), U41.6 (VS), U43.8 (VDD); also elsewhere on the board
/BUCK_9/+IN: R83.2, R84.1, U40.8 (+IN)
/BUCK_9/BUCK_VIN: C149.1, C150.1, C151.1, C152.1, R80.2, R82.1, R85.1, U42.A1 (VIN), U42.A2 (VIN), U42.A3 (VIN), U42.A4 (VIN), U42.A5 (VIN), U42.A6 (VIN), U42.B1 (VIN), U42.B2 (VIN), U42.B3 (VIN), U42.B4 (VIN), U42.B5 (VIN), U42.B6 (VIN), U42.C1 (VIN), U42.C2 (VIN), U42.C3 (VIN), U42.C4 (VIN), U42.C5 (VIN), U42.C6 (VIN)
/BUCK_9/P0A: R86.2, U43.5 (P0A)
/BUCK_9/RUN: R85.2, U42.A10 (RUN)
/BUCK_9/TRACK/SS: C157.2, U42.A9 (TRACK/SS)
/BUCK_9/Vfb: C162.2, R86.1, U42.F12 (VFB)
/BUCK_9/Vin+: C154.1, R81.2, U41.10 (Vin+)
/BUCK_9/Vin-: C154.2, R82.2, U41.9 (Vin-)
/CS9: U43.1 (*CS); also elsewhere on the board
/NEG_9: C149.2, C150.2, C151.2, C152.2, C157.1, C158.2, C159.2, C160.2, C161.2, R84.2, U40.1 (-IN), U42.A8 (MODE_PLLIN), U42.B7 (GND), U42.B9 (GND), U42.C7 (GND), U42.C9 (GND), U42.D1 (GND), U42.D2 (GND), U42.D3 (GND), U42.D4 (GND), U42.D5 (GND), U42.D6 (GND), U42.D8 (GND), U42.E1 (GND), U42.E2 (GND), U42.E3 (GND), U42.E4 (GND), U42.E5 (GND), U42.E6 (GND), U42.E7 (GND), U42.E9 (GND), U42.F1 (GND), U42.F2 (GND), U42.F3 (GND), U42.F4 (GND), U42.F5 (GND), U42.F6 (GND), U42.F7 (GND), U42.F8 (GND), U42.F9 (GND), U42.G1 (GND), U42.G2 (GND), U42.G3 (GND), U42.G4 (GND), U42.G5 (GND), U42.G6 (GND), U42.G7 (GND), U42.G8 (GND), U42.G9 (GND), U42.G11 (SGND), U42.H1 (GND), U42.H2 (GND), U42.H3 (GND), U42.H4 (GND), U42.H5 (GND), U42.H6 (GND), U42.H7 (GND), U42.H8 (GND), U42.H9 (GND), U42.H11 (SGND), U42.H12 (SGND), U42.M12 (VOSNS-), U43.6 (P0W); also elsewhere on the board
/POS_9: C158.1, C159.1, C160.1, C161.1, C162.1, U42.J1 (VOUT), U42.J2 (VOUT), U42.J3 (VOUT), U42.J4 (VOUT), U42.J5 (VOUT), U42.J6 (VOUT), U42.J7 (VOUT), U42.J8 (VOUT), U42.J9 (VOUT), U42.J10 (VOUT), U42.J12 (VOSNS+), U42.K1 (VOUT), U42.K2 (VOUT), U42.K3 (VOUT), U42.K4 (VOUT), U42.K5 (VOUT), U42.K6 (VOUT), U42.K7 (VOUT), U42.K8 (VOUT), U42.K9 (VOUT), U42.K10 (VOUT), U42.K11 (VOUT), U42.L1 (VOUT), U42.L2 (VOUT), U42.L3 (VOUT), U42.L4 (VOUT), U42.L5 (VOUT), U42.L6 (VOUT), U42.L7 (VOUT), U42.L8 (VOUT), U42.L9 (VOUT), U42.L10 (VOUT), U42.L11 (VOUT), U42.M1 (VOUT), U42.M2 (VOUT), U42.M3 (VOUT), U42.M4 (VOUT), U42.M5 (VOUT), U42.M6 (VOUT), U42.M7 (VOUT), U42.M8 (VOUT), U42.M9 (VOUT), U42.M10 (VOUT), U42.M11 (VOUT); also elsewhere on the board
/PV_POS_9: R80.1, R81.1, R83.1; also elsewhere on the board
/SCK: U43.2 (SCK); also elsewhere on the board
/SCL: U41.5 (SCL); also elsewhere on the board
/SDA: U41.1 (A1), U41.4 (SDA); also elsewhere on the board
/SDIO: U43.3 (SDI/SDO); also elsewhere on the board
GND: C153.2, C155.2, C156.2, C163.2, U40.2 (AGND), U40.3 (-VS), U41.7 (GND), U43.4 (VSS); also elsewhere on the board
unnamed: C155.1, U40.4 (FILTER)
unnamed: JP10.1 (A), TP75.1, U42.K12 (DIFFVOUT)
unnamed: JP10.2 (B), TP74.1, U42.L12 (VOUT_LCL)
unnamed: TP69.1, U42.A7 (INTVCC)
unnamed: TP70.1, U40.5 (OUT), U41.8 (Vbus)
unnamed: TP71.1, U42.F11 (PGOOD), U42.G12 (PGOOD)
unnamed: TP72.1, U42.B12 (PLLFLTR/FSET)
unnamed: TP73.1, U42.A11 (COMP)

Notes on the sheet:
Adjustable Rfb
Output voltage is set by varying Rfb with a digipot. SPI = 00
10:1 divider
Addr=0x49
G=10
Extra mounting
the measured voltage is divided and then amplified by 10 as to simulate a follower. This is done to make use of the AD626 (low price and availability).
Power Measurement

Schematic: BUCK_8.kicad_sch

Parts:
C134: 330uF; CP_Elec_8x6.9
C135, C136, C137: 22uF; C_0805_2012Metric
C138, C140, C141, C148: 100nF; C_0603_1608Metric
C139: 1uF; C_0603_1608Metric
C142: 10nF; C_0603_1608Metric
C143, C144, C145, C146: 100uF; C_1206_3216Metric
C147: 100pF; C_0603_1608Metric
JP9: SolderJumper_2_Bridged; SolderJumper-2_P1.3mm_Bridged_RoundedPad1.0x1.5mm
R73: 0R0025; R_1206_3216Metric
R74, R75: 10R; R_0805_2012Metric
R76: 9k; R_0805_2012Metric
R77: 1k; R_0805_2012Metric
R78: 10k; R_0805_2012Metric
R79: 20K; R_0805_2012Metric
TP62, TP63, TP64, TP65, TP66, TP67, TP68: TestPoint; TestPoint_Pad_D2.0mm
U36: AD626ANZ; DIP-8_W7.62mm_Socket_LongPads
U37: INA226; VSSOP-10_3x3mm_P0.5mm
U38: LTM4611EV-PBF; Linear_LGA-133_15.0x15.0mm_Layout12x12_P1.27mm
U39: MCP4151-502E/SN; MSOP-8_3x3mm_P0.65mm

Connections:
+5V: C138.1, C141.1, C148.1, U36.6 (+VS), U37.6 (VS), U39.8 (VDD); also elsewhere on the board
/BUCK_8/+IN: R76.2, R77.1, U36.8 (+IN)
/BUCK_8/BUCK_VIN: C134.1, C135.1, C136.1, C137.1, R73.2, R75.1, R78.1, U38.A1 (VIN), U38.A2 (VIN), U38.A3 (VIN), U38.A4 (VIN), U38.A5 (VIN), U38.A6 (VIN), U38.B1 (VIN), U38.B2 (VIN), U38.B3 (VIN), U38.B4 (VIN), U38.B5 (VIN), U38.B6 (VIN), U38.C1 (VIN), U38.C2 (VIN), U38.C3 (VIN), U38.C4 (VIN), U38.C5 (VIN), U38.C6 (VIN)
/BUCK_8/P0A: R79.2, U39.5 (P0A)
/BUCK_8/RUN: R78.2, U38.A10 (RUN)
/BUCK_8/TRACK/SS: C142.2, U38.A9 (TRACK/SS)
/BUCK_8/Vfb: C147.2, R79.1, U38.F12 (VFB)
/BUCK_8/Vin+: C139.1, R74.2, U37.10 (Vin+)
/BUCK_8/Vin-: C139.2, R75.2, U37.9 (Vin-)
/CS8: U39.1 (*CS); also elsewhere on the board
/NEG_8: C134.2, C135.2, C136.2, C137.2, C142.1, C143.2, C144.2, C145.2, C146.2, R77.2, U36.1 (-IN), U38.A8 (MODE_PLLIN), U38.B7 (GND), U38.B9 (GND), U38.C7 (GND), U38.C9 (GND), U38.D1 (GND), U38.D2 (GND), U38.D3 (GND), U38.D4 (GND), U38.D5 (GND), U38.D6 (GND), U38.D8 (GND), U38.E1 (GND), U38.E2 (GND), U38.E3 (GND), U38.E4 (GND), U38.E5 (GND), U38.E6 (GND), U38.E7 (GND), U38.E9 (GND), U38.F1 (GND), U38.F2 (GND), U38.F3 (GND), U38.F4 (GND), U38.F5 (GND), U38.F6 (GND), U38.F7 (GND), U38.F8 (GND), U38.F9 (GND), U38.G1 (GND), U38.G2 (GND), U38.G3 (GND), U38.G4 (GND), U38.G5 (GND), U38.G6 (GND), U38.G7 (GND), U38.G8 (GND), U38.G9 (GND), U38.G11 (SGND), U38.H1 (GND), U38.H2 (GND), U38.H3 (GND), U38.H4 (GND), U38.H5 (GND), U38.H6 (GND), U38.H7 (GND), U38.H8 (GND), U38.H9 (GND), U38.H11 (SGND), U38.H12 (SGND), U38.M12 (VOSNS-), U39.6 (P0W); also elsewhere on the board
/NEG_9: C143.1, C144.1, C145.1, C146.1, C147.1, U38.J1 (VOUT), U38.J2 (VOUT), U38.J3 (VOUT), U38.J4 (VOUT), U38.J5 (VOUT), U38.J6 (VOUT), U38.J7 (VOUT), U38.J8 (VOUT), U38.J9 (VOUT), U38.J10 (VOUT), U38.J12 (VOSNS+), U38.K1 (VOUT), U38.K2 (VOUT), U38.K3 (VOUT), U38.K4 (VOUT), U38.K5 (VOUT), U38.K6 (VOUT), U38.K7 (VOUT), U38.K8 (VOUT), U38.K9 (VOUT), U38.K10 (VOUT), U38.K11 (VOUT), U38.L1 (VOUT), U38.L2 (VOUT), U38.L3 (VOUT), U38.L4 (VOUT), U38.L5 (VOUT), U38.L6 (VOUT), U38.L7 (VOUT), U38.L8 (VOUT), U38.L9 (VOUT), U38.L10 (VOUT), U38.L11 (VOUT), U38.M1 (VOUT), U38.M2 (VOUT), U38.M3 (VOUT), U38.M4 (VOUT), U38.M5 (VOUT), U38.M6 (VOUT), U38.M7 (VOUT), U38.M8 (VOUT), U38.M9 (VOUT), U38.M10 (VOUT), U38.M11 (VOUT); also elsewhere on the board
/PV_POS_8: R73.1, R74.1, R76.1; also elsewhere on the board
/SCK: U39.2 (SCK); also elsewhere on the board
/SCL: U37.5 (SCL); also elsewhere on the board
/SDA: U37.1 (A1), U37.4 (SDA); also elsewhere on the board
/SDIO: U39.3 (SDI/SDO); also elsewhere on the board
GND: C138.2, C140.2, C141.2, C148.2, U36.2 (AGND), U36.3 (-VS), U37.2 (A0), U37.7 (GND), U39.4 (VSS); also elsewhere on the board
unnamed: C140.1, U36.4 (FILTER)
unnamed: JP9.1 (A), TP68.1, U38.K12 (DIFFVOUT)
unnamed: JP9.2 (B), TP67.1, U38.L12 (VOUT_LCL)
unnamed: TP62.1, U38.A7 (INTVCC)
unnamed: TP63.1, U36.5 (OUT), U37.8 (Vbus)
unnamed: TP64.1, U38.F11 (PGOOD), U38.G12 (PGOOD)
unnamed: TP65.1, U38.B12 (PLLFLTR/FSET)
unnamed: TP66.1, U38.A11 (COMP)

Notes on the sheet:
Addr=0x48
G=10
Power Measurement
the measured voltage is divided and then amplified by 10 as to simulate a follower. This is done to make use of the AD626 (low price and availability).
Adjustable Rfb
Extra mounting
Output voltage is set by varying Rfb with a digipot. SPI = 00
10:1 divider

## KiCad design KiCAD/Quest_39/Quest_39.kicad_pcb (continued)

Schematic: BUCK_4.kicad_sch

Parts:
C59: 330uF; CP_Elec_8x6.9
C60, C61, C62: 22uF; C_0805_2012Metric
C63, C65, C66, C73: 100nF; C_0603_1608Metric
C64: 1uF; C_0603_1608Metric
C67: 10nF; C_0603_1608Metric
C68, C69, C70, C71: 100uF; C_1206_3216Metric
C72: 100pF; C_0603_1608Metric
JP4: SolderJumper_2_Bridged; SolderJumper-2_P1.3mm_Bridged_RoundedPad1.0x1.5mm
R38: 0R0025; R_1206_3216Metric
R39, R40: 10R; R_0805_2012Metric
R41: 9k; R_0805_2012Metric
R42: 1k; R_0805_2012Metric
R43: 10k; R_0805_2012Metric
R44: 20K; R_0805_2012Metric
TP27, TP28, TP29, TP30, TP31, TP32, TP33: TestPoint; TestPoint_Pad_D2.0mm
U16: AD626ANZ; DIP-8_W7.62mm_Socket_LongPads
U17: INA226; VSSOP-10_3x3mm_P0.5mm
U18: LTM4611EV-PBF; Linear_LGA-133_15.0x15.0mm_Layout12x12_P1.27mm
U19: MCP4151-502E/SN; MSOP-8_3x3mm_P0.65mm

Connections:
+5V: C63.1, C66.1, C73.1, U16.6 (+VS), U17.1 (A1), U17.6 (VS), U19.8 (VDD); also elsewhere on the board
/BUCK_4/+IN: R41.2, R42.1, U16.8 (+IN)
/BUCK_4/BUCK_VIN: C59.1, C60.1, C61.1, C62.1, R38.2, R40.1, R43.1, U18.A1 (VIN), U18.A2 (VIN), U18.A3 (VIN), U18.A4 (VIN), U18.A5 (VIN), U18.A6 (VIN), U18.B1 (VIN), U18.B2 (VIN), U18.B3 (VIN), U18.B4 (VIN), U18.B5 (VIN), U18.B6 (VIN), U18.C1 (VIN), U18.C2 (VIN), U18.C3 (VIN), U18.C4 (VIN), U18.C5 (VIN), U18.C6 (VIN)
/BUCK_4/P0A: R44.2, U19.5 (P0A)
/BUCK_4/RUN: R43.2, U18.A10 (RUN)
/BUCK_4/TRACK/SS: C67.2, U18.A9 (TRACK/SS)
/BUCK_4/Vfb: C72.2, R44.1, U18.F12 (VFB)
/BUCK_4/Vin+: C64.1, R39.2, U17.10 (Vin+)
/BUCK_4/Vin-: C64.2, R40.2, U17.9 (Vin-)
/CS4: U19.1 (*CS); also elsewhere on the board
/NEG_4: C59.2, C60.2, C61.2, C62.2, C67.1, C68.2, C69.2, C70.2, C71.2, R42.2, U16.1 (-IN), U18.A8 (MODE_PLLIN), U18.B7 (GND), U18.B9 (GND), U18.C7 (GND), U18.C9 (GND), U18.D1 (GND), U18.D2 (GND), U18.D3 (GND), U18.D4 (GND), U18.D5 (GND), U18.D6 (GND), U18.D8 (GND), U18.E1 (GND), U18.E2 (GND), U18.E3 (GND), U18.E4 (GND), U18.E5 (GND), U18.E6 (GND), U18.E7 (GND), U18.E9 (GND), U18.F1 (GND), U18.F2 (GND), U18.F3 (GND), U18.F4 (GND), U18.F5 (GND), U18.F6 (GND), U18.F7 (GND), U18.F8 (GND), U18.F9 (GND), U18.G1 (GND), U18.G2 (GND), U18.G3 (GND), U18.G4 (GND), U18.G5 (GND), U18.G6 (GND), U18.G7 (GND), U18.G8 (GND), U18.G9 (GND), U18.G11 (SGND), U18.H1 (GND), U18.H2 (GND), U18.H3 (GND), U18.H4 (GND), U18.H5 (GND), U18.H6 (GND), U18.H7 (GND), U18.H8 (GND), U18.H9 (GND), U18.H11 (SGND), U18.H12 (SGND), U18.M12 (VOSNS-), U19.6 (P0W); also elsewhere on the board
/NEG_5: C68.1, C69.1, C70.1, C71.1, C72.1, U18.J1 (VOUT), U18.J2 (VOUT), U18.J3 (VOUT), U18.J4 (VOUT), U18.J5 (VOUT), U18.J6 (VOUT), U18.J7 (VOUT), U18.J8 (VOUT), U18.J9 (VOUT), U18.J10 (VOUT), U18.J12 (VOSNS+), U18.K1 (VOUT), U18.K2 (VOUT), U18.K3 (VOUT), U18.K4 (VOUT), U18.K5 (VOUT), U18.K6 (VOUT), U18.K7 (VOUT), U18.K8 (VOUT), U18.K9 (VOUT), U18.K10 (VOUT), U18.K11 (VOUT), U18.L1 (VOUT), U18.L2 (VOUT), U18.L3 (VOUT), U18.L4 (VOUT), U18.L5 (VOUT), U18.L6 (VOUT), U18.L7 (VOUT), U18.L8 (VOUT), U18.L9 (VOUT), U18.L10 (VOUT), U18.L11 (VOUT), U18.M1 (VOUT), U18.M2 (VOUT), U18.M3 (VOUT), U18.M4 (VOUT), U18.M5 (VOUT), U18.M6 (VOUT), U18.M7 (VOUT), U18.M8 (VOUT), U18.M9 (VOUT), U18.M10 (VOUT), U18.M11 (VOUT); also elsewhere on the board
/PV_POS_4: R38.1, R39.1, R41.1; also elsewhere on the board
/SCK: U19.2 (SCK); also elsewhere on the board
/SCL: U17.5 (SCL); also elsewhere on the board
/SDA: U17.4 (SDA); also elsewhere on the board
/SDIO: U19.3 (SDI/SDO); also elsewhere on the board
GND: C63.2, C65.2, C66.2, C73.2, U16.2 (AGND), U16.3 (-VS), U17.2 (A0), U17.7 (GND), U19.4 (VSS); also elsewhere on the board
unnamed: C65.1, U16.4 (FILTER)
unnamed: JP4.1 (A), TP33.1, U18.K12 (DIFFVOUT)
unnamed: JP4.2 (B), TP32.1, U18.L12 (VOUT_LCL)
unnamed: TP27.1, U18.A7 (INTVCC)
unnamed: TP28.1, U16.5 (OUT), U17.8 (Vbus)
unnamed: TP29.1, U18.F11 (PGOOD), U18.G12 (PGOOD)
unnamed: TP30.1, U18.B12 (PLLFLTR/FSET)
unnamed: TP31.1, U18.A11 (COMP)

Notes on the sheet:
Addr=0x44
10:1 divider
Power Measurement
Extra mounting
the measured voltage is divided and then amplified by 10 as to simulate a follower. This is done to make use of the AD626 (low price and availability).
Adjustable Rfb
G=10
Output voltage is set by varying Rfb with a digipot. SPI = 00

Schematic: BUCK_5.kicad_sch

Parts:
C89: 330uF; CP_Elec_8x6.9
C90, C91, C92: 22uF; C_0805_2012Metric
C93, C95, C96, C103: 100nF; C_0603_1608Metric
C94: 1uF; C_0603_1608Metric
C97: 10nF; C_0603_1608Metric
C98, C99, C100, C101: 100uF; C_1206_3216Metric
C102: 100pF; C_0603_1608Metric
JP6: SolderJumper_2_Bridged; SolderJumper-2_P1.3mm_Bridged_RoundedPad1.0x1.5mm
R52: 0R0025; R_1206_3216Metric
R53, R54: 10R; R_0805_2012Metric
R55: 9k; R_0805_2012Metric
R56: 1k; R_0805_2012Metric
R57: 10k; R_0805_2012Metric
R58: 20K; R_0805_2012Metric
TP41, TP42, TP43, TP44, TP45, TP46, TP47: TestPoint; TestPoint_Pad_D2.0mm
U24: AD626ANZ; DIP-8_W7.62mm_Socket_LongPads
U25: INA226; VSSOP-10_3x3mm_P0.5mm
U26: LTM4611EV-PBF; Linear_LGA-133_15.0x15.0mm_Layout12x12_P1.27mm
U27: MCP4151-502E/SN; MSOP-8_3x3mm_P0.65mm

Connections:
+5V: C93.1, C96.1, C103.1, U24.6 (+VS), U25.1 (A1), U25.2 (A0), U25.6 (VS), U27.8 (VDD); also elsewhere on the board
/BUCK_5/+IN: R55.2, R56.1, U24.8 (+IN)
/BUCK_5/BUCK_VIN: C89.1, C90.1, C91.1, C92.1, R52.2, R54.1, R57.1, U26.A1 (VIN), U26.A2 (VIN), U26.A3 (VIN), U26.A4 (VIN), U26.A5 (VIN), U26.A6 (VIN), U26.B1 (VIN), U26.B2 (VIN), U26.B3 (VIN), U26.B4 (VIN), U26.B5 (VIN), U26.B6 (VIN), U26.C1 (VIN), U26.C2 (VIN), U26.C3 (VIN), U26.C4 (VIN), U26.C5 (VIN), U26.C6 (VIN)
/BUCK_5/P0A: R58.2, U27.5 (P0A)
/BUCK_5/RUN: R57.2, U26.A10 (RUN)
/BUCK_5/TRACK/SS: C97.2, U26.A9 (TRACK/SS)
/BUCK_5/Vfb: C102.2, R58.1, U26.F12 (VFB)
/BUCK_5/Vin+: C94.1, R53.2, U25.10 (Vin+)
/BUCK_5/Vin-: C94.2, R54.2, U25.9 (Vin-)
/CS5: U27.1 (*CS); also elsewhere on the board
/NEG_5: C89.2, C90.2, C91.2, C92.2, C97.1, C98.2, C99.2, C100.2, C101.2, R56.2, U24.1 (-IN), U26.A8 (MODE_PLLIN), U26.B7 (GND), U26.B9 (GND), U26.C7 (GND), U26.C9 (GND), U26.D1 (GND), U26.D2 (GND), U26.D3 (GND), U26.D4 (GND), U26.D5 (GND), U26.D6 (GND), U26.D8 (GND), U26.E1 (GND), U26.E2 (GND), U26.E3 (GND), U26.E4 (GND), U26.E5 (GND), U26.E6 (GND), U26.E7 (GND), U26.E9 (GND), U26.F1 (GND), U26.F2 (GND), U26.F3 (GND), U26.F4 (GND), U26.F5 (GND), U26.F6 (GND), U26.F7 (GND), U26.F8 (GND), U26.F9 (GND), U26.G1 (GND), U26.G2 (GND), U26.G3 (GND), U26.G4 (GND), U26.G5 (GND), U26.G6 (GND), U26.G7 (GND), U26.G8 (GND), U26.G9 (GND), U26.G11 (SGND), U26.H1 (GND), U26.H2 (GND), U26.H3 (GND), U26.H4 (GND), U26.H5 (GND), U26.H6 (GND), U26.H7 (GND), U26.H8 (GND), U26.H9 (GND), U26.H11 (SGND), U26.H12 (SGND), U26.M12 (VOSNS-), U27.6 (P0W); also elsewhere on the board
/NEG_6: C98.1, C99.1, C100.1, C101.1, C102.1, U26.J1 (VOUT), U26.J2 (VOUT), U26.J3 (VOUT), U26.J4 (VOUT), U26.J5 (VOUT), U26.J6 (VOUT), U26.J7 (VOUT), U26.J8 (VOUT), U26.J9 (VOUT), U26.J10 (VOUT), U26.J12 (VOSNS+), U26.K1 (VOUT), U26.K2 (VOUT), U26.K3 (VOUT), U26.K4 (VOUT), U26.K5 (VOUT), U26.K6 (VOUT), U26.K7 (VOUT), U26.K8 (VOUT), U26.K9 (VOUT), U26.K10 (VOUT), U26.K11 (VOUT), U26.L1 (VOUT), U26.L2 (VOUT), U26.L3 (VOUT), U26.L4 (VOUT), U26.L5 (VOUT), U26.L6 (VOUT), U26.L7 (VOUT), U26.L8 (VOUT), U26.L9 (VOUT), U26.L10 (VOUT), U26.L11 (VOUT), U26.M1 (VOUT), U26.M2 (VOUT), U26.M3 (VOUT), U26.M4 (VOUT), U26.M5 (VOUT), U26.M6 (VOUT), U26.M7 (VOUT), U26.M8 (VOUT), U26.M9 (VOUT), U26.M10 (VOUT), U26.M11 (VOUT); also elsewhere on the board
/PV_POS_5: R52.1, R53.1, R55.1; also elsewhere on the board
/SCK: U27.2 (SCK); also elsewhere on the board
/SCL: U25.5 (SCL); also elsewhere on the board
/SDA: U25.4 (SDA); also elsewhere on the board
/SDIO: U27.3 (SDI/SDO); also elsewhere on the board
GND: C93.2, C95.2, C96.2, C103.2, U24.2 (AGND), U24.3 (-VS), U25.7 (GND), U27.4 (VSS); also elsewhere on the board
unnamed: C95.1, U24.4 (FILTER)
unnamed: JP6.1 (A), TP47.1, U26.K12 (DIFFVOUT)
unnamed: JP6.2 (B), TP46.1, U26.L12 (VOUT_LCL)
unnamed: TP41.1, U26.A7 (INTVCC)
unnamed: TP42.1, U24.5 (OUT), U25.8 (Vbus)
unnamed: TP43.1, U26.F11 (PGOOD), U26.G12 (PGOOD)
unnamed: TP44.1, U26.B12 (PLLFLTR/FSET)
unnamed: TP45.1, U26.A11 (COMP)

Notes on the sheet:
Extra mounting
the measured voltage is divided and then amplified by 10 as to simulate a follower. This is done to make use of the AD626 (low price and availability).
10:1 divider
Output voltage is set by varying Rfb with a digipot. SPI = 00
Adjustable Rfb
Power Measurement
G=10
Addr=0x45

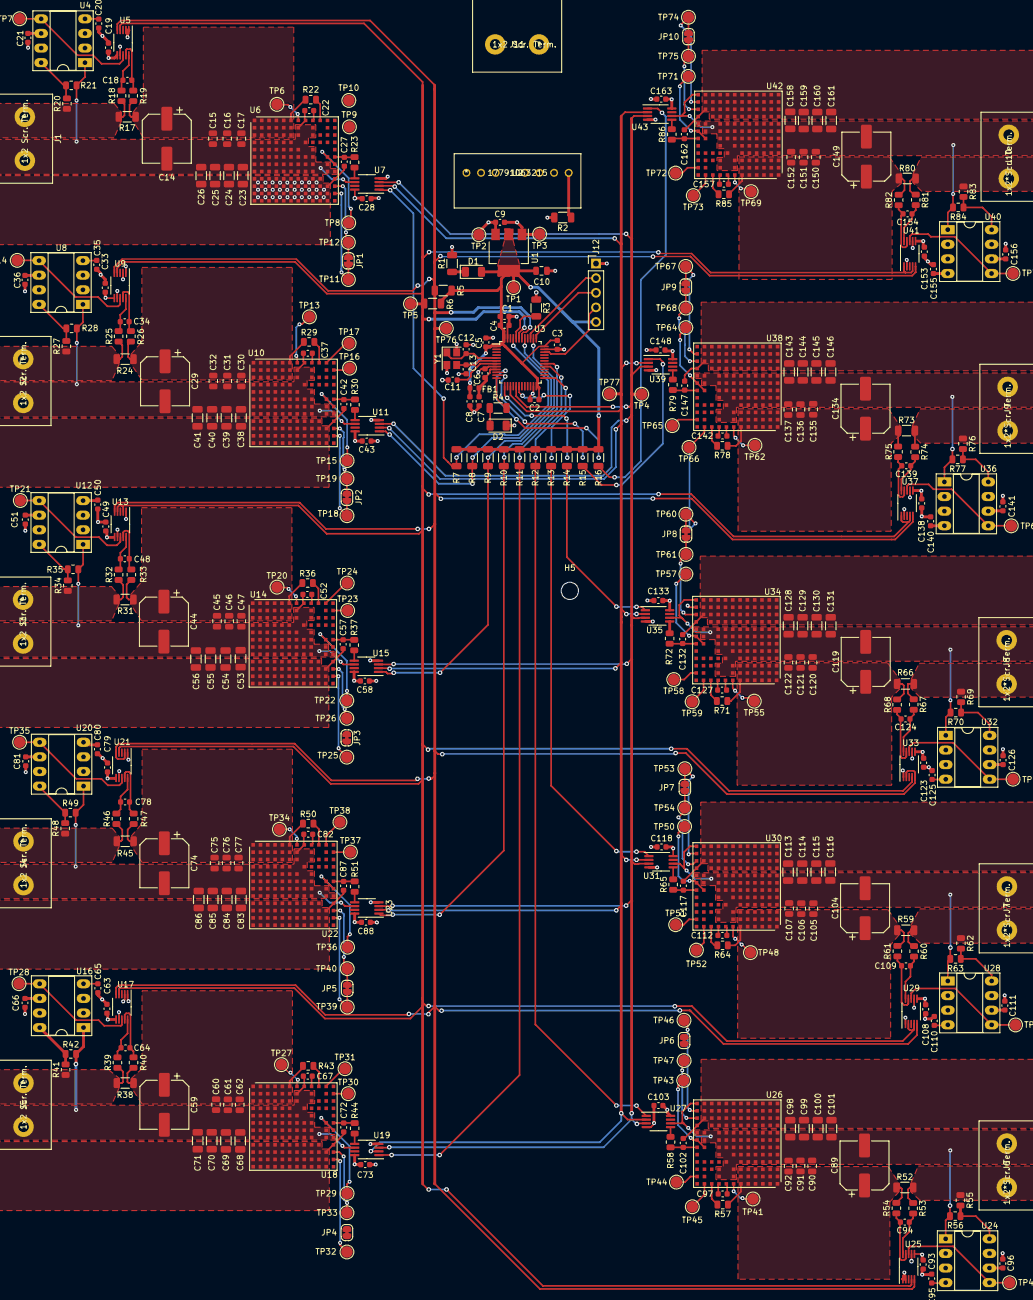
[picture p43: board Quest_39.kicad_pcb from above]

Board: 4 copper layers, 400 parts (0 on the bottom side), 210 nets.

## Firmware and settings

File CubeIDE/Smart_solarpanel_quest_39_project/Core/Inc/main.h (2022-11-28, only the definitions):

#define CS9_Pin GPIO_PIN_0
#define CS9_GPIO_Port GPIOA
#define CS8_Pin GPIO_PIN_1
#define CS8_GPIO_Port GPIOA
#define CS7_Pin GPIO_PIN_3
#define CS7_GPIO_Port GPIOA
#define CS6_Pin GPIO_PIN_0
#define CS6_GPIO_Port GPIOB
#define CS5_Pin GPIO_PIN_12
#define CS5_GPIO_Port GPIOB
#define CS4_Pin GPIO_PIN_8
#define CS4_GPIO_Port GPIOA
#define CS3_Pin GPIO_PIN_9
#define CS3_GPIO_Port GPIOA
#define CS2_Pin GPIO_PIN_15
#define CS2_GPIO_Port GPIOA
#define CS1_Pin GPIO_PIN_5
#define CS1_GPIO_Port GPIOB
#define CS0_Pin GPIO_PIN_9
#define CS0_GPIO_Port GPIOB

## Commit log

2022-11-28 Add project files.
    [Quest_39.kicad_pcb, Quest_39.kicad_sch, Quest_39_blz2.kicad_sch]
2022-11-28 Added KiCAD to .gitignore and removed ignored files
2022-12-05 Edited schematic
    [Quest_39.kicad_sch, Quest_39_blz2.kicad_sch]
2022-12-05 GND van INA226 verbonden, remote sense amplifier in gebruik genomen, labels aangepast en INTVCC not connected gemaakt.
    [Quest_39.kicad_sch, Quest_39_blz2.kicad_sch]
2022-12-05 Ordered BUCK_x schematic pages
    [BUCK_0.kicad_sch, BUCK_1.kicad_sch, BUCK_2.kicad_sch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]
2022-12-06 Added screw terminals. Ordered nets and added seperation between systems.
    [BUCK_0.kicad_sch, BUCK_1.kicad_sch, BUCK_2.kicad_sch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]
2022-12-06 Changed root schematic to A3 size.
    [Quest_39.kicad_sch]
2022-12-12 Exchanged MCP601 for AD626
    [BUCK_0.kicad_sch, Quest_39.kicad_sch]
2022-12-12 Added library for 5V buck converter
    [Quest_39.kicad_sch]
2022-12-12 Added 3.3 and 5v power supplies
    [Quest_39.kicad_sch]
2022-12-12 Done TODO items
    [BUCK_0.kicad_sch, Quest_39.kicad_sch]
2022-12-12 Fixed most ERC errors
    [BUCK_0.kicad_sch, BUCK_1.kicad_sch, BUCK_2.kicad_sch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]
2022-12-12 Ordered and anotated components
    [BUCK_0.kicad_sch, BUCK_1.kicad_sch, BUCK_2.kicad_sch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]
2022-12-12 Small changes made during schematic review w/ Joost
    [BUCK_0.kicad_sch, Quest_39.kicad_sch]
2022-12-12 Added weak SPI CS pullups to prevent spurious behaviour
    [BUCK_0.kicad_sch, BUCK_1.kicad_sch, BUCK_2.kicad_sch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]
2022-12-13 Gave all INA226's unique addresses
    [BUCK_0.kicad_sch, BUCK_1.kicad_sch, BUCK_2.kicad_sch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]
2022-12-13 Removed all ERC errors
    [BUCK_0.kicad_sch, BUCK_1.kicad_sch, BUCK_2.kicad_sch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]
2022-12-13 Assigned all schem. symbols their footprints
    [BUCK_0.kicad_sch, BUCK_1.kicad_sch, BUCK_2.kicad_sch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]
2022-12-19 Initial work on layout
    [BUCK_0.kicad_sch, BUCK_1.kicad_sch, BUCK_2.kicad_sch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]
2022-12-19 Fixed INA226 schem. mistake and further layout work
    [17791063215.PcbLib, 17791063215.SchLib, 17791063215.psm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]
2022-12-19 Completed first buck converter section PCB layout
    [Quest_39.kicad_pcb]
2022-12-19 Partial wiring of first buck converter section PCB layout
    [BUCK_0.kicad_sch, BUCK_1.kicad_sch, BUCK_2.kicad_sch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]
2022-12-27 Added second buck converter section PCB layout
    [Quest_39.kicad_pcb]
2023-01-09 Added 3rd buck converter section
    [BUCK_0.kicad_sch, BUCK_1.kicad_sch, BUCK_2.kicad_sch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]
2023-01-09 Placed 4th buck converter, started 5th.
    [BUCK_0.kicad_sch, BUCK_1.kicad_sch, BUCK_2.kicad_sch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]
2023-01-09 Finished placing 5th buck converter, started 6th
    [Quest_39.kicad_pcb]
2023-01-10 Finished placing all LTM4611EV buck-converters
    [Quest_39.kicad_pcb]
2023-01-10 Routed I2C SDA/SCL
    [Quest_39.kicad_pcb]
2023-01-15 Switched to 4-layer stack-up w/ dedicated +5V and GND planes to improve EMI and make routing for PWR-traces easier
    [Quest_39.kicad_pcb, Quest_39.kicad_sch]
2023-01-16 Redid layout for the LTM4611EV Buck-converters (Issues with net-assignment to IC pads)
    [BUCK_6.kicad_sch, BUCK_7.kicad_sch, BUCK_8.kicad_sch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]
2023-01-16 Change routing of bypass caps, routed 3.3v to micro.
    [Quest_39.kicad_pcb]
2023-01-17 Finished routing I2C, SPI and all 10 CS
    [Quest_39.kicad_pcb, Quest_39.kicad_sch]
2023-01-17 Top layer power planes added
    [Quest_39.kicad_pcb]
2023-01-17 Executed DRC and fixed issues. Started work on bottom power planes
    [Quest_39.kicad_pcb]
2023-01-17 Routed and stitched ~80% of the high current power planes
2023-01-18 Finished ~90% of power planes. Added cosmetic silkscreen.
2023-01-18 Power planes 99% done. Improved and added more silkscreen.
2023-01-21 Added MOSFET bi-directional level-shifters to fix I2C between INA226's and STM32F103. Fixed mismatched via sizes.
    [Quest_39.kicad_sch]
2023-01-21 Fixed all DRC warnings. Improved some silkscreen.
2023-01-21 Miscellaneous silkscreen and improved component placement. Added PCB cutout to finalize dimensions.
2023-01-22 Added shielding vias to the I2C lines that run in-between the high-current power planes
2023-01-22 Added library to add silkscreen HU and UU logos
2023-01-22 Finally figured out where to place the middle mounting hole(s)
    [Quest_39.kicad_sch]
2023-01-23 Added datasheet(s) to components for ease-of-use later
    [Quest_39.kicad_sch]
2023-01-31 Added all the SolidWorks files, edited README
    [17.5x7.5x2.SLDPRT, BUCK_0.kicad_sch, BUCK_1.kicad_sch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]

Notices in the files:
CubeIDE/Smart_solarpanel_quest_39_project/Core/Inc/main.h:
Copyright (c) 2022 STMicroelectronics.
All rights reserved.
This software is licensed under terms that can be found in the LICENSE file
